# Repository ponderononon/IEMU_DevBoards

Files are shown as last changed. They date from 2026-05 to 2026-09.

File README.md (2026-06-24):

# IEMU Development Boards - Open-source Inertial Sensor for Biomechanics

Kicad Schematic Files for the BASE and SENSOR Development Boards
(Layout in Progress)

The Sensor is a 320g IMU with a magnetometer and NAND-Flash running on a nrf54l15-Module.
The Base works as the coordinator and charger for multiple sensors also utilizing the same Module.

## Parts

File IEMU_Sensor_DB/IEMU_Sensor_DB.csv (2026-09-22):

Reference | Qty | Value | DNP | Exclude from BOM | Exclude from Board | Footprint | Datasheet | Distributor Link 1 | Distributor Link 2 | LCSC | Manufacturer_Name | Manufacturer_Part_Number | Manufactuer_Name
BT101 | 1 | Battery_Cell |  |  |  | 0_Power:CoinCell_LIR1455_LBY2 | ~
C101,C105,C109,C110 | 4 | 1u |  |  |  | Capacitor_SMD:C_0402_1005Metric | https://www.lcsc.com/datasheet/C52923.pdf | https://www.mouser.de/ProductDetail/Samsung-Electro-Mechanics/CL05A105KA5NQNC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 | https://www.digikey.de/en/products/detail/samsung-electro-mechanics/CL05A105KA5NQNC/3887103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 | C52923 | Samsung Electro-Mechanics | CL05A105KA5NQNC
C102,C206 | 2 | 2u2 |  |  |  | Capacitor_SMD:C_0402_1005Metric | https://www.lcsc.com/datasheet/C12530.pdf | https://www.mouser.de/ProductDetail/Samsung-Electro-Mechanics/CL05A225MQ5NSNC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 | https://www.digikey.de/de/products/detail/samsung-electro-mechanics/CL05A225MQ5NSNC/3887129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 | C12530 | Samsung Electro-Mechanics | CL05A225MQ5NSNC
C103,C104,C203,C204,C205 | 5 | 100n |  |  |  | Capacitor_SMD:C_0402_1005Metric | https://www.lcsc.com/datasheet/C1525.pdf | https://www.mouser.de/ProductDetail/Samsung-Electro-Mechanics/CL05B104KO5NNNC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 | https://www.digikey.de/de/products/detail/samsung-electro-mechanics/CL05B104KO5NNNC/3886659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 | C1525 | Samsung Electro-Mechanics | CL05B104KO5NNNC
C106,C107,C108,C111,C112,C201 | 6 | 10u |  |  |  | Capacitor_SMD:C_0603_1608Metric | https://weblib.samsungsem.com/mlcc/mlcc-ec-data-sheet.do?partNumber=CL10A106MA8NRN | https://www.mouser.de/ProductDetail/Samsung-Electro-Mechanics/CL10A106MA8NRNC?qs=47mY1nHWefS2vFRvRJVTdQ%3D%3D | https://www.digikey.de/de/products/detail/samsung-electro-mechanics/CL10A106MA8NRNC/3887527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 | C96446 | Samsung Electro-Mechanics | CL10A106MA8NRNC
C202 | 1 | 3p7 |  |  |  | Capacitor_SMD:C_0402_1005Metric | https://pim.murata.com/asset/pim4/ceramicCapacitorSMD/GCM1555C1H3R7CA16-01A-EN_PDF_CERAMICCAPACITORSMD | https://www.mouser.de/ProductDetail/Murata-Electronics/GCM1555C1H3R7CA16D?qs=b6dFT0v%2Fxb8E2wVH%2FN5LwA%3D%3D | https://www.digikey.de/de/products/detail/murata-electronics/GCM1555C1H3R7CA16D/4903606 | C2189484 | Murata Electronics | GCM1555C1H3R7CA16D
D101,D102,D103,D106,D110 | 5 | ESD5Z5.0T1G |  |  |  | Diode_SMD:D_SOD-523_1 | https://www.onsemi.com/pdf/datasheet/esd5z2.5t1-d.pdf | https://www.mouser.de/ProductDetail/onsemi/ESD5Z5.0T1G?qs=OSf9jACorvYw3fDx1S8P6A%3D%3D | https://www.digikey.de/de/products/detail/onsemi/ESD5Z5-0T1G/1476609 | C82044 | onsemi | ESD5Z5.0T1G
D104,D105 | 2 | PMEG3010ESBYL |  |  |  | 0_Power:DIODFN100X60X30-2N | https://assets.nexperia.com/documents/data-sheet/PMEG3010ESB.pdf | https://www.mouser.de/ProductDetail/Nexperia/PMEG3010ESBYL?qs=bel5lzaZNxQfmakdfxrTkg%3D%3D | https://www.digikey.com/en/products/detail/nexperia-usa-inc/PMEG3010ESBYL/5981362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 | C458181 | Nexperia | PMEG3010ESBYL
D107,D108,D201,D202,D203,D204,D205 | 7 | ESD9L1P8 |  |  |  | Diode_SMD:D_SOD-882 | https://diotec.com/request/datasheet/esd9l1p8.pdf | https://www.mouser.de/ProductDetail/Diotec-Semiconductor/ESD9L1P8?qs=Wj%2FVkw3K%252BMA0y9lWemTHNw%3D%3D | https://www.digikey.de/de/products/detail/diotec-semiconductor/ESD9L1P8/22192876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 | C6244607 | Diotec Semiconductor | ESD9L1P8
D109 | 1 | LTST-C19HE1WT |  |  |  | 0_Feedback:LED_LTST-C19HE1WT | https://www.mouser.de/datasheet/3/281/1/LTST_C19HE1WT.pdf | https://www.mouser.de/ProductDetail/LITEON/LTST-C19HE1WT?qs=WAWaI72GHKxJLPArJA9%252BUw%3D%3D | https://www.digikey.de/de/products/detail/liteon/LTST-C19HE1WT/3198710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 | C458749 | Lite-On Inc. | LTST-C19HE1WT
D111 | 1 | TPD1E10B06DYAR |  |  |  | Diode_SMD:D_SOD-523 | https://www.ti.com/cn/lit/ds/symlink/tpd1e10b06.pdf?ts=1777972949387 | https://www.mouser.de/ProductDetail/Texas-Instruments/TPD1E10B06DYAR?qs=Rp5uXu7WBW9%2F66n97S3Kgw%3D%3D | https://www.digikey.com/en/products/detail/texas-instruments/TPD1E10B06DYAR/15853876 | C3712135 | Texas Instruments | TPD1E10B06DYAR
D301,D302 | 2 | D_Schottky_2A_40V_0603 |  |  |  | 0_Power:0603_DSN | https://jlcpcb.com/api/file/downloadByFileSystemAccessId/8588900416898158592 | https://www.mouser.de/ProductDetail/onsemi/NSR20F40NXT5G?qs=Tr3lMbyRyKlnDYqqgtCWgQ%3D%3D | https://www.digikey.de/de/products/detail/onsemi/NSR20F40NXT5G/4848728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 | C153761 | onsemi | NSR20F40NXT5G
D303,D304,D305,D306,D307 | 5 | LTST-C191KRKT |  |  |  | 0_Feedback:LTST-C191KRKT | https://jlcpcb.com/api/file/downloadByFileSystemAccessId/8588884075830513664 | https://www.mouser.de/ProductDetail/LITEON/LTST-C191KRKT?qs=BAIUz4Y8PJBLfOhzue0q%252BA%3D%3D | https://www.digikey.de/de/products/detail/liteon/LTST-C191KRKT/386837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 | C125099 | Lite-On Electronics | LTST-C191KRKT
J101 | 1 | USB4125-GF-A |  |  |  | 0_Connectors:GCT_USB4125-GF-A_REVA2 |  | https://www.mouser.de/ProductDetail/GCT/USB4125-GF-A?qs=KUoIvG%2F9IlaIQ4zBJ6gLeA%3D%3D | https://www.digikey.de/de/products/detail/gct/USB4125-GF-A/13547388 | C3151650 | Global Connector Technology | USB4125-GF-A
J102 | 1 | DF13-4P-1.25H(21) |  |  |  | 0_Connectors:DF13-4P-1.25H(21) | https://www.mouser.de/datasheet/3/731/1/DF13_Catalog_en_DF13_CAT.pdf | https://www.mouser.de/ProductDetail/Hirose-Connector/DF13-4P-1.25H21?qs=XQjbzJWzFPW%2FwtfCjCnzBg%3D%3D | https://www.digikey.de/de/products/detail/hirose-electric-co-ltd/DF13-4P-1-25H-21/444062 | C597872 | Hirose Electric | DF13-4P-1.25H(21)
J103,J104,J105 | 3 | ~ |  |  |  | 0_Connectors:SAMTEC_MTSW-101-X-X-D-X | https://www.mouser.de/datasheet/3/85/1/mtsw.pdf | https://www.mouser.de/ProductDetail/Samtec/MTSW-101-07-T-D-240?qs=rU5fayqh%252BE3di2bgKGhLZg%3D%3D |  |  | Samtec | MTSW-101-07-T-D-240
J201 | 1 | Conn_ARM_SWD_TagConnect_TC2030-NL |  | Excluded from BOM |  | Connector:Tag-Connect_TC2030-IDC-NL_2x03_P1.27mm_Vertical | https://www.tag-connect.com/wp-content/uploads/bsk-pdf-manager/TC2030-CTX_1.pdf
J301 | 1 | Conn_01x02_Pin |  | Excluded from BOM |  | Connector_Wire:SolderWire-0.5sqmm_1x02_P4.6mm_D0.9mm_OD2.1mm | ~
L101,L102 | 2 | 2u2 |  |  |  | Inductor_SMD:L_0603_1608Metric | https://www.mouser.com/catalog/specsheets/Taiyo%20Yuden_LSC01_e.pdf | https://www.mouser.de/ProductDetail/TAIYO-YUDEN/LSCNB1608HKT2R2MD?qs=tlsG%2FOw5FFjxb8Uw3ACZFA%3D%3D | https://www.digikey.de/de/products/detail/taiyo-yuden/LSCNB1608HKT2R2MD/16668097 | C6079477 | TAIYO YUDEN | LSCNB1608HKT2R2MD
M401 | 1 | VZ43FM1B8230001L |  |  |  | 0_Feedback:XDCR_VZ43FM1B8230001L | https://www.vybronics.com/wp-content/uploads/datasheet-files/Vybronics-VZ43FM1B8230001L-datasheet.pdf |  | https://www.digikey.de/de/products/detail/vybronics-inc/VZ43FM1B8230001L/12323592 | C7467059 | Vybronics | VZ43FM1B8230001L
MH301,MH302,MH303,MH304 | 4 | MountingHole_Pad |  | Excluded from BOM |  | MountingHole:MountingHole_2.2mm_M2_Pad_Via | ~
Q101 | 1 | CSD85301Q2 |  |  |  | 0_Power:CSD85301Q2 | http://www.ti.com/lit/gpn/csd85301q2 | https://www.mouser.de/ProductDetail/Texas-Instruments/CSD85301Q2?qs=jXf%2FRVhl83aWTrZoPmx2cQ%3D%3D | https://www.digikey.de/de/products/detail/texas-instruments/CSD85301Q2/5114820 | C544396 | Texas Instruments | CSD85301Q2
Q301,Q302,Q303,Q304 | 4 | CSD13381F4 |  |  |  | 0_Power:DFN100X60X35-3N | https://www.ti.com/lit/ds/symlink/csd13381f4.pdf | https://www.mouser.de/ProductDetail/Texas-Instruments/CSD13381F4?qs=OGNXFUZBARsOFU3S%252BJVO5g%3D%3D | https://www.digikey.com/en/products/detail/texas-instruments/CSD13381F4/4437947 | C179868 | Texas Instruments | CSD13381F4
R101,R206 | 2 | 10k |  |  |  | Resistor_SMD:R_0402_1005Metric | https://www.lcsc.com/datasheet/C25744.pdf | https://www.mouser.de/ProductDetail/Royalohm/0402WGF1002TCE?qs=e8oIoAS2J1T9%2FSfQTy4YqQ%3D%3D |  | C25744 | UNI-ROYAL(Uniroyal Elec) | 0402WGF1002TCE
R102,R103,R203,R204,R205 | 5 | 47k |  |  |  | Resistor_SMD:R_0402_1005Metric | https://www.royalohm.com/assets/pdf/products/smd/1.pdf | https://www.mouser.de/ProductDetail/Royalohm/0402WGF4702TCE?qs=e8oIoAS2J1Slykd2t52jeA%3D%3D |  | C25792 | UNI-ROYAL(Uniroyal Elec) | 0402WGF4702TCE
R104 | 1 | 330 |  |  |  | Resistor_SMD:R_0402_1005Metric | https://www.royalohm.com/assets/pdf/products/smd/1.pdf | https://www.mouser.de/ProductDetail/Royalohm/0402WGF3300TCE?qs=e8oIoAS2J1Sur8hPOE5m4w%3D%3D |  | C25104 | UNI-ROYAL(Uniroyal Elec) | 0402WGF3300TCE
R105,R106 | 2 | 5M1 |  |  |  | Resistor_SMD:R_0402_1005Metric | https://www.lcsc.com/datasheet/C137855.pdf | https://www.mouser.de/ProductDetail/YAGEO/RC0402JR-075M1L?qs=0yPvnVz5%2Fmq%2FK6XQD6hVkQ%3D%3D | https://www.digikey.de/de/products/detail/yageo/RC0402JR-075M1L/5281166 | C137855 | YAGEO | RC0402JR-075M1L
R107,R207,R208 | 3 | 2k2 |  |  |  | Resistor_SMD:R_0402_1005Metric | https://www.lcsc.com/datasheet/C25879.pdf | https://www.mouser.de/ProductDetail/Royalohm/0402WGF2201TCE?qs=e8oIoAS2J1QvBi%2FbAiHH2g%3D%3D |  | C25879 | UNI-ROYAL(Uniroyal Elec) | 0402WGF2201TCE
R108 | 1 | R_Shunt_1R |  |  |  | Resistor_SMD:R_0402_1005Metric | https://www.te.com/commerce/DocumentDelivery/DDEController?Action=srchrtrv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 | https://www.mouser.de/ProductDetail/TE-Connectivity-Holsworthy/RLP73K1E1R0FTDF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 | https://www.digikey.com/en/products/detail/te-connectivity-passive-product/RLP73K1E1R0FTDF/4031931 | C2074826 | TE Connectivity | RLP73K1E1R0FTDF
R109,R110,R201,R304,R305 | 5 | 1k |  |  |  | Resistor_SMD:R_0402_1005Metric | https://www.royalohm.com/assets/pdf/products/smd/1.pdf | https://www.mouser.de/ProductDetail/Royalohm/0402WGF1001TCE?qs=e8oIoAS2J1RlrMC0w7DkrQ%3D%3D |  | C11702 | UNI-ROYAL(Uniroyal Elec) | 0402WGF1001TCE
R111 | 1 | 510k |  |  |  | Resistor_SMD:R_0603_1608Metric | https://jlcpcb.com/api/file/downloadByFileSystemAccessId/8579706282724544512 | https://www.mouser.de/ProductDetail/Royalohm/0603WAF5103T5E?qs=e8oIoAS2J1SG1joTiM6RHg%3D%3D |  | C23192 | UNI-ROYAL(Uniroyal Elec) | 0603WAF5103T5E
R112,R209 | 2 | 1M |  |  |  | Resistor_SMD:R_0402_1005Metric | https://jlcpcb.com/api/file/downloadByFileSystemAccessId/8579705944068186112 | https://www.mouser.de/ProductDetail/Royalohm/0402WGF1004TCE?qs=e8oIoAS2J1Sm8qYhjADD%252Bg%3D%3D |  | C26083 | UNI-ROYAL(Uniroyal Elec) | 0402WGF1004TCE
R202 | 1 | 22R |  |  |  | Resistor_SMD:R_0603_1608Metric | https://www.royalohm.com/assets/pdf/products/smd/1.pdf | https://www.mouser.de/ProductDetail/Royalohm/0603WAF220JT5E?qs=e8oIoAS2J1QaFtl9BkMMvg%3D%3D |  | C23345 | UNI-ROYAL(Uniroyal Elec) | 0603WAF220JT5E
R301,R302,R303 | 3 | 330R |  |  |  | Resistor_SMD:R_0402_1005Metric | https://www.royalohm.com/assets/pdf/products/smd/1.pdf | https://www.mouser.de/ProductDetail/Royalohm/0402WGF3300TCE?qs=e8oIoAS2J1Sur8hPOE5m4w%3D%3D |  | C25104 | UNI-ROYAL(Uniroyal Elec) | 0402WGF3300TCE
SW301 | 1 | NANOT_160_BP |  |  |  | 0_Feedback:NANOT160BP | https://www.littelfuse.com/assetdocs/littelfuse-ck-tactile-nanot-series-datasheet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 |  | https://www.digikey.com/en/products/detail/c-k/NANOT-160-BP/13182296 | C2760983 | C&K | NANOT160BP
SW302 | 1 | TS-1088-AR02016 |  |  |  | 0_Feedback:SW_TS-1088-AR02016 | https://jlcpcb.com/api/file/downloadByFileSystemAccessId/8588886944068096000 |  |  | C720477 | Xunpu | TS-1088-AR02016
TP101,TP102,TP103,TP104,TP105,TP106,TP107,TP108,TP109,TP110,TP111,TP112,TP113,TP114,TP201,TP202,TP203,TP204,TP205,TP206,TP207,TP208,TP209,TP301,TP302,TP303,TP304 | 27 | ~ |  |  |  | TestPoint:TestPoint_Pad_D1.0mm | ~
U101 | 1 | NPM1304-QEAA-R7 |  |  |  | 0_Power:QFN50P500X500X90-33N | https://docs-be.nordicsemi.com/bundle/ps_npm1304/page/pdf/nPM1304_Datasheet_v1.0.pdf | https://eu.mouser.com/ProductDetail/Nordic-Semiconductor/NPM1304-QEAA-R7?qs=HMhDvBYWqvMvY7CcdLXd6A%3D%3D | https://www.digikey.de/de/products/detail/nordic-semiconductor-asa/NPM1304-QEAA-R7/27258987 | C49448846 | Nordic Semiconductor | NPM1304-QEAA-R7
U102 | 1 | BQ29702DSER |  |  |  | Package_SON:WSON-6_1.5x1.5mm_P0.5mm | https://www.ti.com/lit/ds/symlink/bq2972.pdf?ts=1774781812663 | https://www.mouser.de/ProductDetail/Texas-Instruments/BQ29702DSER?qs=m1T3c8F5IUKBpJHU0Ofy6w%3D%3D | https://www.digikey.de/de/products/detail/texas-instruments/BQ29702DSER/4899787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 | C2872632 | Texas Instruments | BQ29702DSER
U103 | 1 | TLV75530PDRVR |  |  |  | Package_SON:WSON-6-1EP_2x2mm_P0.65mm_EP1x1.6mm_ThermalVias | https://www.ti.com/lit/ds/symlink/tlv755p.pdf?ts=1775941132628 | https://www.mouser.de/ProductDetail/Texas-Instruments/TLV75530PDRVR?qs=lc2O%252BfHJPVbdo827uajLog%3D%3D | https://www.digikey.com/en/products/detail/texas-instruments/TLV75530PDRVR/9649791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 | C2859948 | Texas Instruments | TLV75530PDRVR
U104 | 1 | INA216A2RSWR |  |  |  | Package_DFN_QFN:Texas_RSW0010A_UQFN-10_1.4x1.8mm_P0.4mm | https://www.ti.com/lit/ds/symlink/ina216.pdf | https://www.mouser.de/ProductDetail/Texas-Instruments/INA216A2RSWR?qs=NUb82WqeCyoQa96oQgyXng%3D%3D | https://www.digikey.com/en/products/detail/texas-instruments/INA216A2RSWR/2782696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 | C2653823 | Texas Instruments | INA216A2RSWR
U201 | 1 | Ezurio BL54L15 |  |  |  | 0_MCU:BL54L15 | https://www.ezurio.com/documentation/datasheet-bl54l10-and-bl54l15-series | https://mouser.com/ProductDetail/Ezurio/453-00001C?qs=a2MtRaTmNOR8OxAR96ozSQ%3D%3D | https://www.digikey.de/de/products/detail/ezurio/453-00001R/26224840?s=N4IgTCBcDaICwFYDMBaADBtBGAwiAugL5A |  | EZURIO | 453-00001C
U202 | 1 | W25N02JWZEIF |  |  |  | 0_Memory:IC_W25N04KVZEIR | https://www.winbond.com/resource-files/W25N02JW_RevA_191118.pdf | https://www.mouser.de/ProductDetail/Winbond/W25N02JWZEIF?qs=T3oQrply3y%2FzgvrcpLTu6Q%3D%3D | https://www.digikey.com/en/products/detail/winbond-electronics/W25N02JWZEIF/12143373 | C2962014 | Winbond | W25N02JWZEIF
U203 | 1 | LSM6DSV320XTR |  |  |  | Package_LGA:LGA-14_3x2.5mm_P0.5mm_LayoutBorder3x4y | https://www.st.com/resource/en/datasheet/lsm6dsv320x.pdf | https://www.mouser.de/ProductDetail/STMicroelectronics/LSM6DSV320XTR?qs=ZcfC38r4PovtVvaAitDAYA%3D%3D | https://www.digikey.de/de/products/detail/stmicroelectronics/lsm6dsv320xtr/26254547 | C26633007 | STMicroelectronics | LSM6DSV320XTR
U204 | 1 | MMC5603NJ |  |  |  | 0_Sensors:MMC5603NJ | https://www.memsic.com/Public/Uploads/uploadfile/files/20220119/MMC5603NJDatasheetRev.B.pdf | https://www.mouser.de/ProductDetail/MEMSIC/MMC5603NJ?qs=B6kkDfuK7%2FDOubZFFHvcXw%3D%3D | https://www.digikey.de/de/products/detail/memsic-inc/MMC5603NJ/10452796 | C404328 | MEMSIC | MMC5603NJ
Y201 | 1 | 32.768kHz |  |  |  | Crystal:Crystal_SMD_3215-2Pin_3.2x1.5mm | https://mm.digikey.com/Volume0/opasdata/d220001/medias/docus/7329/SC-32S.pdf |  | https://www.digikey.com/en/products/detail/seiko-instruments/SC32S-9PF20PPM/15296600 | C97605 | Seiko | SC-32S32.768kHz20PPM9pF

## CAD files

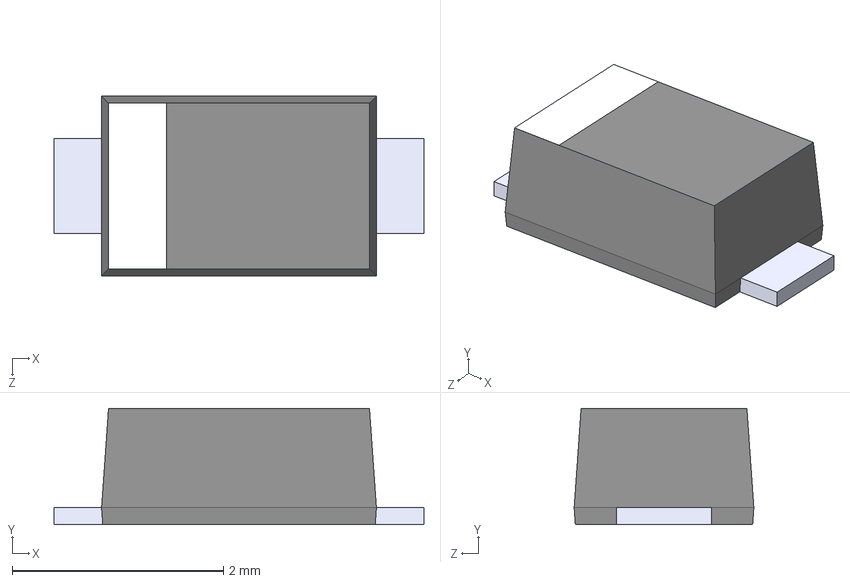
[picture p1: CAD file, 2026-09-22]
IEMU_Shared_Libraries/3D/PMEG3010ER-115--3DModel-STEP-56544.STEP
3.50 x 1.10 x 1.70 mm

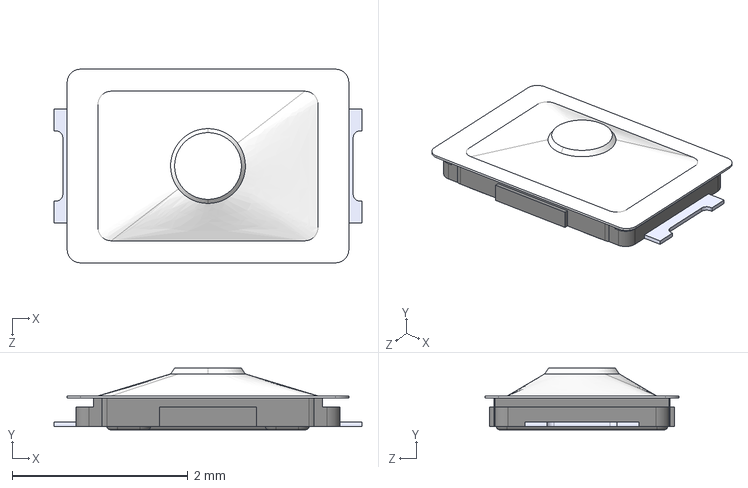
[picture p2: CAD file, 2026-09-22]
IEMU_Shared_Libraries/3D/EVP-AWED4A.step
3.50 x 0.7 x 2.20 mm

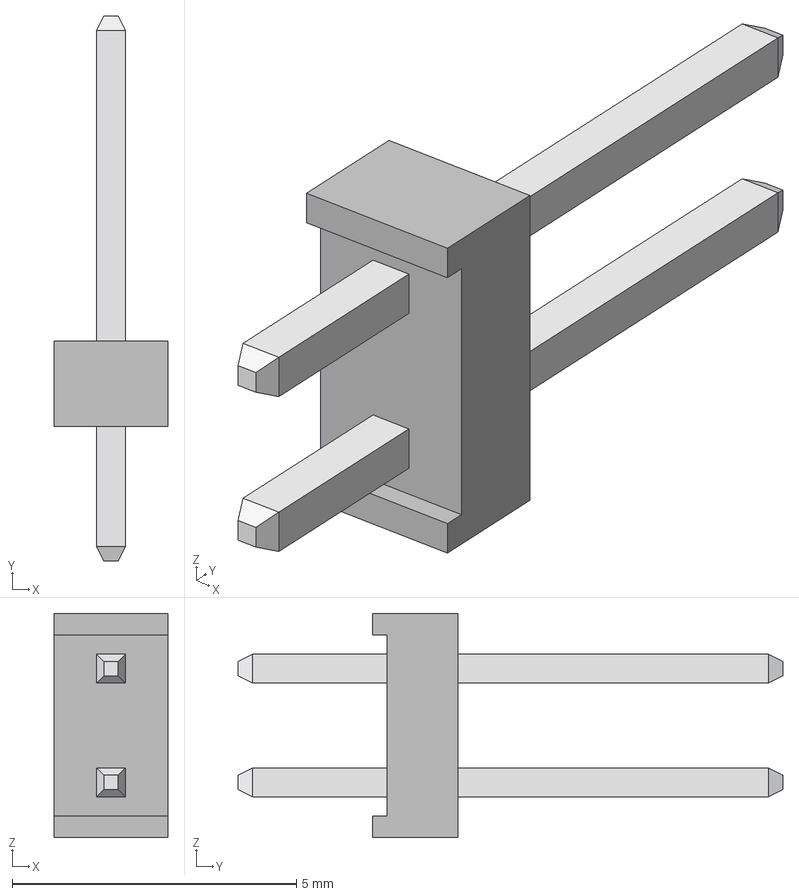
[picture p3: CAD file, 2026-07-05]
IEMU_Shared_Libraries/3D/MTMM-101-05-T-D-225.stp
2.00 x 9.58 x 3.94 mm
MTMM-101-05-T-D-225_pins
MTMM-101-05-T-D-225_body

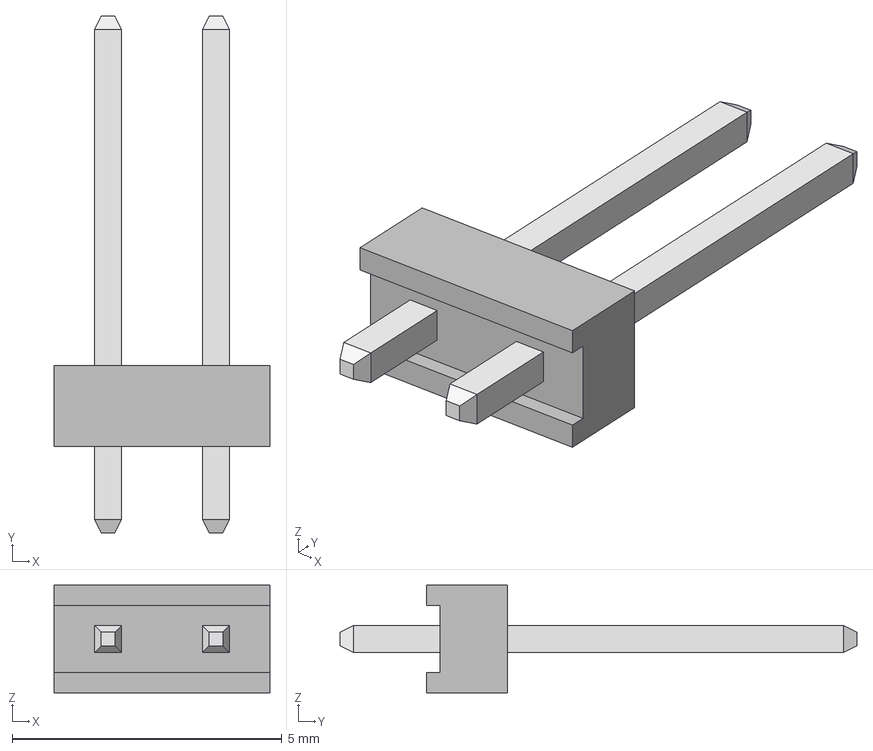
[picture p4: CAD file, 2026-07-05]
IEMU_Shared_Libraries/3D/MTMM-102-05-T-S-255.stp
4.00 x 9.58 x 2.00 mm
MTMM-102-05-T-S-255_pins
MTMM-102-05-T-S-255_body

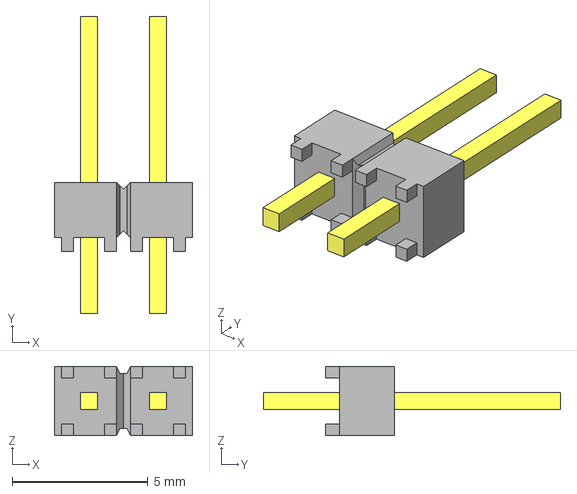
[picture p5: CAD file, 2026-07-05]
IEMU_Shared_Libraries/3D/MTSW-102-07-G-S-240.step
5.08 x 10.9 x 2.54 mm
MTSW-102-07-G-S-240_body
MTSW-102-07-S-240

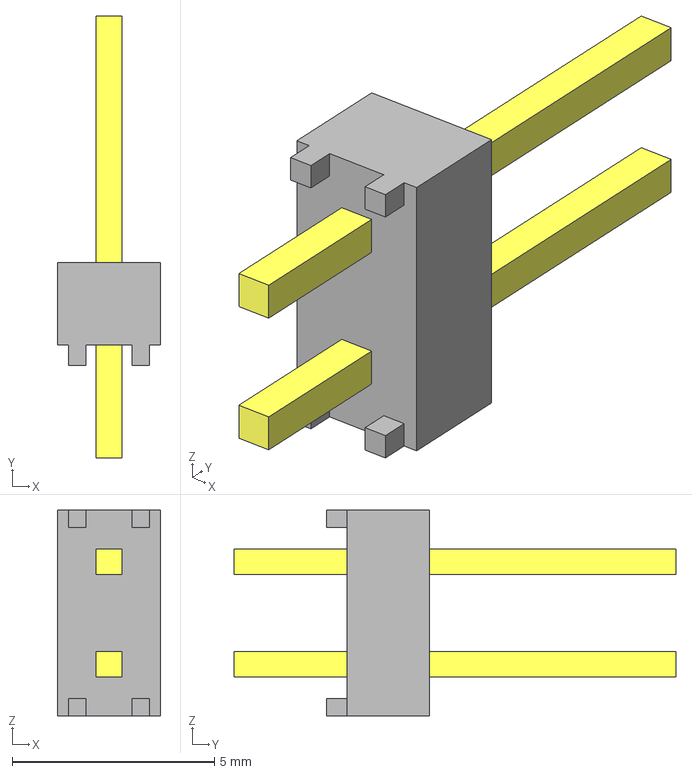
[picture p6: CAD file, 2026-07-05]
IEMU_Shared_Libraries/3D/MTSW-101-07-T-D-240.stp
2.54 x 10.9 x 5.08 mm
MTSW-101-07-T-D-240_body
MTSW-101-07-D-240

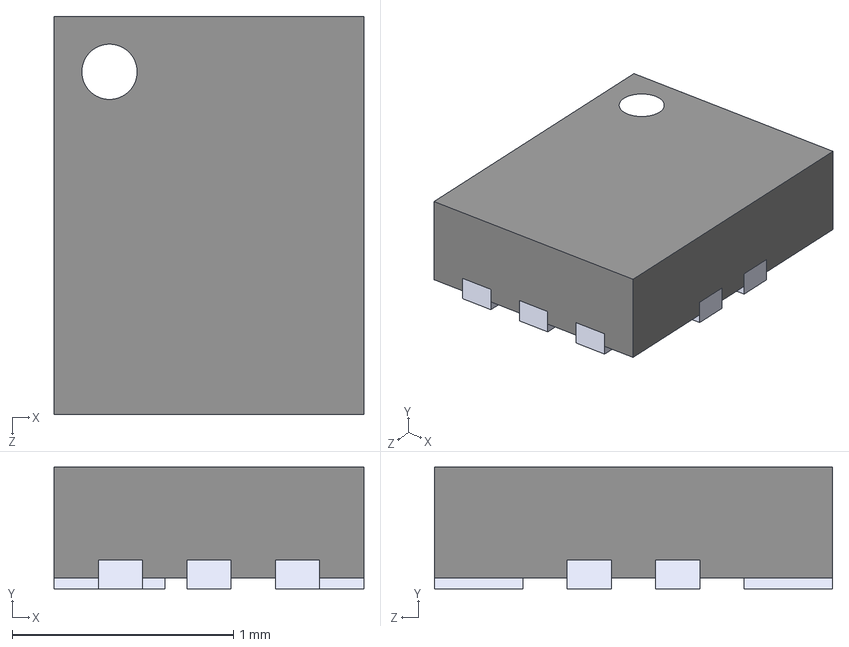
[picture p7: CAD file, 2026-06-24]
IEMU_Shared_Libraries/3D/INA216A2RSWR.STEP
1.40 x 0.55 x 1.80 mm

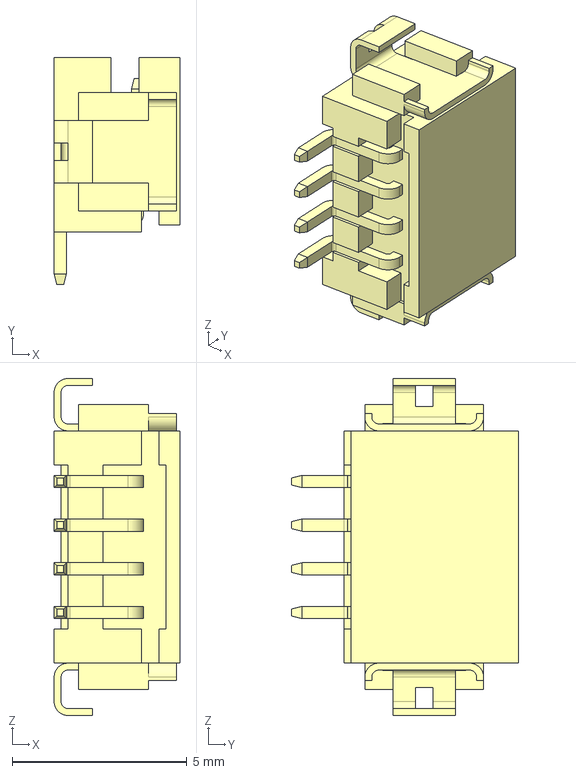
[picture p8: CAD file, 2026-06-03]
IEMU_Shared_Libraries/3D/DF13-4P-1.25H_21_.stp
3.60 x 6.50 x 9.65 mm

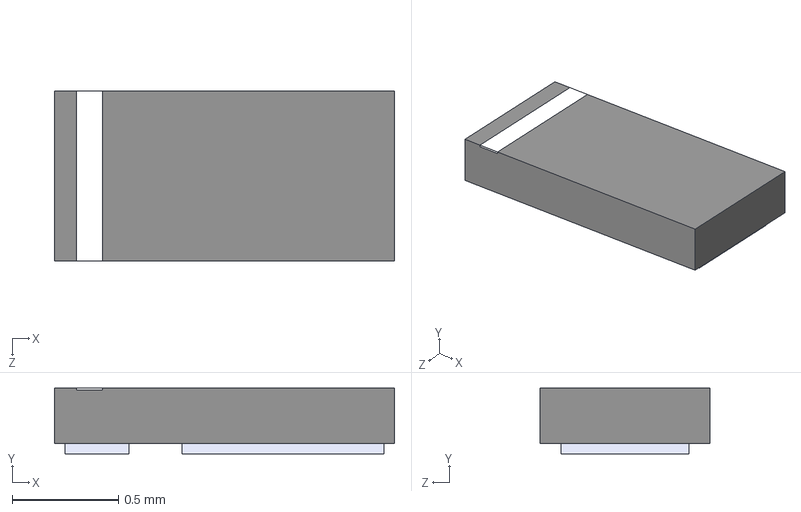
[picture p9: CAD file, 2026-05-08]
IEMU_Shared_Libraries/3D/NSR20F40NXT5G.STEP
1.60 x 0.31 x 0.8 mm

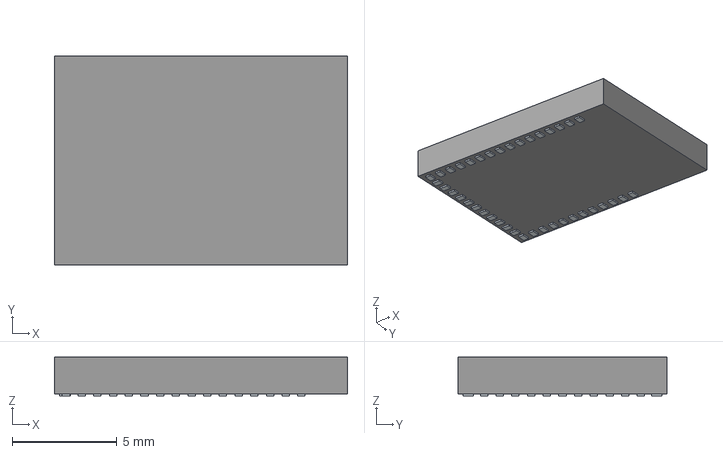
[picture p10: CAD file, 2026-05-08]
IEMU_Shared_Libraries/3D/453-00001C.stp
14.0 x 10.0 x 1.85 mm
Pins

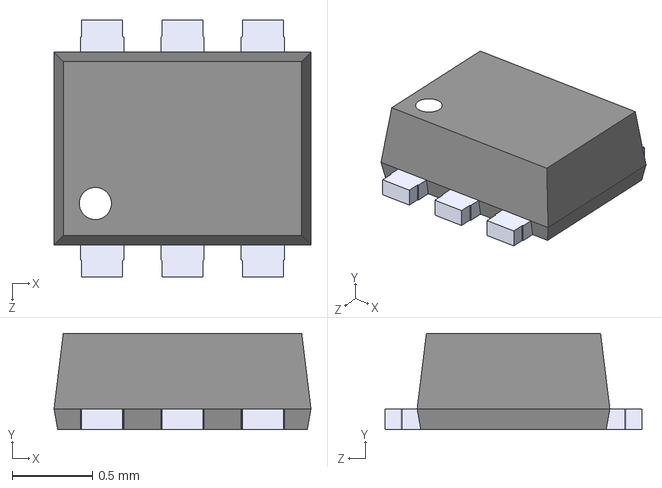
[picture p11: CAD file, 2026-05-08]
IEMU_Shared_Libraries/3D/USBLC6-2P6.step
1.60 x 0.6 x 1.60 mm

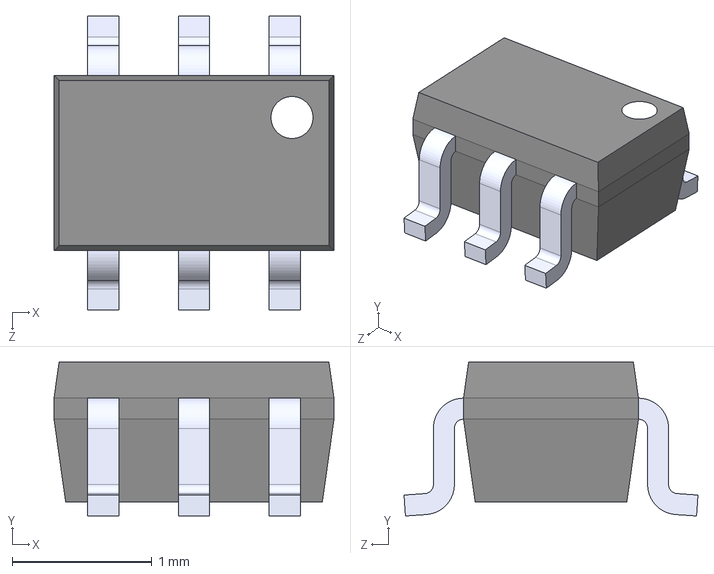
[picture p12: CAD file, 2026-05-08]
IEMU_Shared_Libraries/3D/SN74LVC1T45DCKRG4.step
2.00 x 1.10 x 2.10 mm

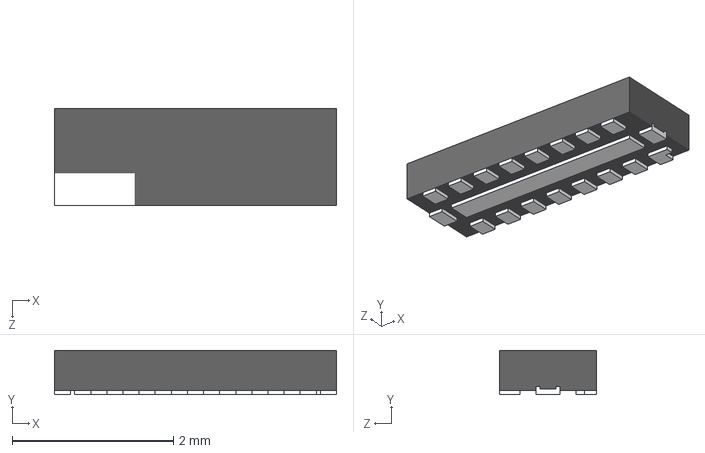
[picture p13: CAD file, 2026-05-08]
IEMU_Shared_Libraries/3D/EMIF06-MSD02N16.stp
3.50 x 0.55 x 1.20 mm

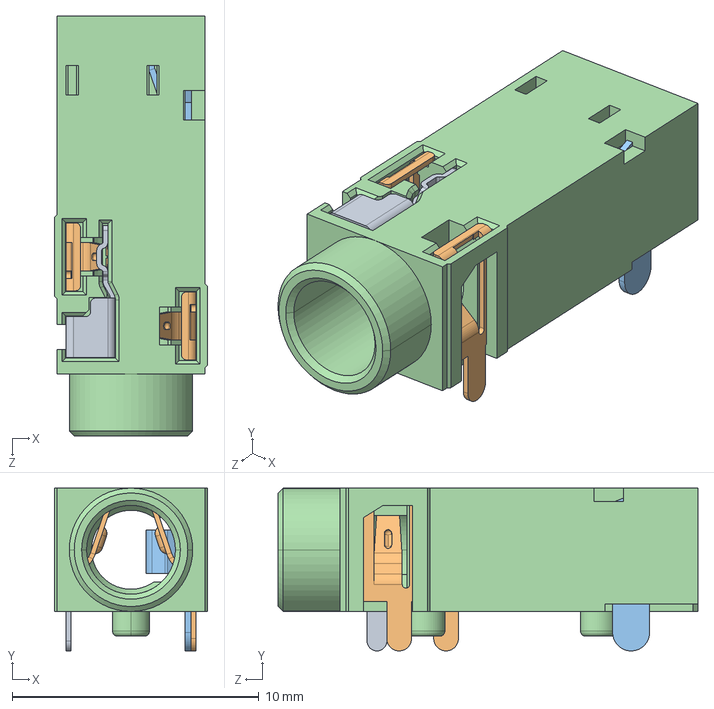
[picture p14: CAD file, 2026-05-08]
IEMU_Shared_Libraries/3D/SJ3-35083C-TR.step
6.20 x 6.60 x 17.0 mm

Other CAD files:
IEMU_Shared_Libraries/3D/MTSW-102-07-L-S-189.stp
IEMU_Shared_Libraries/3D/MTSW-102-07-L-S-240.stp
IEMU_Shared_Libraries/3D/TMUX1204DQAR.step
IEMU_Shared_Libraries/3D/SJ3-35083B-TR.step
IEMU_Shared_Libraries/3D/503398-1892.step
IEMU_Shared_Libraries/3D/BQ29702DSER.step
IEMU_Shared_Libraries/3D/CSD13381F4.step
IEMU_Shared_Libraries/3D/CSD85301Q2.STEP
IEMU_Shared_Libraries/3D/DF13-4P-1.25H_75_.step
IEMU_Shared_Libraries/3D/LTST-C191KRKT.step
IEMU_Shared_Libraries/3D/LTST-C19HE1WT.step
IEMU_Shared_Libraries/3D/MMC5603NJ.stp
IEMU_Shared_Libraries/3D/NANOT160BP.stp
IEMU_Shared_Libraries/3D/NPM1304-QEAA-R7.step
IEMU_Shared_Libraries/3D/PMEG3010ESBYL.step
IEMU_Shared_Libraries/3D/TS-1088-AR02016.step
IEMU_Shared_Libraries/3D/USB4125-GF-A_REVA2.step
IEMU_Shared_Libraries/3D/USB4215-03-A.stp
IEMU_Shared_Libraries/3D/VZ43FM1B8230001L.step
IEMU_Shared_Libraries/3D/W25N04KVZEIR.step

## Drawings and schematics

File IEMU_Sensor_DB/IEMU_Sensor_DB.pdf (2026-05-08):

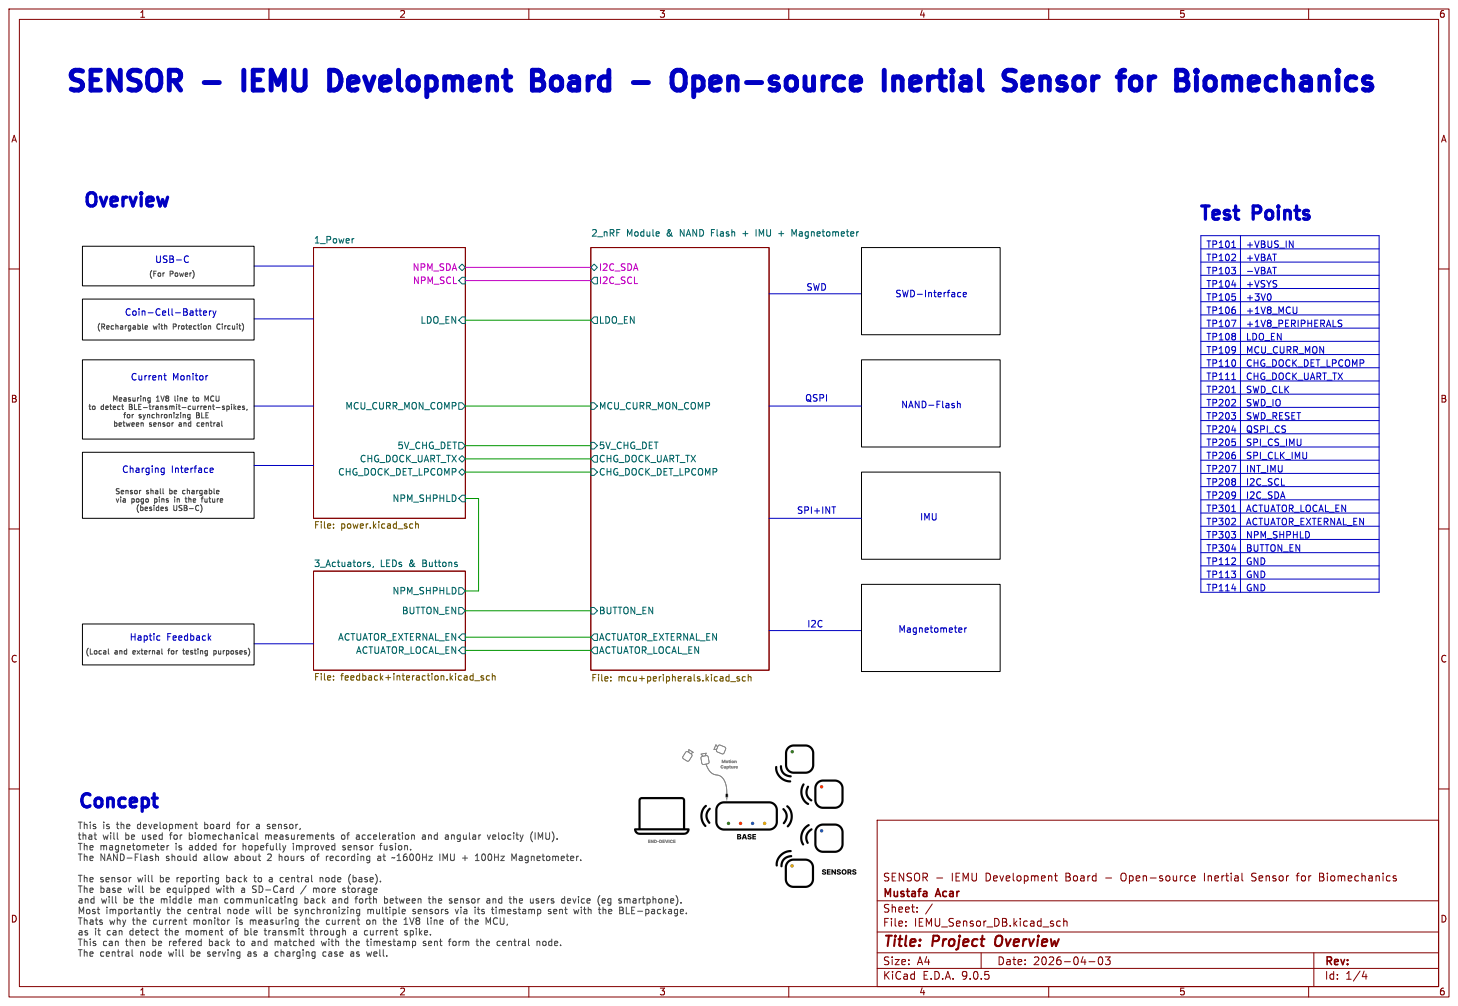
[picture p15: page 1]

2_nRF Module & NAND Flash + IMU + Magnetometer File: mcu+peripherals.kicad_sch NPM_SHPHLD

between sensor and central Current Monitor Sensor shall be chargable

to detect BLE-transmit-current-spikes,

via pogo pins in the future

Id: 1/4 Title: Project Overview

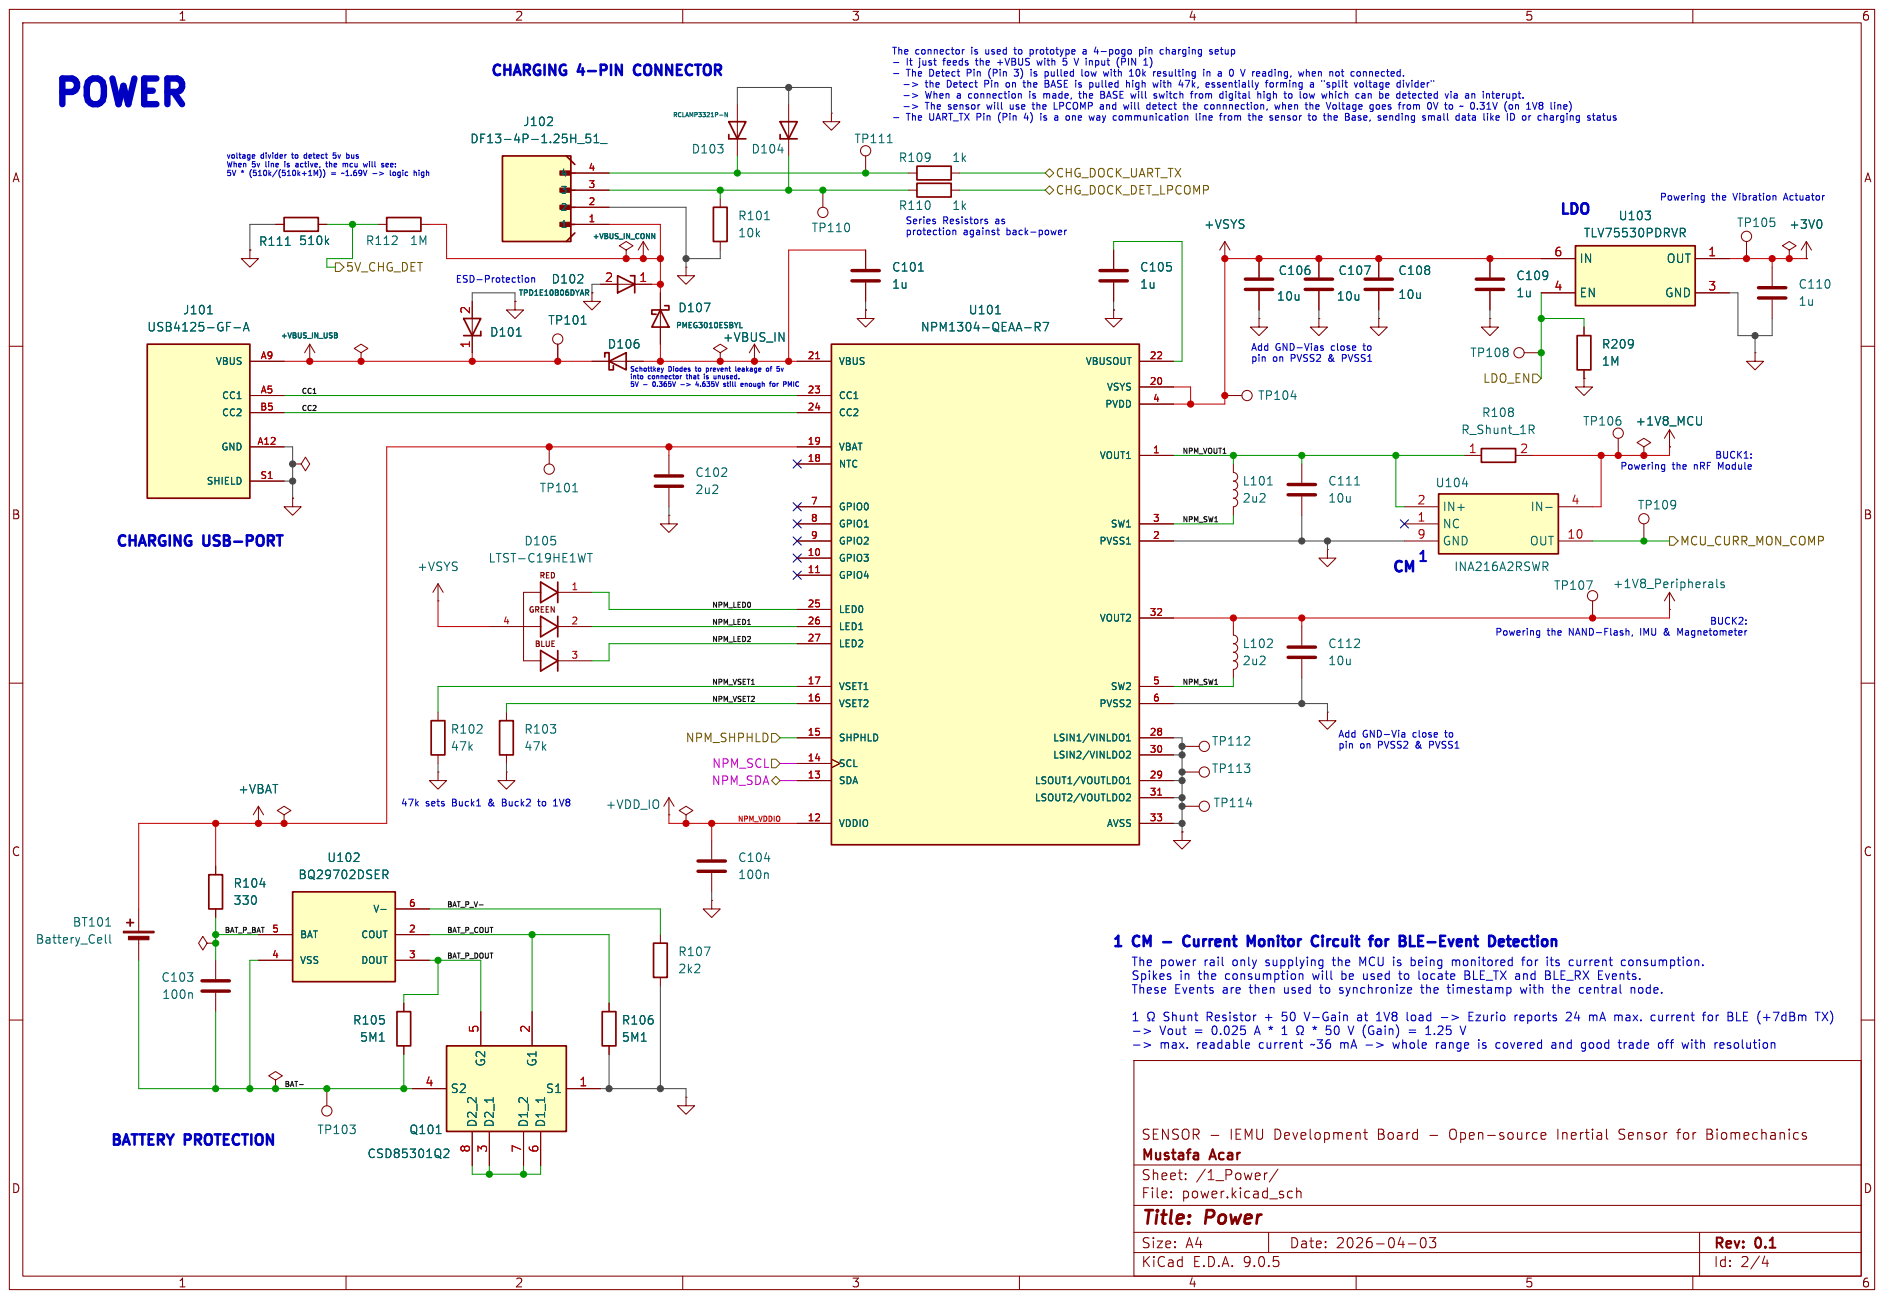
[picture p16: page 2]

- It just feeds the +VBUS with 5 V input (PIN 1)

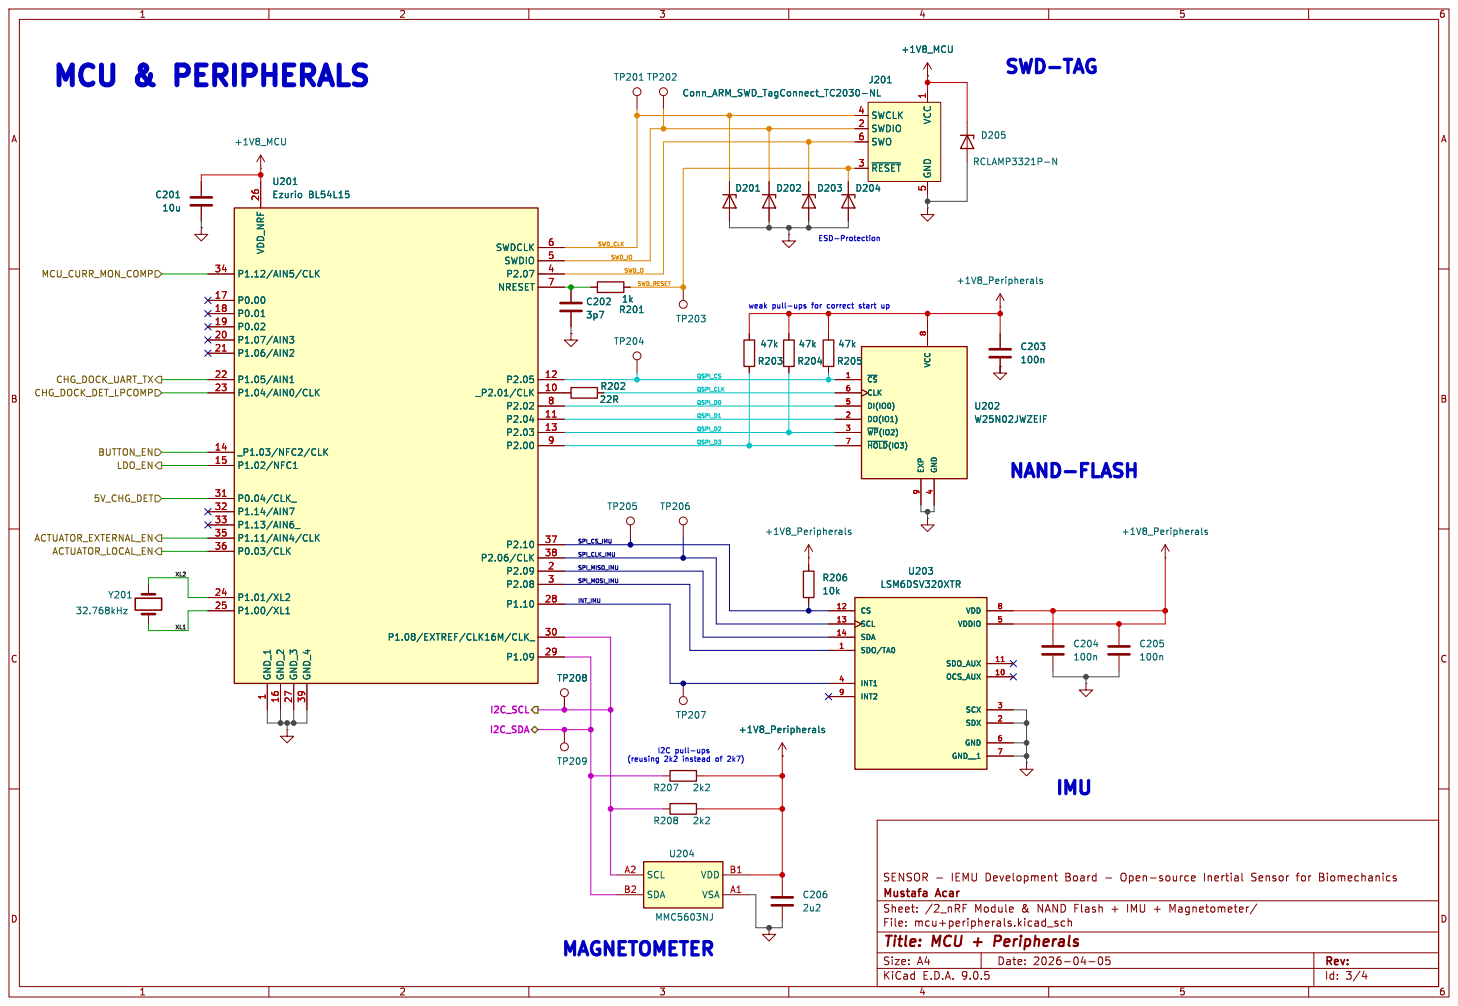
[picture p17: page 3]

5 SWCLK 4 SWDIO 2 SWO 6 ~{RESET} 3 +1V8_MCU

5 SWCLK 4 SWDIO 2 SWO 6 ~{RESET} 3

8 ~{CS} 1 CLK 6 DI(IO0) 5 DO(IO1) 2 ~{WP}(IO2) 3 ~{HOLD}(IO3) 7 GND

Id: 3/4 Title: MCU + Peripherals

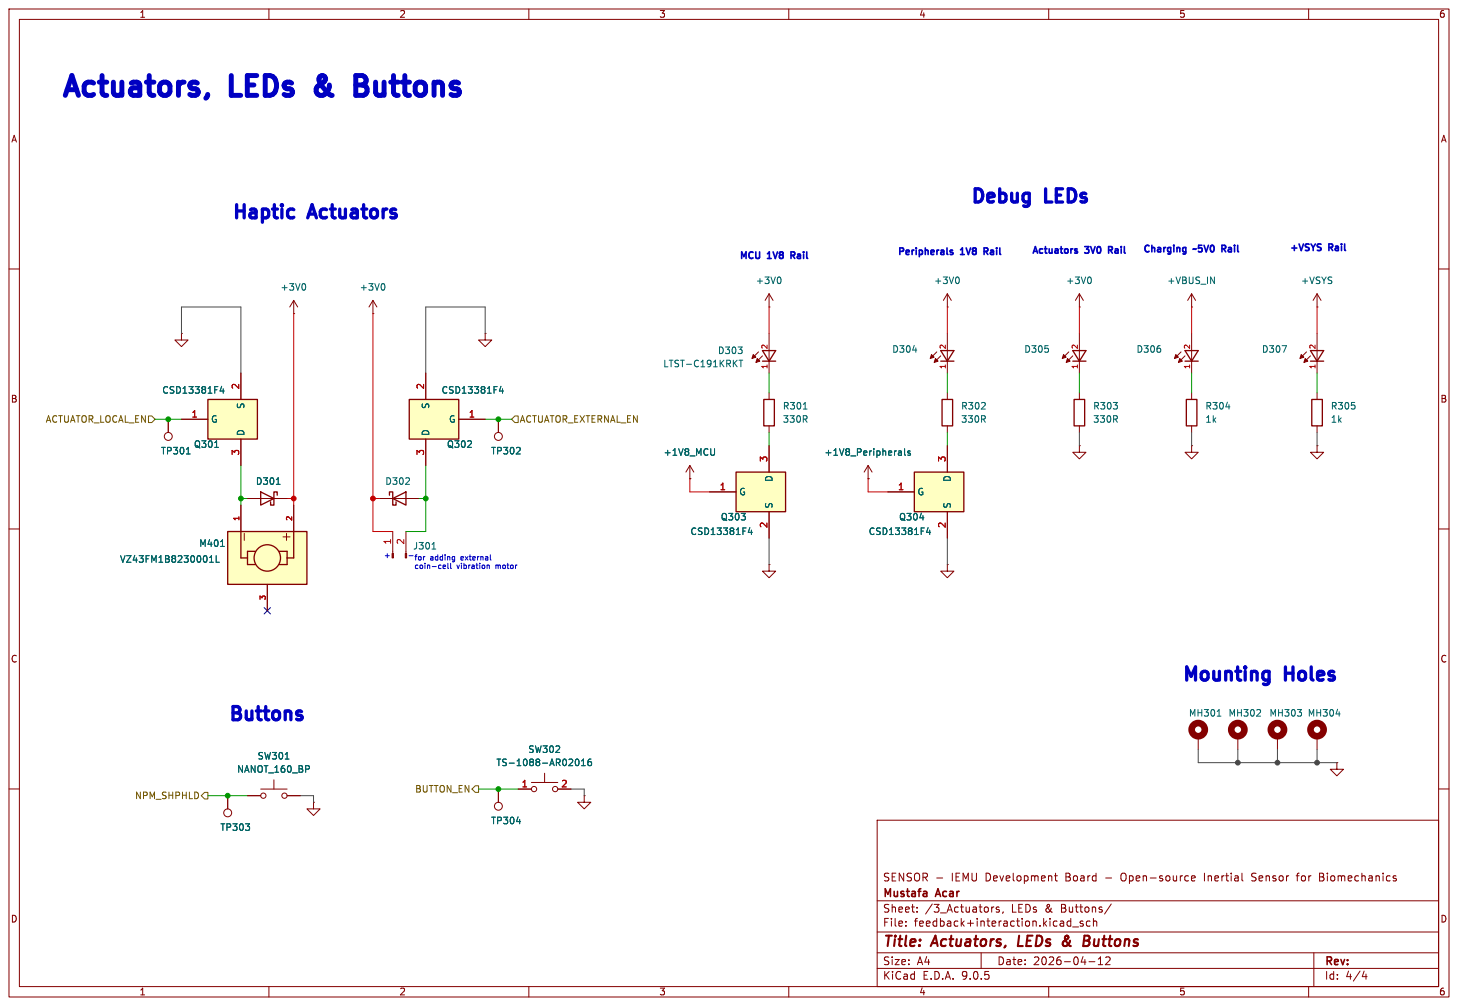
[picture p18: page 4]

Actuators 3V0 Rail Haptic Actuators

- Charging ~5V0 Rail Mounting Holes

Id: 4/4 Title: Actuators, LEDs & Buttons

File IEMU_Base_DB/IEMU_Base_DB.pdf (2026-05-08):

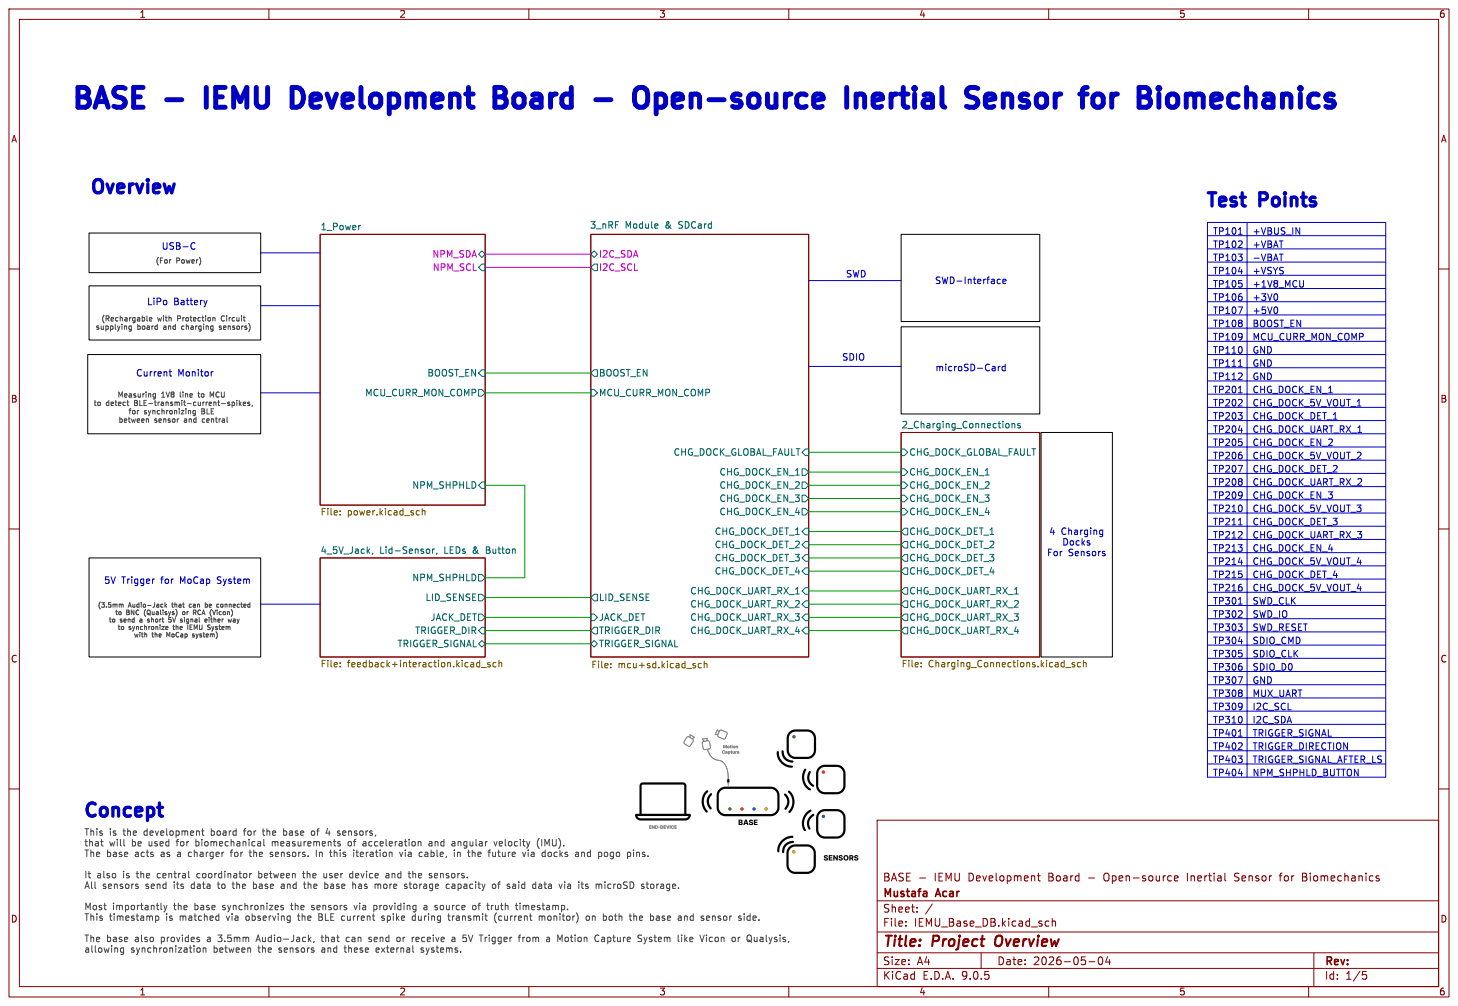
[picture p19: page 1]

3_nRF Module & SDCard File: mcu+sd.kicad_sch NPM_SHPHLD

to detect BLE-transmit-current-spikes,

between sensor and central 5V Trigger for MoCap System

with the MoCap system) Concept

Id: 1/5 Title: Project Overview

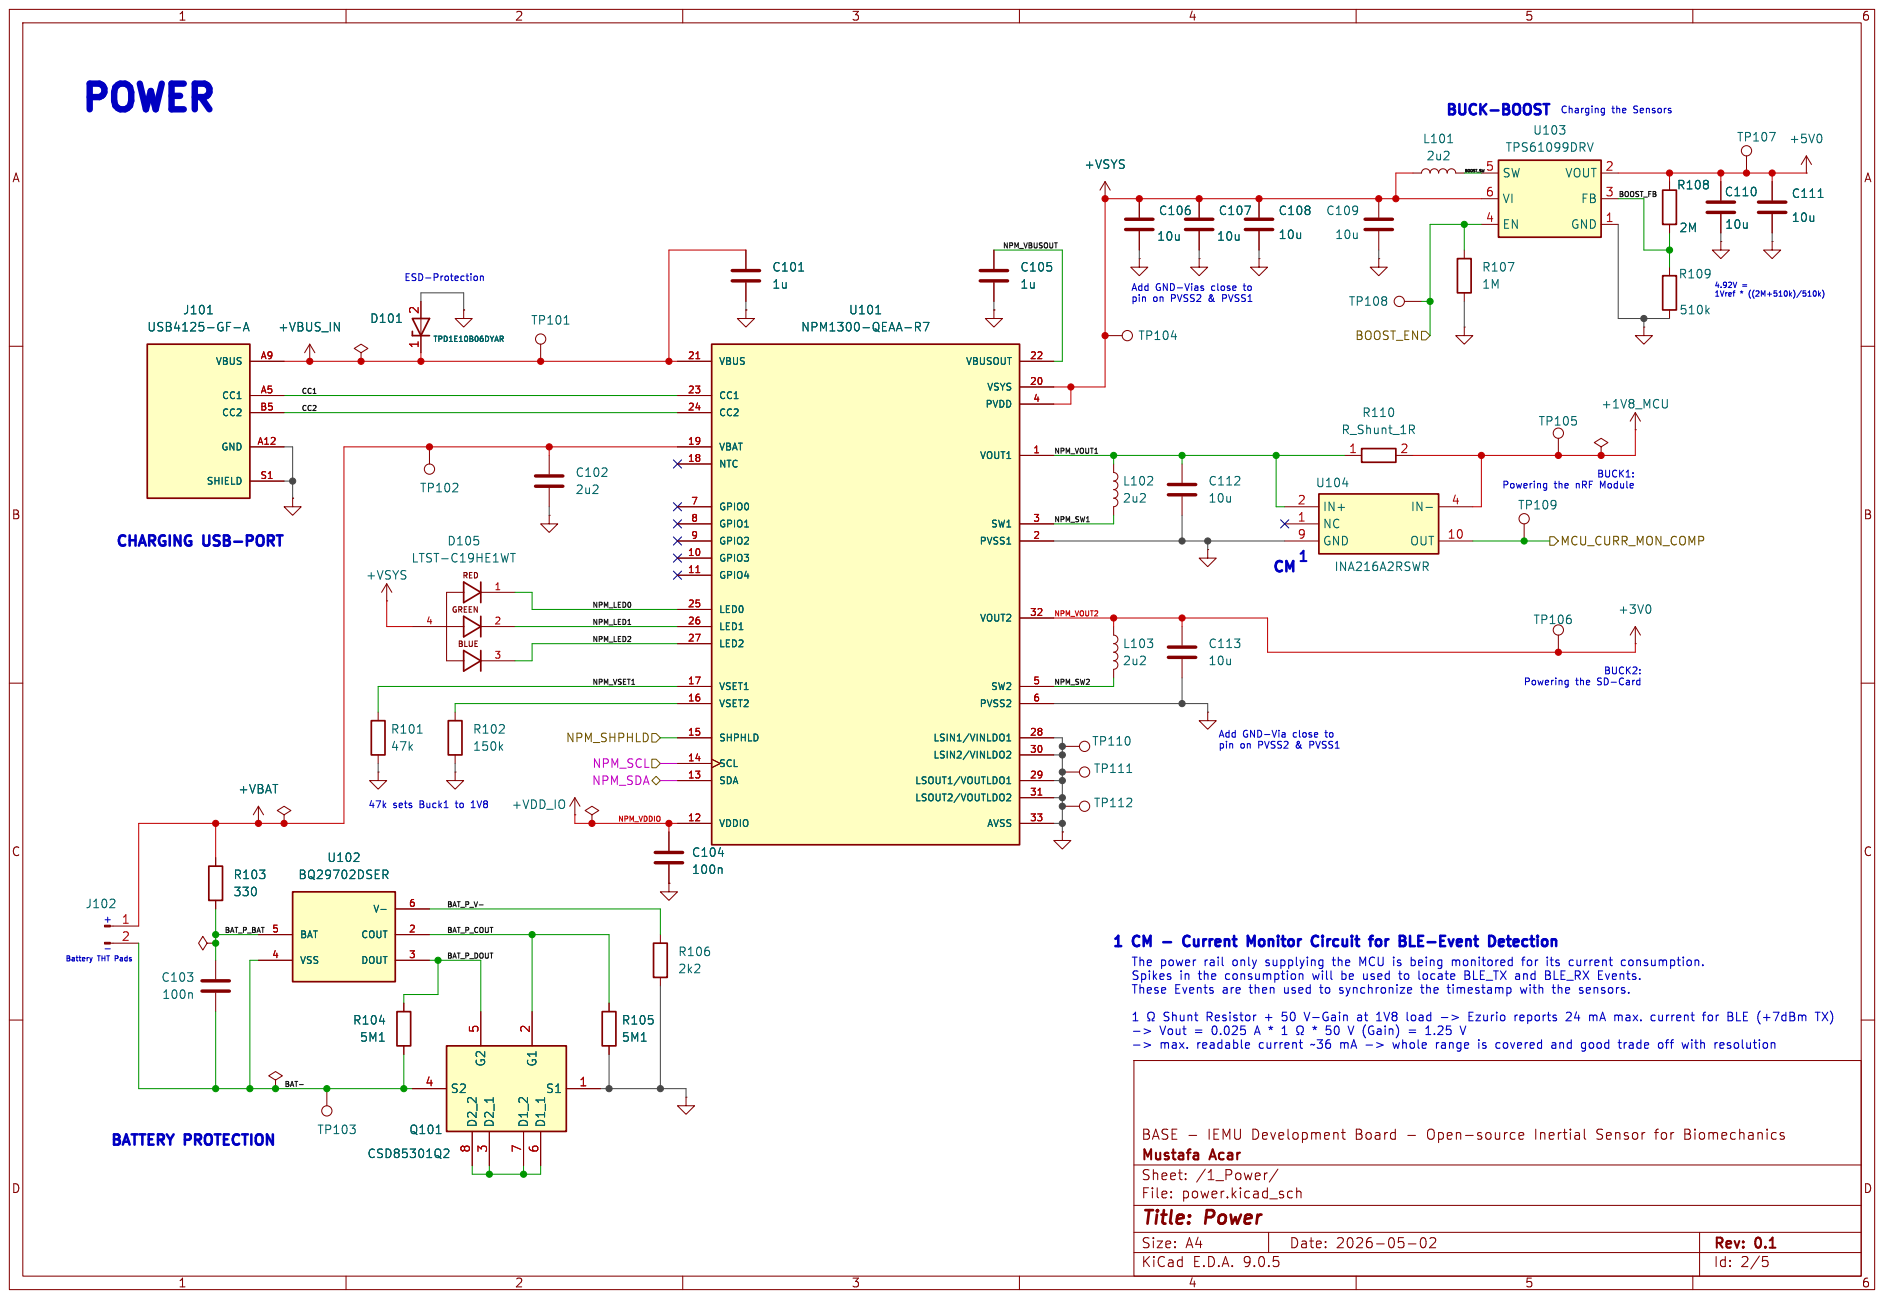
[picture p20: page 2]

pin on PVSS2 & PVSS1 CHARGING USB-PORT

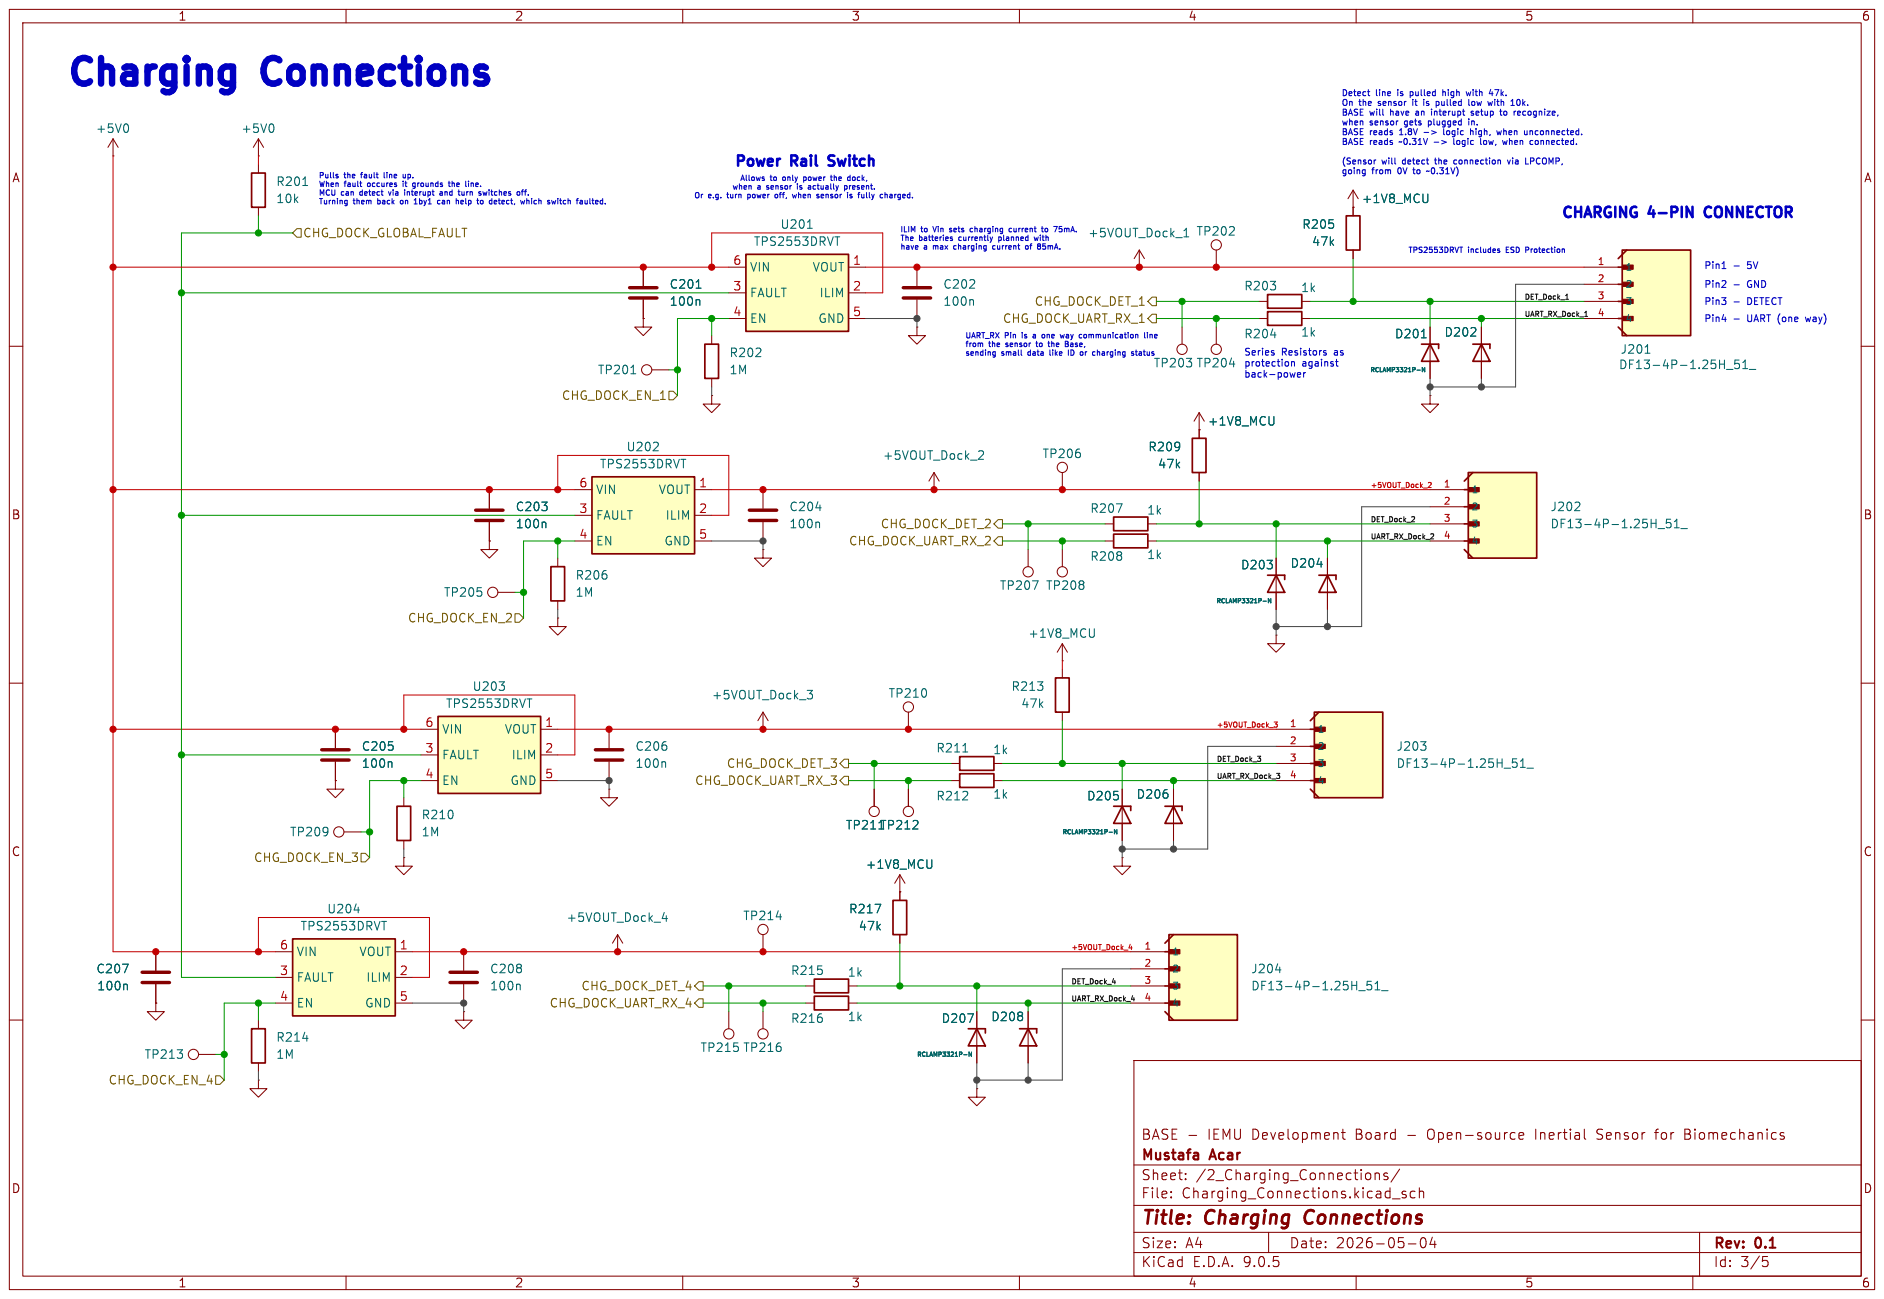
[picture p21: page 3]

Id: 3/5 Title: Charging Connections

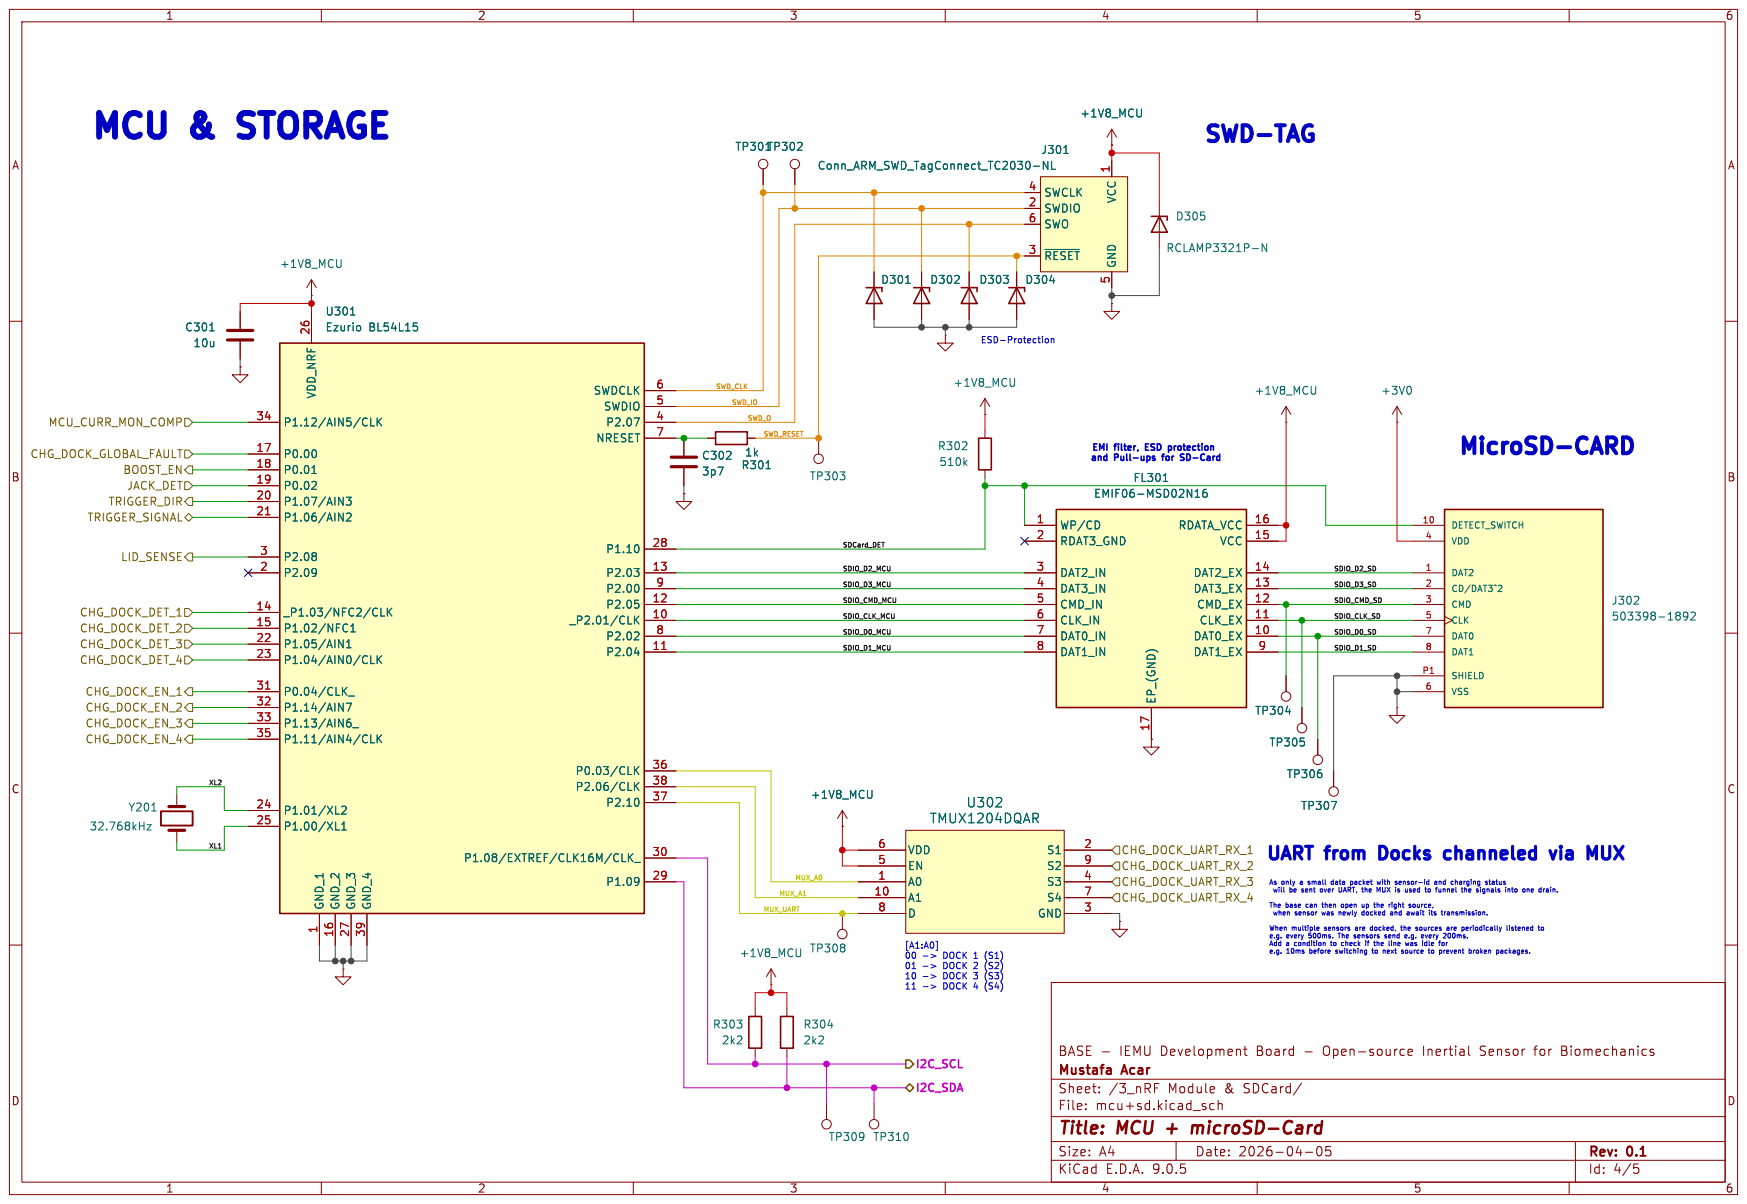
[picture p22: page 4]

ESD-Protection MCU & STORAGE

5 SWCLK 4 SWDIO 2 SWO 6 ~{RESET} 3D304 C302

5 SWCLK 4 SWDIO 2 SWO 6 ~{RESET} 3

Id: 4/5 Title: MCU + microSD-Card

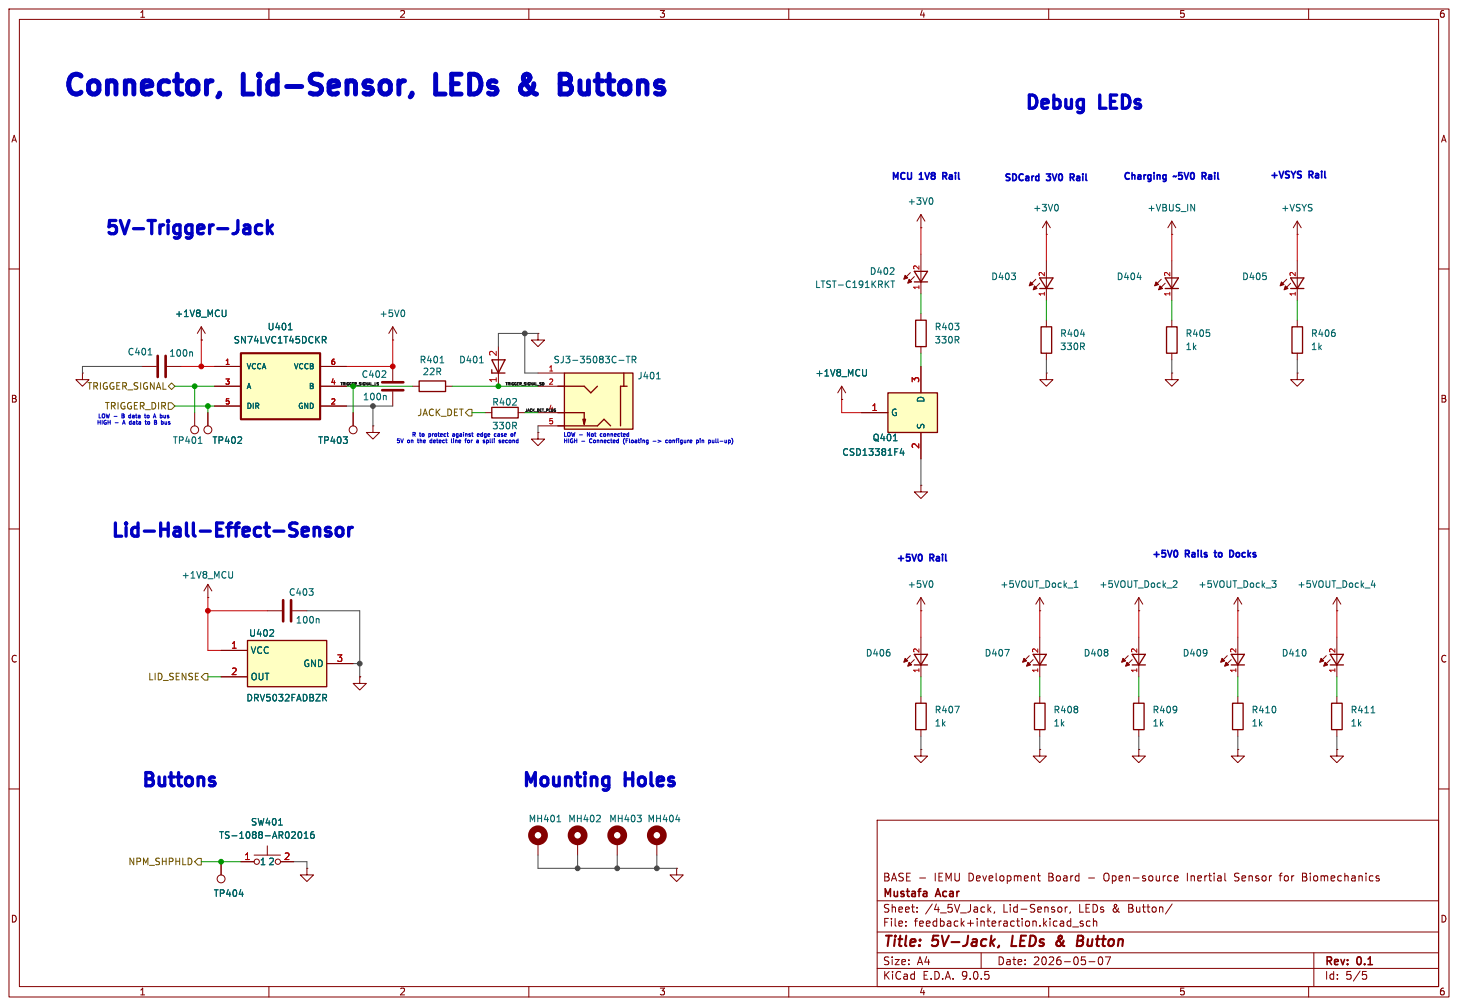
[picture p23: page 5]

LOW - B data to A bus HIGH - A data to B bus 5V-Trigger-Jack

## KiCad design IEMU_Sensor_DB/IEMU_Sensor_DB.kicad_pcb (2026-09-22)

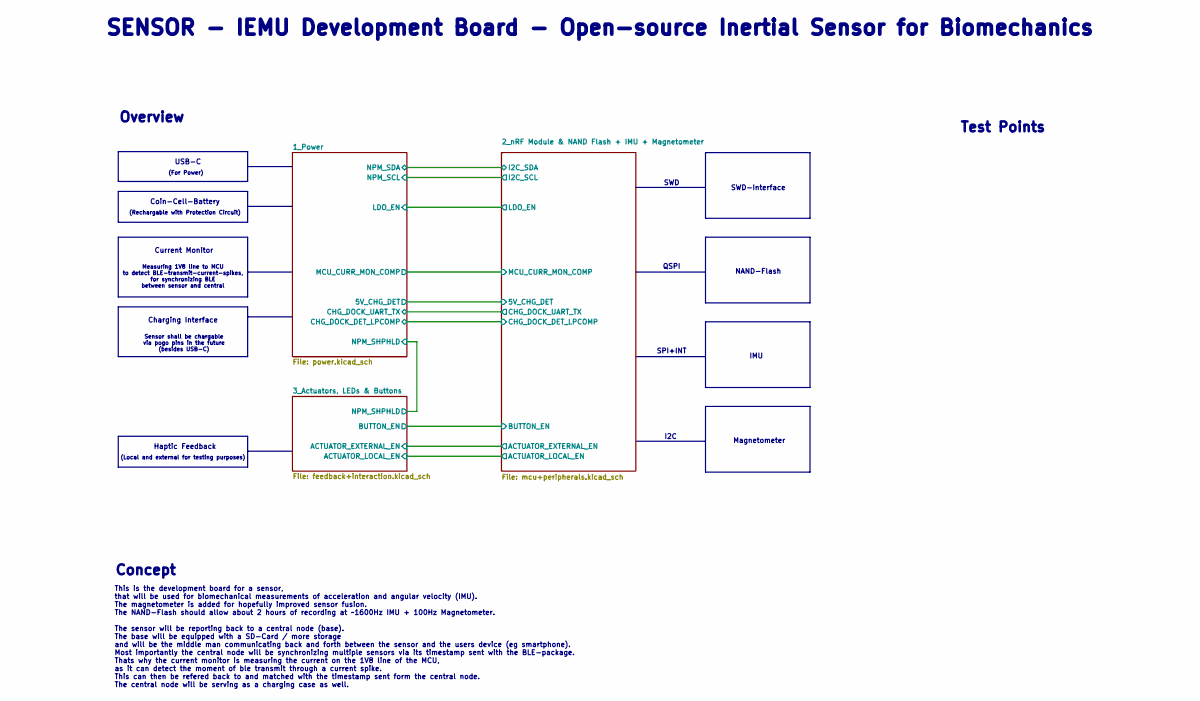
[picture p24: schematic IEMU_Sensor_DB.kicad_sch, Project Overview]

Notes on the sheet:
(Rechargable with Protection Circuit)
SWD
Current Monitor
(Local and external for testing purposes)
Concept
USB-C
This is the development board for a sensor, that will be used for biomechanical measurements of acceleration and angular velocity (IMU). The magnetometer is added for hopefully improved sensor fusion. The NAND-Flash should allow about 2 hours of recording at ~1600Hz IMU + 100Hz Magnetometer. The se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
Magnetometer
NAND-Flash
IMU
(For Power)
I2C
Coin-Cell-Battery
Charging Interface
SWD-Interface
Measuring 1V8 line to MCU to detect BLE-transmit-current-spikes, for synchronizing BLE between sensor and central
Test Points
Sensor shall be chargable via pogo pins in the future (besides USB-C)
QSPI
Overview
Haptic Feedback
SPI+INT
SENSOR - IEMU Development Board - Open-source Inertial Sensor for Biomechanics

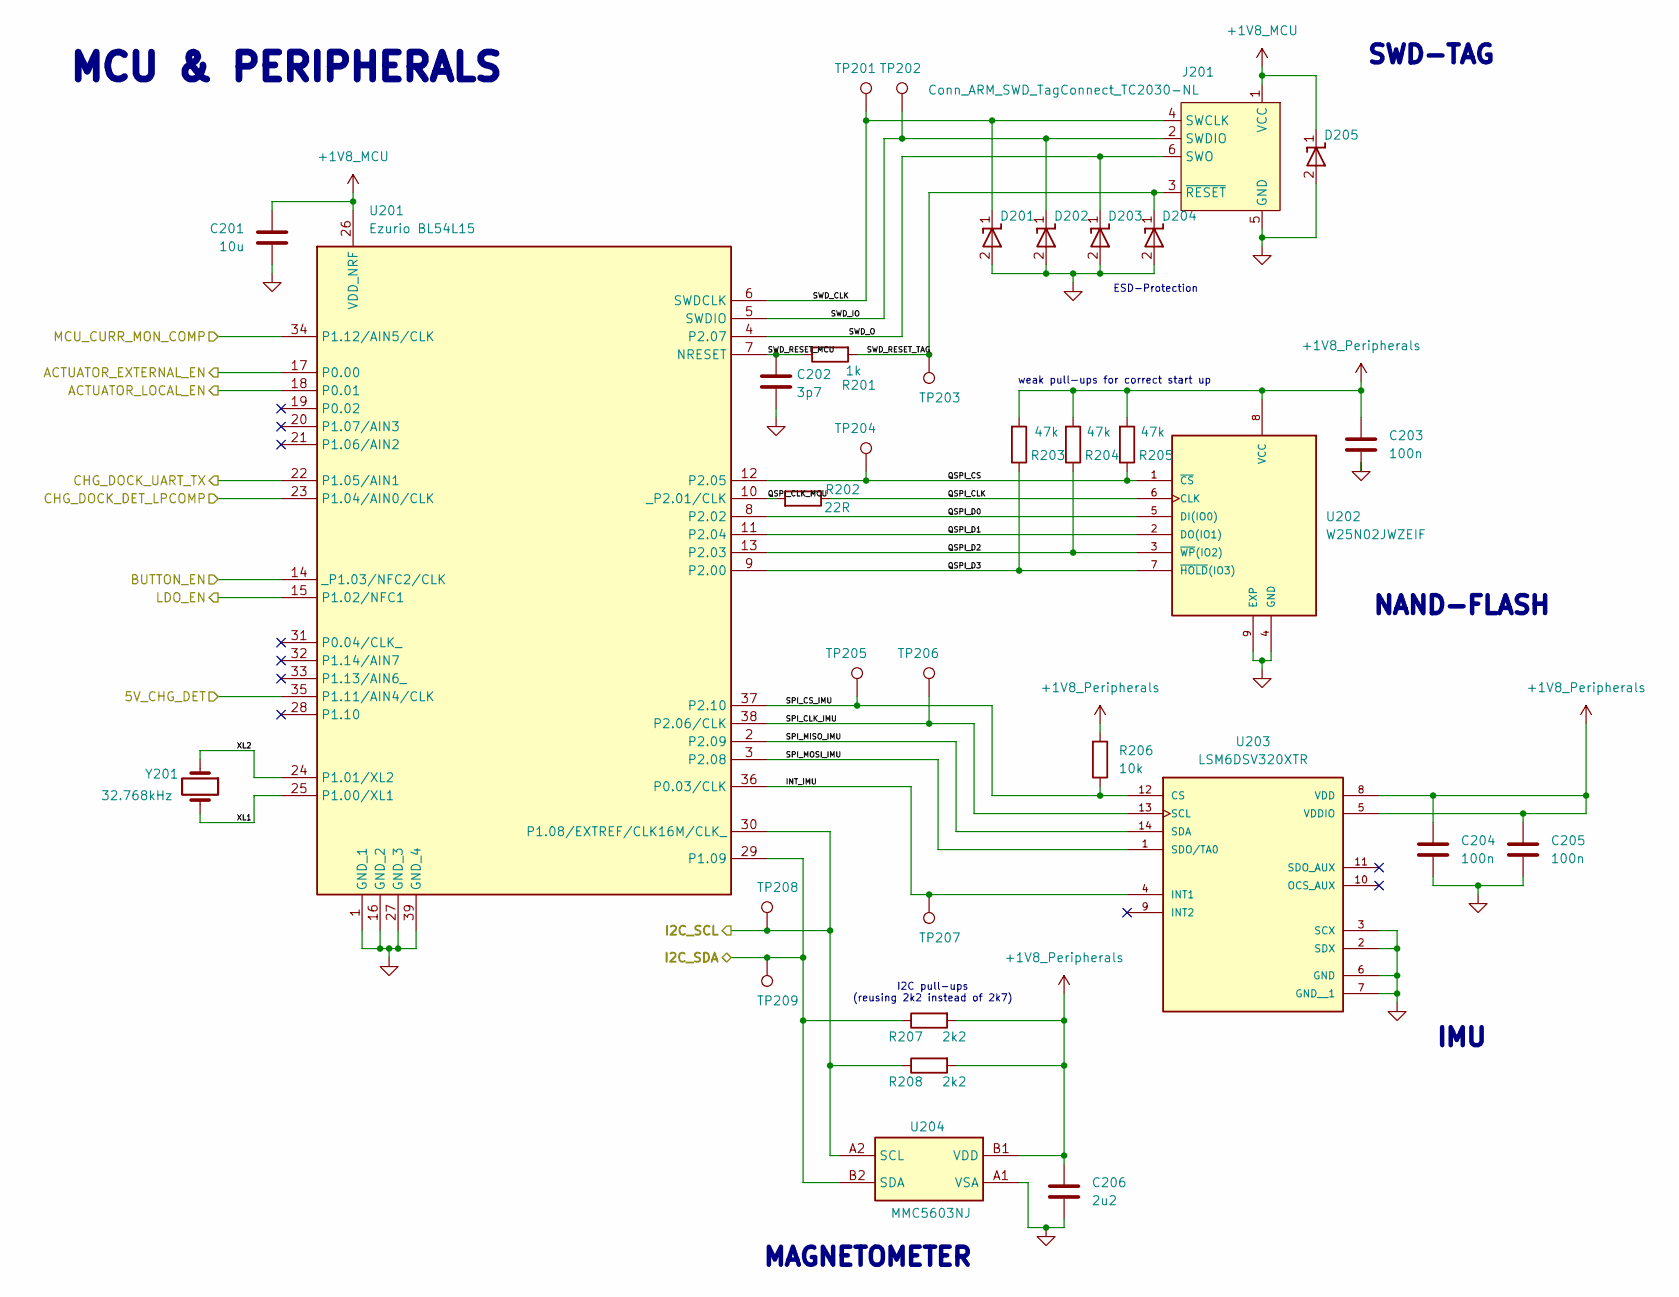
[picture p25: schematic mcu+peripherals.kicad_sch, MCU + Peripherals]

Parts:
C201: 10u; C_0603_1608Metric; Manufacturer_Part_Number CL10A106MA8NRNC; LCSC C96446
C202: 3p7; C_0402_1005Metric; Manufacturer_Part_Number GCM1555C1H3R7CA16D; LCSC C2189484
C203, C204, C205: 100n; C_0402_1005Metric; Manufacturer_Part_Number CL05B104KO5NNNC; LCSC C1525
C206: 2u2; C_0402_1005Metric; Manufacturer_Part_Number CL05A225MQ5NSNC; LCSC C12530
D201, D202, D203, D204, D205: RCLAMP01811PW.C; DIODFN100X60X55-2N; Manufacturer_Part_Number RCLAMP01811PW.C
J201: Conn_ARM_SWD_TagConnect_TC2030-NL; Tag-Connect_TC2030-IDC-NL_2x03_P1.27mm_Vertical
R201: 1k; R_0402_1005Metric; Manufacturer_Part_Number 0402WGF1001TCE; LCSC C11702
R202: 22R; R_0603_1608Metric; Manufacturer_Part_Number 0603WAF220JT5E; LCSC C23345
R203, R204, R205: 47k; R_0402_1005Metric; Manufacturer_Part_Number 0402WGF4702TCE; LCSC C25792
R206: 10k; R_0402_1005Metric; Manufacturer_Part_Number 0402WGF1002TCE; LCSC C25744
R207, R208: 2k2; R_0402_1005Metric; Manufacturer_Part_Number 0402WGF2201TCE; LCSC C25879
TP201, TP202, TP203, TP204, TP205, TP206, TP207, TP208, TP209: TestPoint_Pad_D1.0mm
U201: Ezurio BL54L15; BL54L15; Manufacturer_Part_Number 453-00001C
U202: W25N02JWZEIF; IC_W25N04KVZEIR; Manufacturer_Part_Number W25N02JWZEIF; LCSC C2962014
U203: LSM6DSV320XTR; LGA-14_3x2.5mm_P0.5mm_LayoutBorder3x4y; Manufacturer_Part_Number LSM6DSV320XTR; LCSC C26633007
U204: MMC5603NJ; Manufacturer_Part_Number MMC5603NJ; LCSC C404328
Y201: 32.768kHz; Crystal_SMD_3215-2Pin_3.2x1.5mm; Manufacturer_Part_Number SC-32S32.768kHz20PPM9pF; LCSC C97605

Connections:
+1V8_MCU: C201.1, D205.1 (I/O), J201.1 (VCC), U201.26 (VDD_NRF); also elsewhere on the board
+1V8_Peripherals: C203.1, C204.1, C205.1, C206.1, R203.1, R204.1, R205.1, R206.1, R207.1, R208.1, U202.8 (VCC), U203.5 (VDDIO), U203.8 (VDD), U204.B1 (VDD); also elsewhere on the board
/1_Power/5V_CHG_DET: U201.35 (P1.11/AIN4/CLK); also elsewhere on the board
/1_Power/CHG_DOCK_DET_LPCOMP: U201.23 (P1.04/AIN0/CLK); also elsewhere on the board
/1_Power/CHG_DOCK_UART_TX: U201.22 (P1.05/AIN1); also elsewhere on the board
/1_Power/LDO_EN: U201.15 (P1.02/NFC1); also elsewhere on the board
/1_Power/MCU_CURR_MON_COMP: U201.34 (P1.12/AIN5/CLK); also elsewhere on the board
/1_Power/NPM_SCL: R208.2, TP208.1, U201.30 (P1.08/EXTREF/CLK16M/CLK_), U204.A2 (SCL); also elsewhere on the board
/1_Power/NPM_SDA: R207.2, TP209.1, U201.29 (P1.09), U204.B2 (SDA); also elsewhere on the board
/2_nRF Module & NAND Flash + IMU + Magnetometer/ACTUATOR_EXTERNAL_EN: U201.17 (P0.00); also elsewhere on the board
/2_nRF Module & NAND Flash + IMU + Magnetometer/ACTUATOR_LOCAL_EN: U201.18 (P0.01); also elsewhere on the board
/2_nRF Module & NAND Flash + IMU + Magnetometer/BUTTON_EN: U201.14 (_P1.03/NFC2/CLK); also elsewhere on the board
/2_nRF Module & NAND Flash + IMU + Magnetometer/INT_IMU: TP207.1, U201.36 (P0.03/CLK), U203.4 (INT1)
/2_nRF Module & NAND Flash + IMU + Magnetometer/QSPI_CLK: R202.2, U202.6 (CLK)
/2_nRF Module & NAND Flash + IMU + Magnetometer/QSPI_CLK_MCU: R202.1, U201.10 (_P2.01/CLK)
/2_nRF Module & NAND Flash + IMU + Magnetometer/QSPI_CS: R205.2, TP204.1, U201.12 (P2.05), U202.1 (~CS)
/2_nRF Module & NAND Flash + IMU + Magnetometer/QSPI_D0: U201.8 (P2.02), U202.5 (DI(IO0))
/2_nRF Module & NAND Flash + IMU + Magnetometer/QSPI_D1: U201.11 (P2.04), U202.2 (DO(IO1))
/2_nRF Module & NAND Flash + IMU + Magnetometer/QSPI_D2: R204.2, U201.13 (P2.03), U202.3 (~WP(IO2))
/2_nRF Module & NAND Flash + IMU + Magnetometer/QSPI_D3: R203.2, U201.9 (P2.00), U202.7 (~HOLD(IO3))
/2_nRF Module & NAND Flash + IMU + Magnetometer/SPI_CLK_IMU: TP206.1, U201.38 (P2.06/CLK), U203.13 (SCL)
/2_nRF Module & NAND Flash + IMU + Magnetometer/SPI_CS_IMU: R206.2, TP205.1, U201.37 (P2.10), U203.12 (CS)
/2_nRF Module & NAND Flash + IMU + Magnetometer/SPI_MISO_IMU: U201.2 (P2.09), U203.14 (SDA)
/2_nRF Module & NAND Flash + IMU + Magnetometer/SPI_MOSI_IMU: U201.3 (P2.08), U203.1 (SDO/TA0)
/2_nRF Module & NAND Flash + IMU + Magnetometer/SWD_CLK: D201.1 (I/O), J201.4 (SWCLK), TP201.1, U201.6 (SWDCLK)
/2_nRF Module & NAND Flash + IMU + Magnetometer/SWD_IO: D202.1 (I/O), J201.2 (SWDIO), TP202.1, U201.5 (SWDIO)
/2_nRF Module & NAND Flash + IMU + Magnetometer/SWD_O: D203.1 (I/O), J201.6 (SWO), U201.4 (P2.07)
/2_nRF Module & NAND Flash + IMU + Magnetometer/SWD_RESET_MCU: C202.1, R201.2, U201.7 (NRESET)
/2_nRF Module & NAND Flash + IMU + Magnetometer/SWD_RESET_TAG: D204.1 (I/O), J201.3 (~RESET), R201.1, TP203.1
/2_nRF Module & NAND Flash + IMU + Magnetometer/XL1: U201.25 (P1.00/XL1), Y201.2
/2_nRF Module & NAND Flash + IMU + Magnetometer/XL2: U201.24 (P1.01/XL2), Y201.1
GND: C201.2, C202.2, C203.2, C204.2, C205.2, C206.2, D201.2 (GND), D202.2 (GND), D203.2 (GND), D204.2 (GND), D205.2 (GND), J201.5 (GND), U201.1 (GND_1), U201.16 (GND_2), U201.27 (GND_3), U201.39 (GND_4), U202.4 (GND), U202.9 (EXP), U203.2 (SDX), U203.3 (SCX), U203.6 (GND), U203.7 (GND__1), U204.A1 (VSA); also elsewhere on the board

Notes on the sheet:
I2C pull-ups (reusing 2k2 instead of 2k7)
MAGNETOMETER
IMU
SWD-TAG
MCU & PERIPHERALS
NAND-FLASH
weak pull-ups for correct start up
ESD-Protection

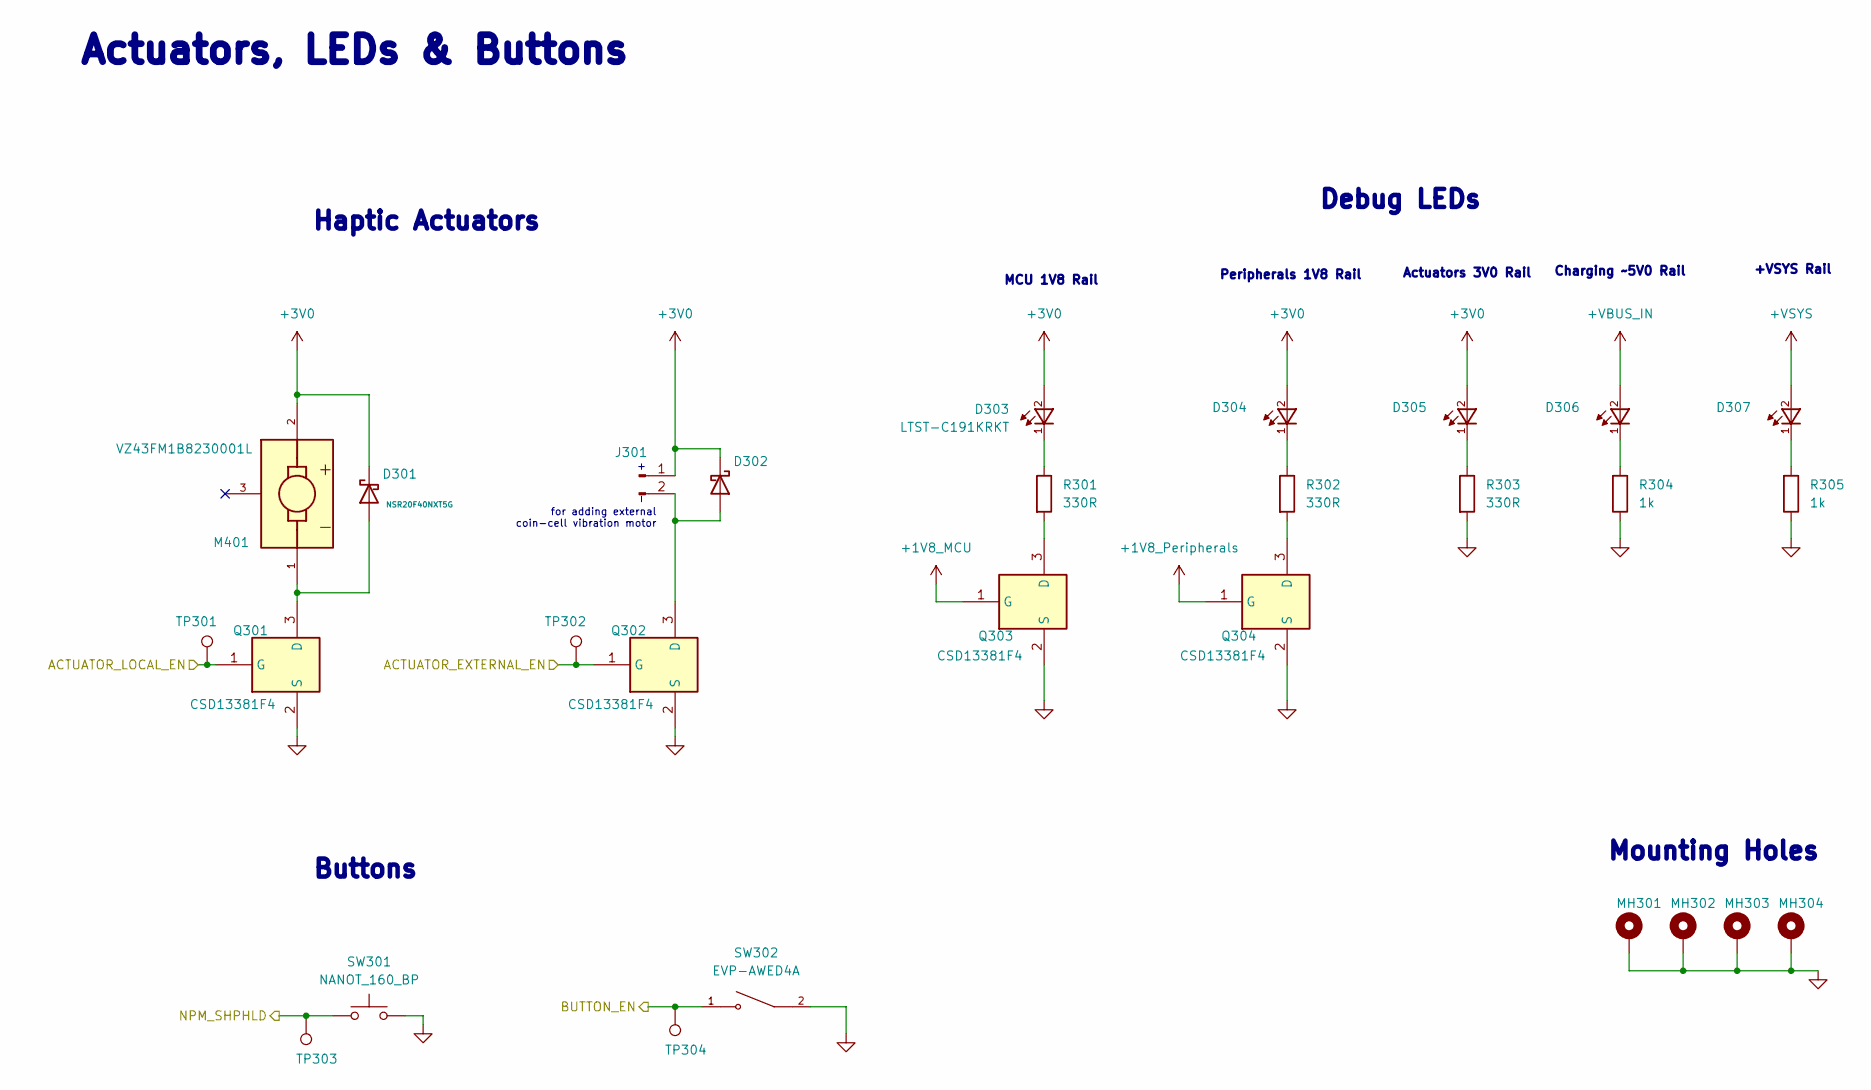
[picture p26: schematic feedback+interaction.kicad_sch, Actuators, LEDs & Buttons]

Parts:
D301, D302: D_Schottky_2A_40V_0603; 0603_DSN; Manufacturer_Part_Number NSR20F40NXT5G; LCSC C153761
D303, D304, D305, D306, D307: LTST-C191KRKT; Manufacturer_Part_Number LTST-C191KRKT; LCSC C125099
J301: Conn_01x02_Pin; SolderWire-0.5sqmm_1x02_P4.6mm_D0.9mm_OD2.1mm
M401: VZ43FM1B8230001L; XDCR_VZ43FM1B8230001L; Manufacturer_Part_Number VZ43FM1B8230001L; LCSC C7467059
MH301, MH302, MH303, MH304: MountingHole_Pad; MountingHole_2.2mm_M2_Pad_Via
Q301, Q302, Q303, Q304: CSD13381F4; DFN100X60X35-3N; Manufacturer_Part_Number CSD13381F4; LCSC C179868
R301, R302, R303: 330R; R_0402_1005Metric; Manufacturer_Part_Number 0402WGF3300TCE; LCSC C25104
R304, R305: 1k; R_0402_1005Metric; Manufacturer_Part_Number 0402WGF1001TCE; LCSC C11702
SW301: NANOT_160_BP; NANOT160BP; Manufacturer_Part_Number NANOT160BP; LCSC C2760983
SW302: EVP-AWED4A; SW_EVP-AWED4A; Manufacturer_Part_Number EVP-AWBD2A
TP301, TP302, TP303, TP304: TestPoint_Pad_D1.0mm

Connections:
+1V8_MCU: Q303.1 (G); also elsewhere on the board
+1V8_Peripherals: Q304.1 (G); also elsewhere on the board
+3V0: D301.1 (K), D302.1 (K), D303.2, D304.2, D305.2, J301.1, M401.2; also elsewhere on the board
+VBUS_IN: D306.2; also elsewhere on the board
+VSYS: D307.2; also elsewhere on the board
/1_Power/NPM_SHPHLD: SW301.1, TP303.1; also elsewhere on the board
/2_nRF Module & NAND Flash + IMU + Magnetometer/ACTUATOR_EXTERNAL_EN: Q302.1 (G), TP302.1; also elsewhere on the board
/2_nRF Module & NAND Flash + IMU + Magnetometer/ACTUATOR_LOCAL_EN: Q301.1 (G), TP301.1; also elsewhere on the board
/2_nRF Module & NAND Flash + IMU + Magnetometer/BUTTON_EN: SW302.1, TP304.1; also elsewhere on the board
GND: MH301.1, MH302.1, MH303.1, MH304.1, Q301.2 (S), Q302.2 (S), Q303.2 (S), Q304.2 (S), R303.2, R304.2, R305.2, SW301.2, SW302.2; also elsewhere on the board
unnamed: D301.2 (A), M401.1, Q301.3 (D)
unnamed: D302.2 (A), J301.2, Q302.3 (D)
unnamed: D303.1, R301.1
unnamed: D304.1, R302.1
unnamed: D305.1, R303.1
unnamed: D306.1, R304.1
unnamed: D307.1, R305.1
unnamed: Q303.3 (D), R301.2
unnamed: Q304.3 (D), R302.2

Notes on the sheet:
Actuators 3V0 Rail
Mounting Holes
Buttons
Actuators, LEDs & Buttons
Peripherals 1V8 Rail
for adding external coin-cell vibration motor
+VSYS Rail
MCU 1V8 Rail
Haptic Actuators
Charging ~5V0 Rail
Debug LEDs

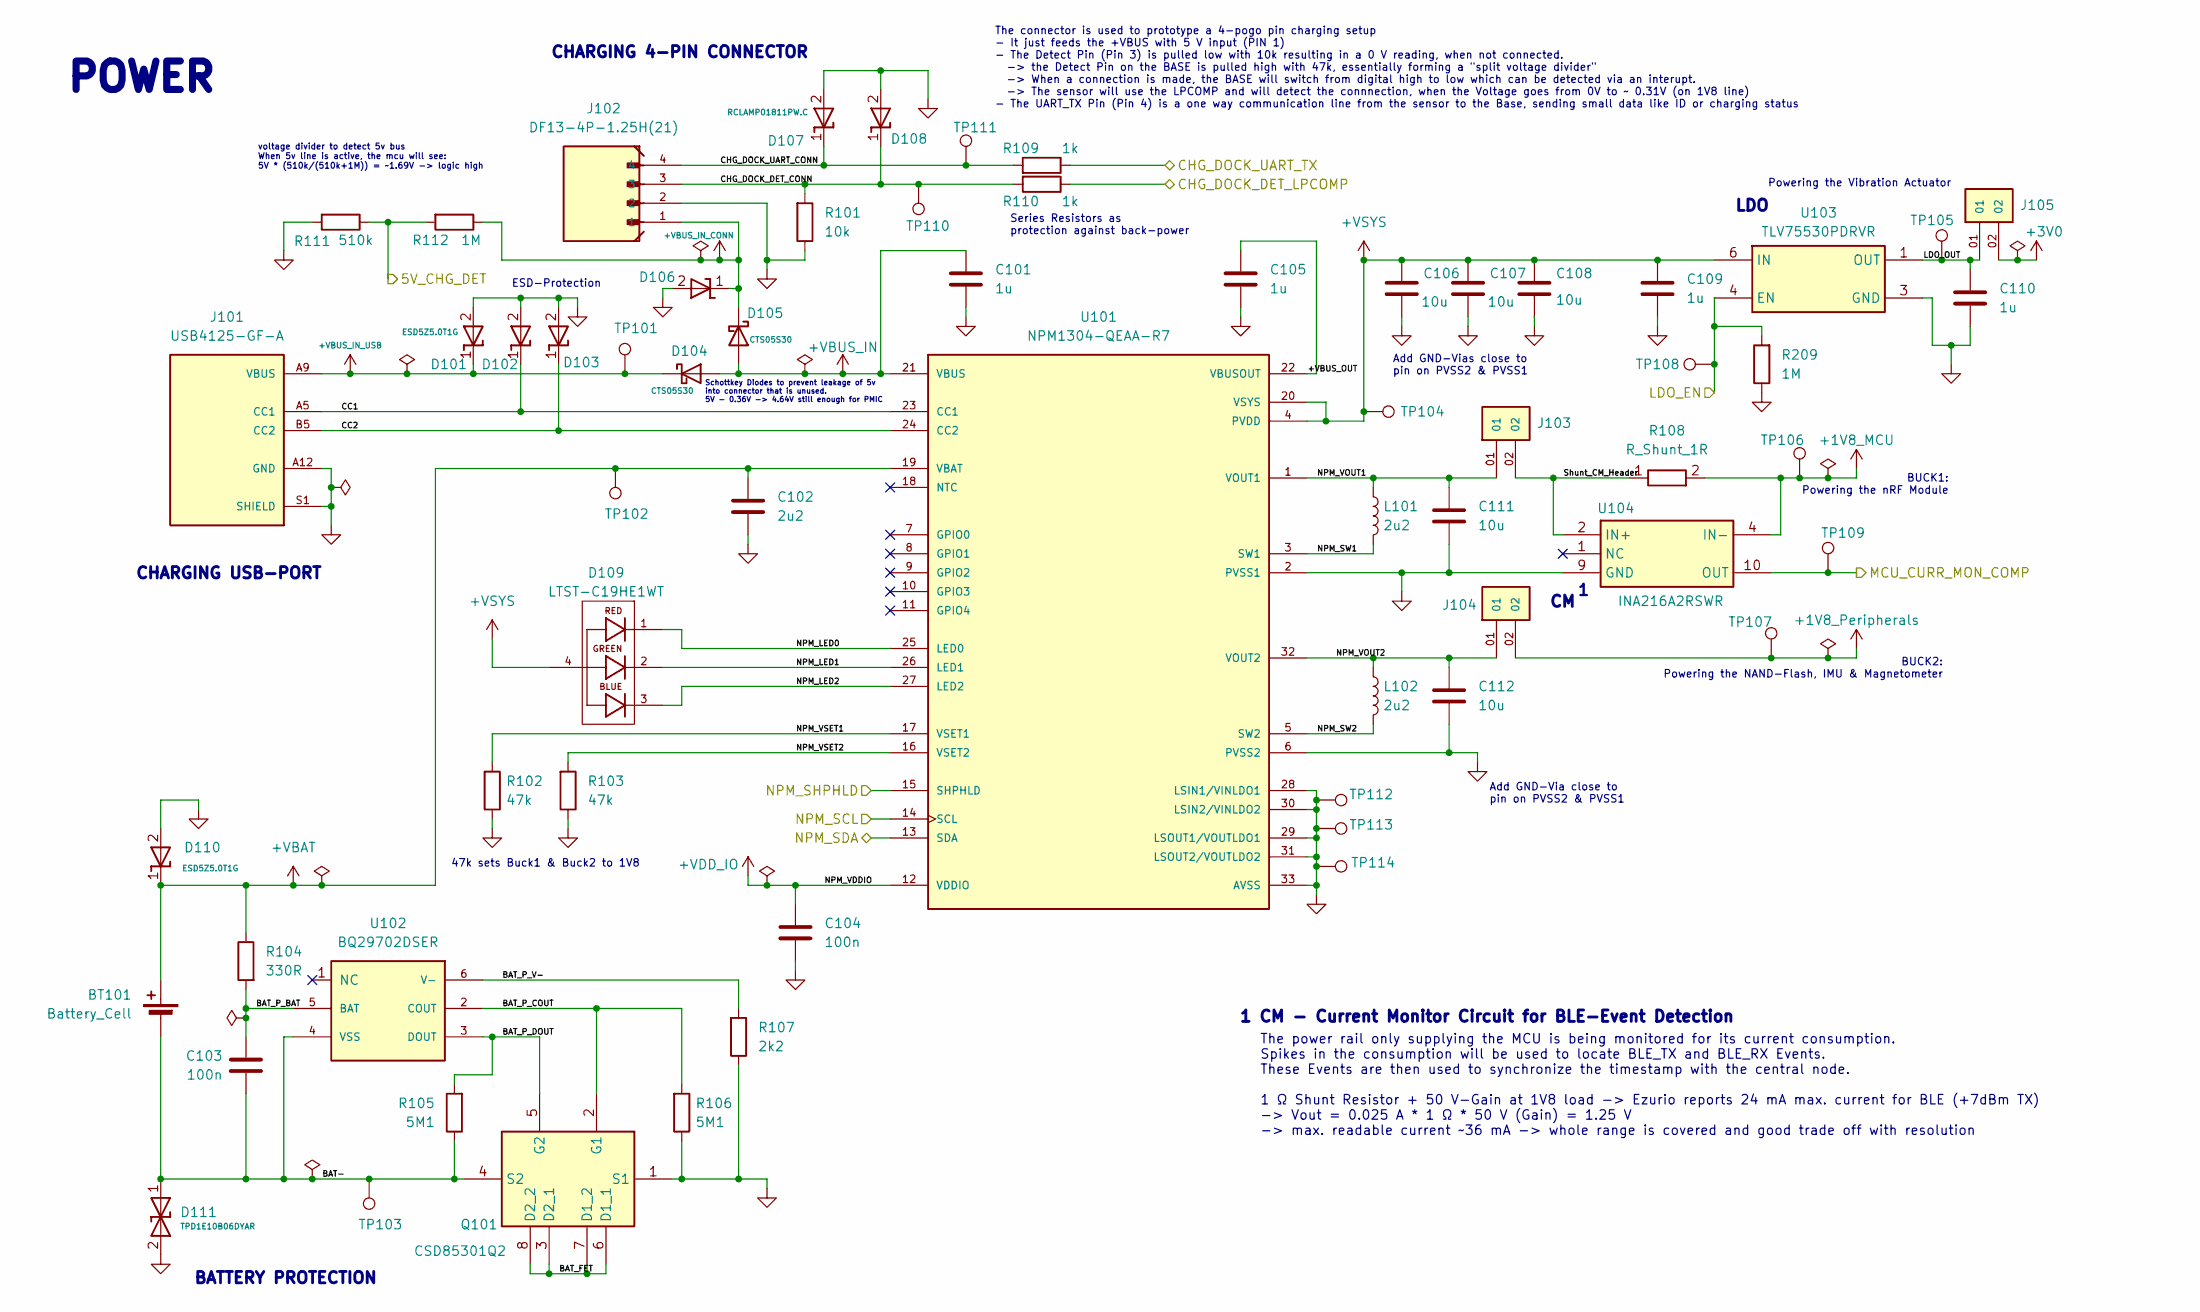
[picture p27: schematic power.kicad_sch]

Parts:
BT101: Battery_Cell; CoinCell_LIR1455_LBY2
C101, C105, C109, C110: 1u; C_0402_1005Metric; Manufacturer_Part_Number CL05A105KA5NQNC; LCSC C52923
C102: 2u2; C_0402_1005Metric; Manufacturer_Part_Number CL05A225MQ5NSNC; LCSC C12530
C103, C104: 100n; C_0402_1005Metric; Manufacturer_Part_Number CL05B104KO5NNNC; LCSC C1525
C106, C107, C108, C111, C112: 10u; C_0603_1608Metric; Manufacturer_Part_Number CL10A106MA8NRNC; LCSC C96446
D101, D102, D103, D106, D110: ESD5Z5.0T1G; D_SOD-523_1; Manufacturer_Part_Number ESD5Z5.0T1G; LCSC C82044
D104, D105: CTS05S30; D_SOD-882; Manufacturer_Part_Number CTS05S30
D107, D108: RCLAMP01811PW.C; DIODFN100X60X55-2N; Manufacturer_Part_Number RCLAMP01811PW.C
D109: LTST-C19HE1WT; LED_LTST-C19HE1WT; Manufacturer_Part_Number LTST-C19HE1WT; LCSC C458749
D111: TPD1E10B06DYAR; D_SOD-523; Manufacturer_Part_Number TPD1E10B06DYAR; LCSC C3712135
J101: USB4125-GF-A; GCT_USB4125-GF-A_REVA2; Manufacturer_Part_Number USB4125-GF-A; LCSC C3151650
J102: DF13-4P-1.25H(21); Manufacturer_Part_Number DF13-4P-1.25H(21); LCSC C597872
J103, J104, J105: SAMTEC_MTSW-101-X-X-D-X; Manufacturer_Part_Number MTSW-101-07-T-D-240
L101, L102: 2u2; L_0603_1608Metric; Manufacturer_Part_Number LSCNB1608HKT2R2MD; LCSC C6079477
Q101: CSD85301Q2; Manufacturer_Part_Number CSD85301Q2; LCSC C544396
R101: 10k; R_0402_1005Metric; Manufacturer_Part_Number 0402WGF1002TCE; LCSC C25744
R102, R103: 47k; R_0402_1005Metric; Manufacturer_Part_Number 0402WGF4702TCE; LCSC C25792
R104: 330R; R_0402_1005Metric; Manufacturer_Part_Number 0402WGF3300TCE; LCSC C25104
R105, R106: 5M1; R_0402_1005Metric; Manufacturer_Part_Number RC0402JR-075M1L; LCSC C137855
R107: 2k2; R_0402_1005Metric; Manufacturer_Part_Number 0402WGF2201TCE; LCSC C25879
R108: R_Shunt_1R; R_0402_1005Metric; Manufacturer_Part_Number RLP73K1E1R0FTDF; LCSC C2074826
R109, R110: 1k; R_0402_1005Metric; Manufacturer_Part_Number 0402WGF1001TCE; LCSC C11702
R111: 510k; R_0603_1608Metric; Manufacturer_Part_Number 0603WAF5103T5E; LCSC C23192
R112, R209: 1M; R_0402_1005Metric; Manufacturer_Part_Number 0402WGF1004TCE; LCSC C26083
TP101, TP102, TP103, TP104, TP105, TP106, TP107, TP108, TP109, TP110, TP111, TP112, TP113, TP114: TestPoint_Pad_D1.0mm
U101: NPM1304-QEAA-R7; QFN50P500X500X90-33N; Manufacturer_Part_Number NPM1304-QEAA-R7; LCSC C49448846
U102: BQ29702DSER; WSON-6_1.5x1.5mm_P0.5mm; Manufacturer_Part_Number BQ29702DSER; LCSC C2872632
U103: TLV75530PDRVR; WSON-6-1EP_2x2mm_P0.65mm_EP1x1.6mm_ThermalVias; Manufacturer_Part_Number TLV75530PDRVR; LCSC C2859948
U104: INA216A2RSWR; Texas_RSW0010A_UQFN-10_1.4x1.8mm_P0.4mm; Manufacturer_Part_Number INA216A2RSWR; LCSC C2653823

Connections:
+1V8_MCU: R108.2, TP106.1, U104.4 (IN-), U104.5 (IN-); also elsewhere on the board
+1V8_Peripherals: J104.02, TP107.1; also elsewhere on the board
+3V0: J105.02; also elsewhere on the board
+VBAT: BT101.1 (+), C102.1, D110.1 (I/O), R104.1, TP102.1, U101.19 (VBAT)
+VBUS_IN: C101.1, D104.2 (A), D105.2 (A), U101.21 (VBUS); also elsewhere on the board
+VBUS_IN_CONN: D105.1 (K), D106.1 (I/O), J102.1, R112.2
+VBUS_IN_USB: D101.1 (I/O), D104.1 (K), J101.A9 (VBUS), J101.B9 (VBUS), TP101.1
+VDD_IO: C104.1, U101.12 (VDDIO)
+VSYS: C106.1, C107.1, C108.1, C109.1, D109.4, TP104.1, U101.4 (PVDD), U101.20 (VSYS), U103.6 (IN); also elsewhere on the board
/1_Power/5V_CHG_DET: R111.2, R112.1; also elsewhere on the board
/1_Power/+VBUS_OUT: C105.1, U101.22 (VBUSOUT)
/1_Power/BAT-: BT101.2 (-), C103.2, D111.1 (I/O), Q101.4 (S2), R105.2, TP103.1, U102.4 (VSS)
/1_Power/BAT_FET: Q101.3 (D2_1), Q101.6 (D1_1), Q101.7 (D1_2), Q101.8 (D2_2)
/1_Power/BAT_P_BAT: C103.1, R104.2, U102.5 (BAT)
/1_Power/BAT_P_COUT: Q101.2 (G1), R106.1, U102.2 (COUT)
/1_Power/BAT_P_DOUT: Q101.5 (G2), R105.1, U102.3 (DOUT)
/1_Power/BAT_P_V-: R107.1, U102.6 (V-)
/1_Power/CC1: D102.1 (I/O), J101.A5 (CC1), U101.23 (CC1)
/1_Power/CC2: D103.1 (I/O), J101.B5 (CC2), U101.24 (CC2)
/1_Power/CHG_DOCK_DET_CONN: D108.1 (I/O), J102.3, R101.1, R110.1, TP110.1
/1_Power/CHG_DOCK_DET_LPCOMP: R110.2; also elsewhere on the board
/1_Power/CHG_DOCK_UART_CONN: D107.1 (I/O), J102.4, R109.1, TP111.1
/1_Power/CHG_DOCK_UART_TX: R109.2; also elsewhere on the board
/1_Power/LDO_EN: R209.1, TP108.1, U103.4 (EN); also elsewhere on the board
/1_Power/LDO_OUT: C110.1, J105.01, TP105.1, U103.1 (OUT)
/1_Power/MCU_CURR_MON_COMP: TP109.1, U104.10 (OUT); also elsewhere on the board
/1_Power/NPM_LED0: D109.1, U101.25 (LED0)
/1_Power/NPM_LED1: D109.2, U101.26 (LED1)
/1_Power/NPM_LED2: D109.3, U101.27 (LED2)
/1_Power/NPM_SCL: U101.14 (SCL); also elsewhere on the board
/1_Power/NPM_SDA: U101.13 (SDA); also elsewhere on the board
/1_Power/NPM_SHPHLD: U101.15 (SHPHLD); also elsewhere on the board
/1_Power/NPM_SW1: L101.2, U101.3 (SW1)
/1_Power/NPM_SW2: L102.2, U101.5 (SW2)
/1_Power/NPM_VOUT1: C111.1, J103.01, L101.1, U101.1 (VOUT1)
/1_Power/NPM_VOUT2: C112.1, J104.01, L102.1, U101.32 (VOUT2)
/1_Power/NPM_VSET1: R102.1, U101.17 (VSET1)
/1_Power/NPM_VSET2: R103.1, U101.16 (VSET2)
/1_Power/Shunt_CM_Header: J103.02, R108.1, U104.2 (IN+), U104.3 (IN+)
GND: C101.2, C102.2, C104.2, C105.2, C106.2, C107.2, C108.2, C109.2, C110.2, C111.2, C112.2, D101.2 (GND), D102.2 (GND), D103.2 (GND), D106.2 (GND), D107.2 (GND), D108.2 (GND), D110.2 (GND), D111.2 (GND), J101.A12 (GND), J101.B12 (GND), J101.S1 (SHIELD), J101.S2 (SHIELD), J101.S3 (SHIELD), J101.S4 (SHIELD), J102.2, Q101.1 (S1), R101.2, R102.2, R103.2, R106.2, R107.2, R111.1, R209.2, TP112.1, TP113.1, TP114.1, U101.2 (PVSS1), U101.6 (PVSS2), U101.28 (LSIN1/VINLDO1), U101.29 (LSOUT1/VOUTLDO1), U101.30 (LSIN2/VINLDO2), U101.31 (LSOUT2/VOUTLDO2), U101.33 (AVSS), U103.2 (NC), U103.3 (GND), U103.5 (NC), U103.7 (GND), U104.9 (GND); also elsewhere on the board

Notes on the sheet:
POWER
BUCK2: Powering the NAND-Flash, IMU & Magnetometer
Powering the Vibration Actuator
LDO
Schottkey Diodes to prevent leakage of 5v into connector that is unused. 5V - 0.36V -> 4.64V still enough for PMIC
BUCK1: Powering the nRF Module
47k sets Buck1 & Buck2 to 1V8
CHARGING USB-PORT
ESD-Protection
Add GND-Vias close to pin on PVSS2 & PVSS1
Series Resistors as protection against back-power
Add GND-Via close to pin on PVSS2 & PVSS1
1 CM - Current Monitor Circuit for BLE-Event Detection
voltage divider to detect 5v bus When 5v line is active, the mcu will see: 5V * (510k/(510k+1M)) = ~1.69V -> logic high
The connector is used to prototype a 4-pogo pin charging setup - It just feeds the +VBUS with 5 V input (PIN 1) - The Detect Pin (Pin 3) is pulled low with 10k resulting in a 0 V reading, when not connected. -> the Detect Pin on the BASE is pulled high with 47k, essentially forming a "split voltage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
BATTERY PROTECTION
CHARGING 4-PIN CONNECTOR
The power rail only supplying the MCU is being monitored for its current consumption. Spikes in the consumption will be used to locate BLE_TX and BLE_RX Events. These Events are then used to synchronize the timestamp with the central node. 1 Ω Shunt Resistor + 50 V-Gain at 1V8 load -> Ezurio report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

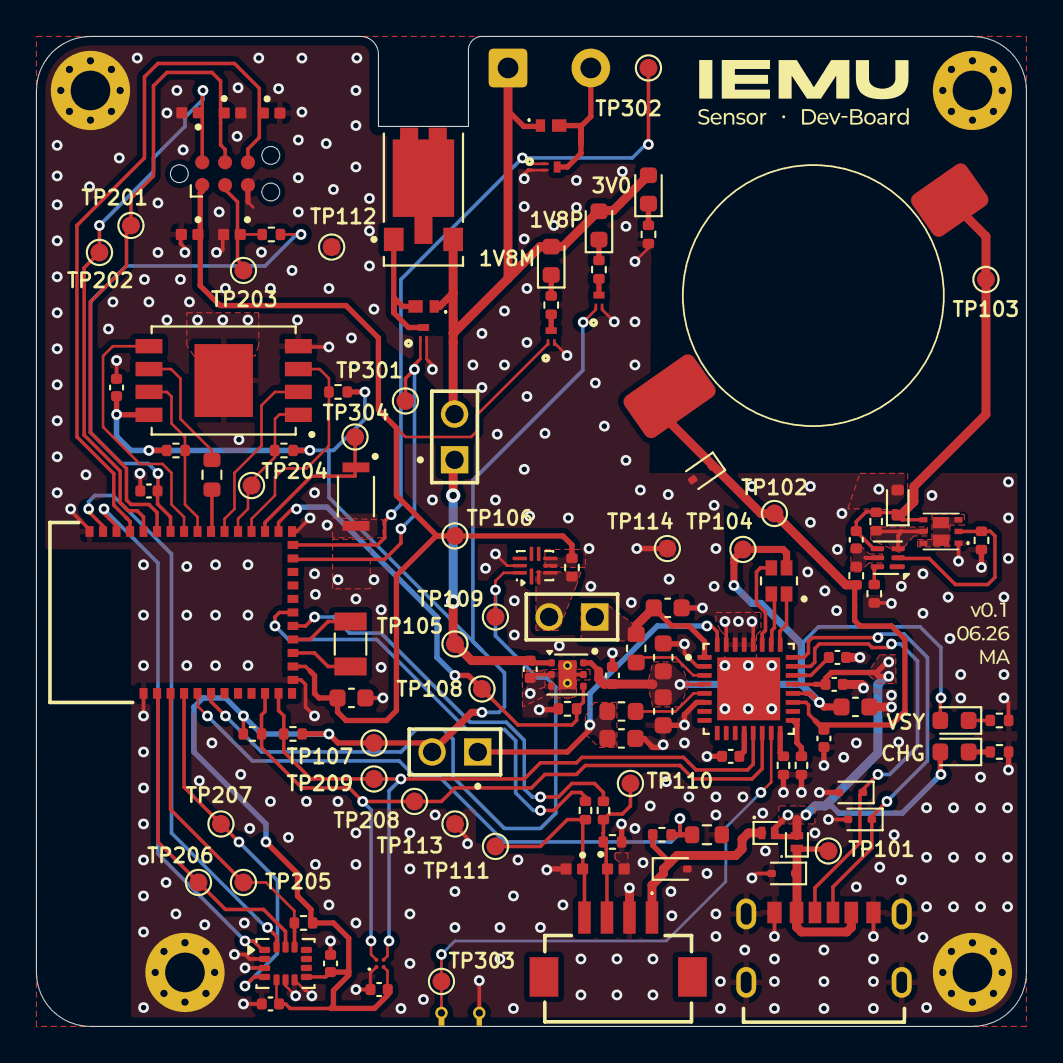
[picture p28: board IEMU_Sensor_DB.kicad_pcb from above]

Board: 4 copper layers, 55.0 x 55.0 mm, 125 parts (0 on the bottom side), 71 nets.

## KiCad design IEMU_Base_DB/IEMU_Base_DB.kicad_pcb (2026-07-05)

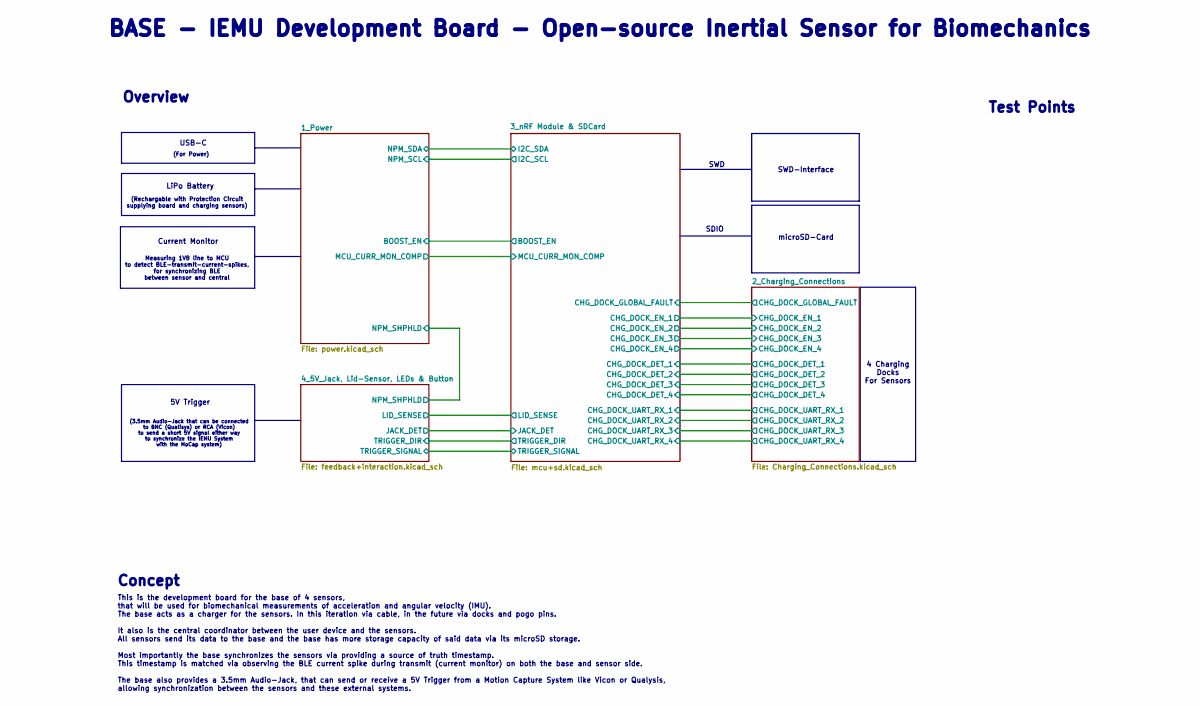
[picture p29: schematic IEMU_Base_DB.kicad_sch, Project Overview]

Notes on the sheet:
(Rechargable with Protection Circuit supplying board and charging sensors)
SWD
Current Monitor
(3.5mm Audio-Jack that can be connected to BNC (Qualisys) or RCA (Vicon) to send a short 5V signal either way to synchronize the IEMU System with the MoCap system)
Concept
USB-C
This is the development board for the base of 4 sensors, that will be used for biomechanical measurements of acceleration and angular velocity (IMU). The base acts as a charger for the sensors. In this iteration via cable, in the future via docks and pogo pins. It also is the central coordinator be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
microSD-Card
(For Power)
LiPo Battery
SWD-Interface
Measuring 1V8 line to MCU to detect BLE-transmit-current-spikes, for synchronizing BLE between sensor and central
Test Points
4 Charging Docks For Sensors
SDIO
Overview
5V Trigger
BASE - IEMU Development Board - Open-source Inertial Sensor for Biomechanics

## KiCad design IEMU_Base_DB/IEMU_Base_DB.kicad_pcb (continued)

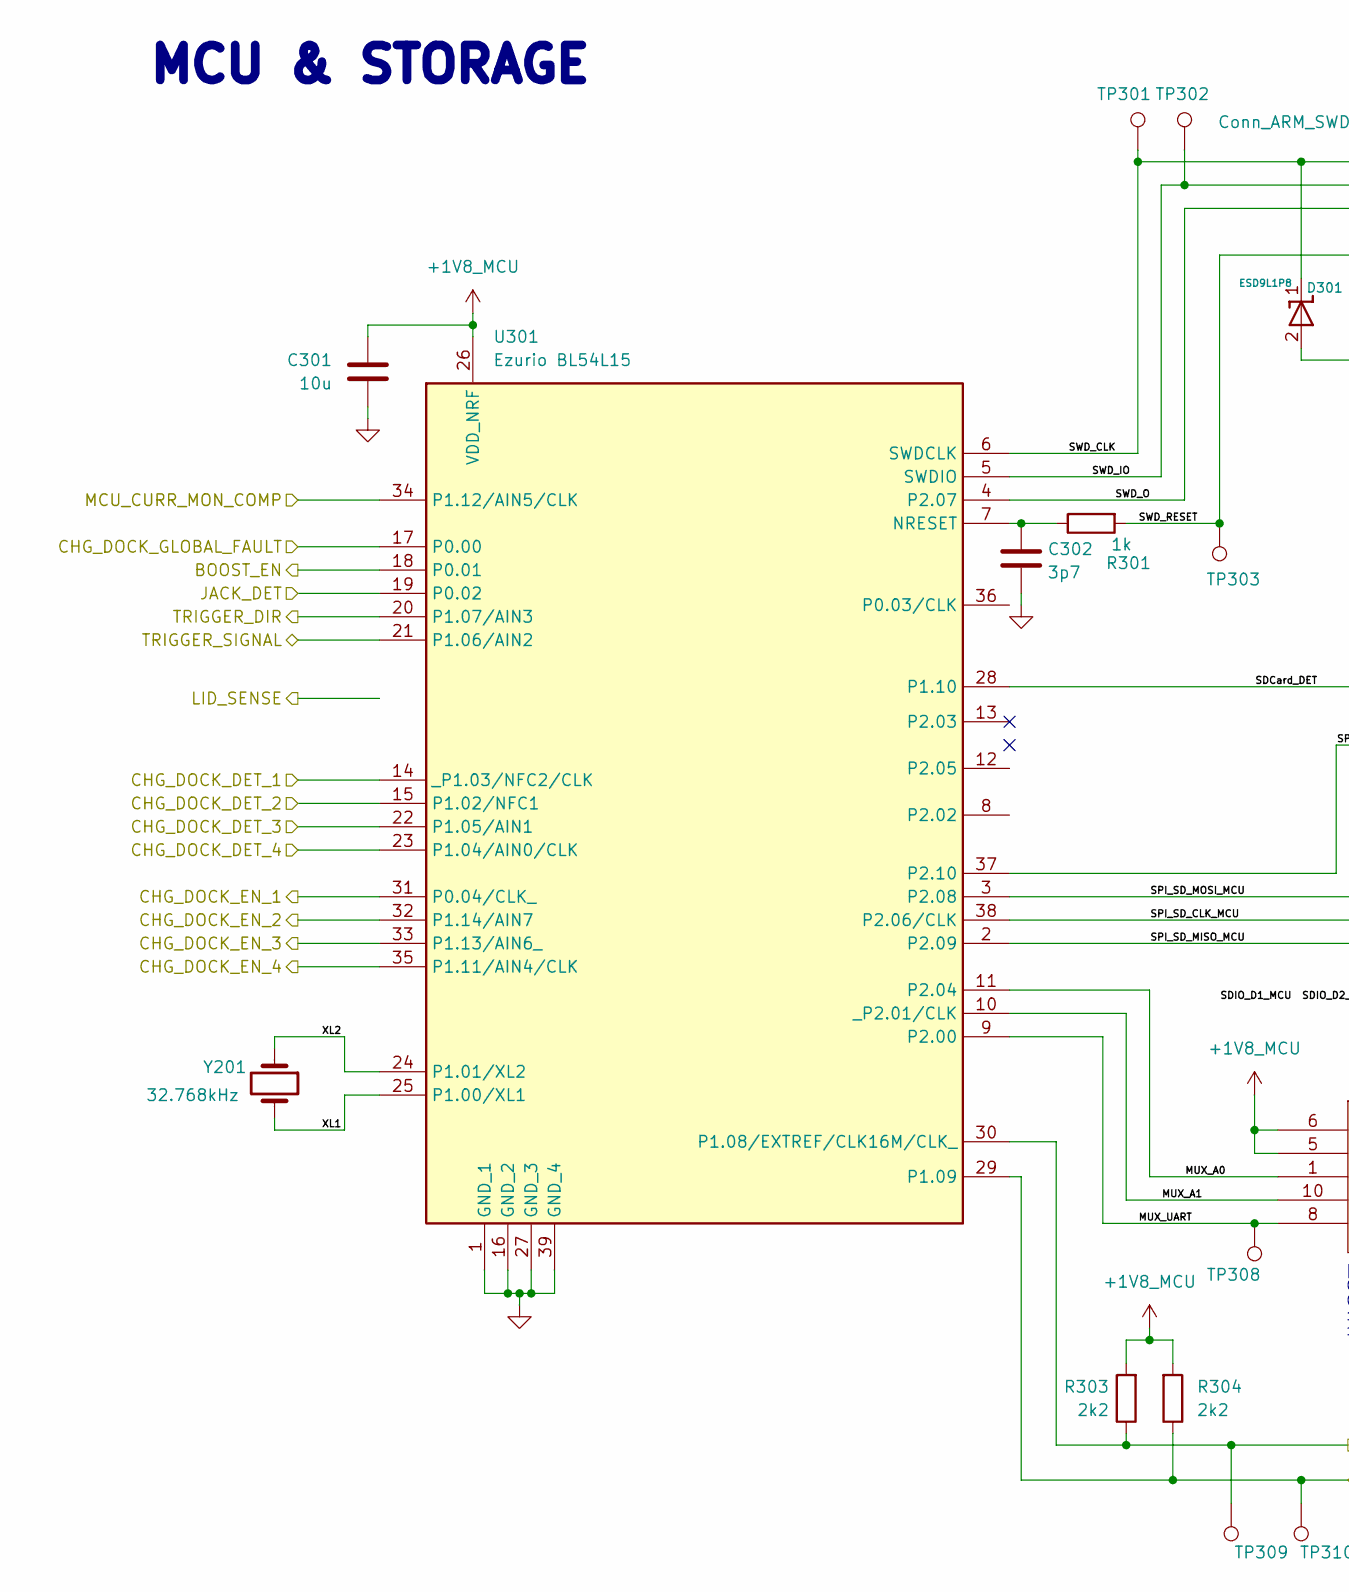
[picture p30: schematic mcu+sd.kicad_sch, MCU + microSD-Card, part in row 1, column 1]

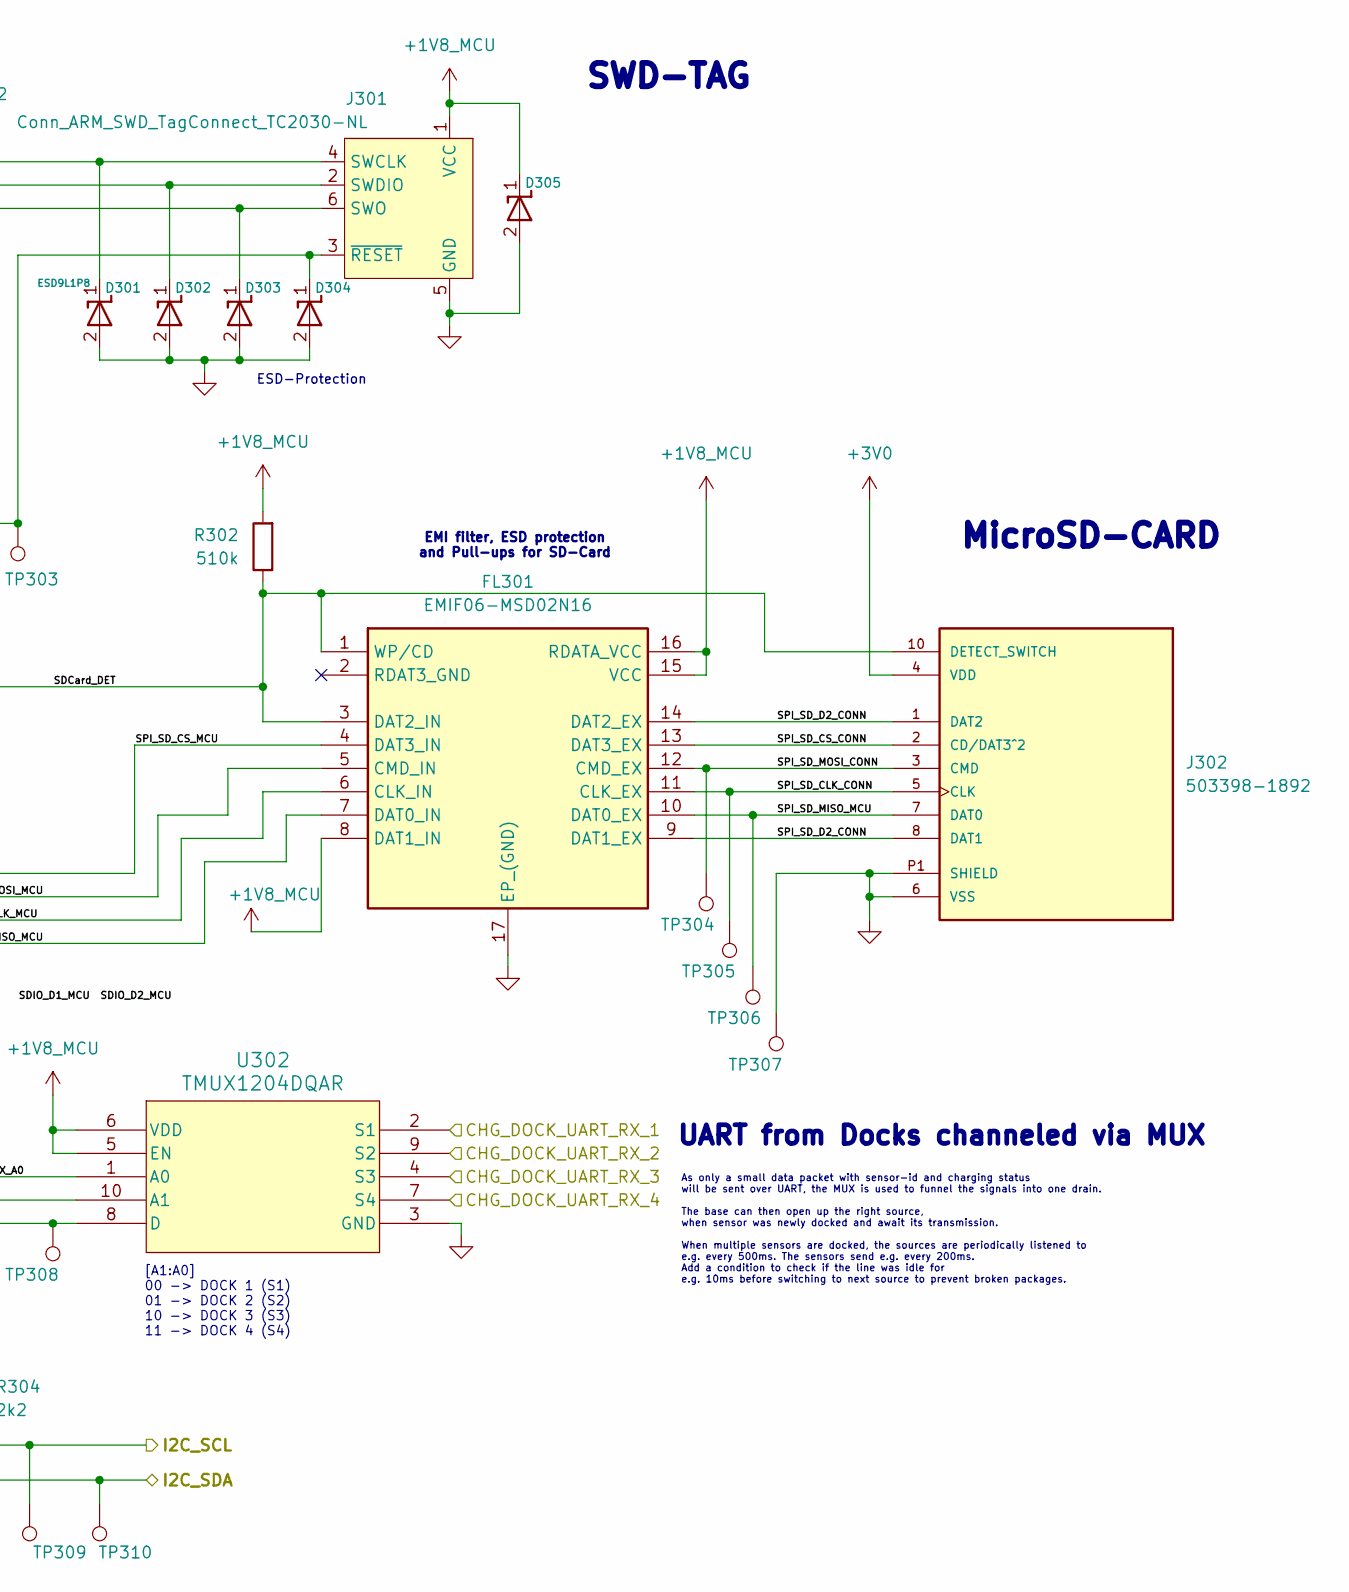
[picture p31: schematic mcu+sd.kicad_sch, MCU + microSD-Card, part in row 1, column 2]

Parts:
C301: 10u; C_0603_1608Metric; Manufacturer_Part_Number CL10A106MA8NRNC; LCSC C96446
C302: 3p7; C_0402_1005Metric; Manufacturer_Part_Number GCM1555C1H3R7CA16D; LCSC C2189484
D301, D302, D303, D304, D305: ESD9L1P8; D_SOD-882; Manufacturer_Part_Number ESD9L1P8; LCSC C6244607
FL301: EMIF06-MSD02N16; EMIF06MSD02N16; Manufacturer_Part_Number EMIF06-MSD02N16; LCSC C5267594
J301: Conn_ARM_SWD_TagConnect_TC2030-NL; Tag-Connect_TC2030-IDC-NL_2x03_P1.27mm_Vertical
J302: 503398-1892; MOLEX_503398-1892; Manufacturer_Part_Number 503398-1892; LCSC C428492
R301: 1k; R_0402_1005Metric; Manufacturer_Part_Number 0402WGF1001TCE; LCSC C11702
R302: 510k; R_0603_1608Metric; Manufacturer_Part_Number 0603WAF5103T5E; LCSC C23192
R303, R304: 2k2; R_0402_1005Metric; Manufacturer_Part_Number 0402WGF2201TCE; LCSC C25879
TP301, TP302, TP303, TP309, TP310: TestPoint_Pad_D1.0mm
TP304, TP305, TP306, TP307, TP308: TestPoint; TestPoint_Pad_D1.0mm
U301: Ezurio BL54L15; BL54L15; Manufacturer_Part_Number 453-00001C
U302: TMUX1204DQAR; IC_TPD4EUSB30DQAR; Manufacturer_Part_Number TMUX1204DQAR; LCSC C1849379
Y201: 32.768kHz; Crystal_SMD_3215-2Pin_3.2x1.5mm; Manufacturer_Part_Number SC-32S32.768kHz20PPM9pF; LCSC C97605

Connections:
+1V8_MCU: C301.1, D305.1 (I/O), FL301.8 (DAT1_IN), FL301.15 (VCC), FL301.16 (RDATA_VCC), J301.1 (VCC), R302.1, R303.1, R304.1, U301.26 (VDD_NRF), U302.5 (EN), U302.6 (VDD); also elsewhere on the board
+3V0: J302.4 (VDD); also elsewhere on the board
/1_Power/BOOST_EN: U301.18 (P0.01); also elsewhere on the board
/1_Power/MCU_CURR_MON_COMP: U301.34 (P1.12/AIN5/CLK); also elsewhere on the board
/1_Power/NPM_SCL: R303.2, TP309.1, U301.30 (P1.08/EXTREF/CLK16M/CLK_); also elsewhere on the board
/1_Power/NPM_SDA: R304.2, TP310.1, U301.29 (P1.09); also elsewhere on the board
/2_Charging_Connections/CHG_DOCK_DET_1: U301.14 (_P1.03/NFC2/CLK); also elsewhere on the board
/2_Charging_Connections/CHG_DOCK_DET_2: U301.15 (P1.02/NFC1); also elsewhere on the board
/2_Charging_Connections/CHG_DOCK_DET_3: U301.22 (P1.05/AIN1); also elsewhere on the board
/2_Charging_Connections/CHG_DOCK_DET_4: U301.23 (P1.04/AIN0/CLK); also elsewhere on the board
/2_Charging_Connections/CHG_DOCK_EN_1: U301.31 (P0.04/CLK_); also elsewhere on the board
/2_Charging_Connections/CHG_DOCK_EN_2: U301.32 (P1.14/AIN7); also elsewhere on the board
/2_Charging_Connections/CHG_DOCK_EN_3: U301.33 (P1.13/AIN6_); also elsewhere on the board
/2_Charging_Connections/CHG_DOCK_EN_4: U301.35 (P1.11/AIN4/CLK); also elsewhere on the board
/2_Charging_Connections/CHG_DOCK_GLOBAL_FAULT: U301.17 (P0.00); also elsewhere on the board
/2_Charging_Connections/CHG_DOCK_UART_RX_1: U302.2 (S1); also elsewhere on the board
/2_Charging_Connections/CHG_DOCK_UART_RX_2: U302.9 (S2); also elsewhere on the board
/2_Charging_Connections/CHG_DOCK_UART_RX_3: U302.4 (S3); also elsewhere on the board
/2_Charging_Connections/CHG_DOCK_UART_RX_4: U302.7 (S4); also elsewhere on the board
/3_nRF Module & SDCard/JACK_DET: U301.19 (P0.02); also elsewhere on the board
/3_nRF Module & SDCard/MUX_A0: U301.11 (P2.04), U302.1 (A0)
/3_nRF Module & SDCard/MUX_A1: U301.10 (_P2.01/CLK), U302.10 (A1)
/3_nRF Module & SDCard/MUX_UART: TP308.1, U301.9 (P2.00), U302.8 (D)
/3_nRF Module & SDCard/SDCard_DET: FL301.1 (WP/CD), FL301.3 (DAT2_IN), J302.10 (DETECT_SWITCH), R302.2, U301.28 (P1.10)
/3_nRF Module & SDCard/SPI_SD_CLK_CONN: FL301.11 (CLK_EX), J302.5 (CLK), TP305.1
/3_nRF Module & SDCard/SPI_SD_CLK_MCU: FL301.6 (CLK_IN), U301.38 (P2.06/CLK)
/3_nRF Module & SDCard/SPI_SD_CS_CONN: FL301.13 (DAT3_EX), J302.2 (CD/DAT3^2)
/3_nRF Module & SDCard/SPI_SD_CS_MCU: FL301.4 (DAT3_IN), U301.37 (P2.10)
/3_nRF Module & SDCard/SPI_SD_D2_CONN: FL301.9 (DAT1_EX), FL301.14 (DAT2_EX), J302.1 (DAT2), J302.8 (DAT1)
/3_nRF Module & SDCard/SPI_SD_MISO_MCU: FL301.7 (DAT0_IN), FL301.10 (DAT0_EX), J302.7 (DAT0), TP306.1, U301.2 (P2.09)
/3_nRF Module & SDCard/SPI_SD_MOSI_CONN: FL301.12 (CMD_EX), J302.3 (CMD), TP304.1
/3_nRF Module & SDCard/SPI_SD_MOSI_MCU: FL301.5 (CMD_IN), U301.3 (P2.08)
/3_nRF Module & SDCard/SWD_CLK: D301.1 (I/O), J301.4 (SWCLK), TP301.1, U301.6 (SWDCLK)
/3_nRF Module & SDCard/SWD_IO: D302.1 (I/O), J301.2 (SWDIO), TP302.1, U301.5 (SWDIO)
/3_nRF Module & SDCard/SWD_O: D303.1 (I/O), J301.6 (SWO), U301.4 (P2.07)
/3_nRF Module & SDCard/SWD_RESET: D304.1 (I/O), J301.3 (~RESET), R301.1, TP303.1
/3_nRF Module & SDCard/TRIGGER_DIR: U301.20 (P1.07/AIN3); also elsewhere on the board
/3_nRF Module & SDCard/TRIGGER_SIGNAL: U301.21 (P1.06/AIN2); also elsewhere on the board
/3_nRF Module & SDCard/XL1: U301.25 (P1.00/XL1), Y201.2
/3_nRF Module & SDCard/XL2: U301.24 (P1.01/XL2), Y201.1
GND: C301.2, C302.2, D301.2 (GND), D302.2 (GND), D303.2 (GND), D304.2 (GND), D305.2 (GND), FL301.17 (EP_(GND)), J301.5 (GND), J302.6 (VSS), J302.9 (VSS), J302.P1 (SHIELD), J302.P2 (SHIELD), J302.P3 (SHIELD), J302.P4 (SHIELD), TP307.1, U301.1 (GND_1), U301.16 (GND_2), U301.27 (GND_3), U301.39 (GND_4), U302.3 (GND); also elsewhere on the board
unnamed: C302.1, R301.2, U301.7 (NRESET)

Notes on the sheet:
As only a small data packet with sensor-id and charging status will be sent over UART, the MUX is used to funnel the signals into one drain. The base can then open up the right source, when sensor was newly docked and await its transmission. When multiple sensors are docked, the sources are periodi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
SWD-TAG
UART from Docks channeled via MUX
MCU & STORAGE
MicroSD-CARD
EMI filter, ESD protection and Pull-ups for SD-Card
[A1:A0] 00 -> DOCK 1 (S1) 01 -> DOCK 2 (S2) 10 -> DOCK 3 (S3) 11 -> DOCK 4 (S4)
ESD-Protection

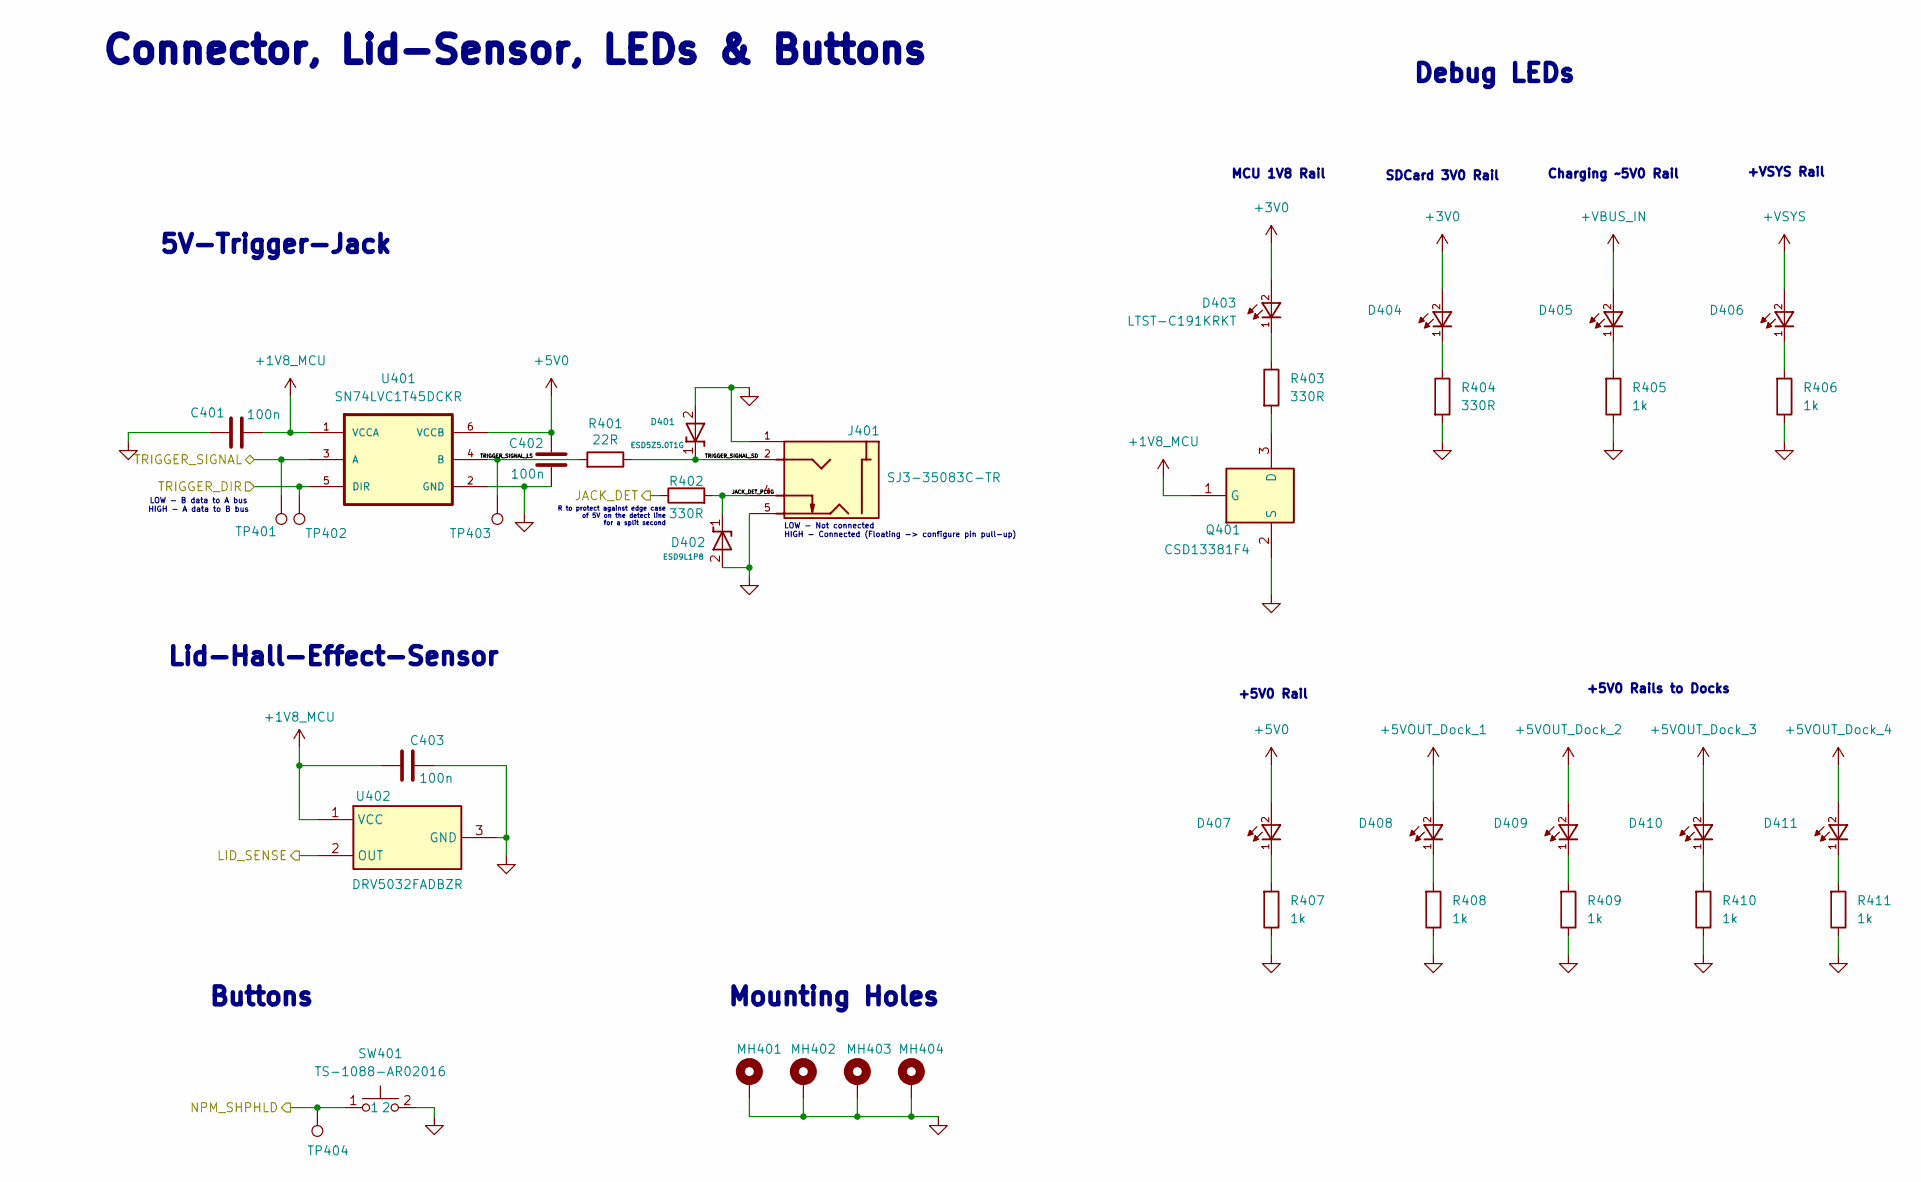
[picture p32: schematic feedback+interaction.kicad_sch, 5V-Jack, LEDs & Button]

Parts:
C401, C402: 100n; C_0402_1005Metric; Manufacturer_Part_Number CL05B104KB54PNC; LCSC C307331
C403: 100n; C_0402_1005Metric; Manufacturer_Part_Number CL05B104KO5NNNC; LCSC C1525
D401: ESD5Z5.0T1G; D_SOD-523_1; Manufacturer_Part_Number ESD5Z5.0T1G; LCSC C82044
D402: ESD9L1P8; D_SOD-882; Manufacturer_Part_Number ESD9L1P8; LCSC C6244607
D403, D404, D405, D406, D407, D408, D409, D410, D411: LTST-C191KRKT; Manufacturer_Part_Number LTST-C191KRKT; LCSC C125099
J401: SJ3-35083C-TR; SAMESKY_SJ3-35083C-TR; Manufacturer_Part_Number SJ3-35083C-TR
MH401, MH402, MH403, MH404: MountingHole_Pad; MountingHole_2.2mm_M2_Pad_Via
Q401: CSD13381F4; DFN100X60X35-3N; Manufacturer_Part_Number CSD13381F4; LCSC C179868
R401: 22R; R_0603_1608Metric; Manufacturer_Part_Number 0603WAF220JT5E; LCSC C23345
R402, R403, R404: 330R; R_0402_1005Metric; Manufacturer_Part_Number 0402WGF3300TCE; LCSC C25104
R405, R406, R407, R408, R409, R410, R411: 1k; R_0402_1005Metric; Manufacturer_Part_Number 0402WGF1001TCE; LCSC C11702
SW401: TS-1088-AR02016; SW_TS-1088-AR02016; Manufacturer_Part_Number TS-1088-AR02016; LCSC C720477
TP401, TP402, TP403, TP404: TestPoint_Pad_D1.0mm
U401: SN74LVC1T45DCKR; SOT-363_SC-70-6; Manufacturer_Part_Number SN74LVC1T45DCKR; LCSC C9382
U402: DRV5032FADBZR; SOT-23; Manufacturer_Part_Number DRV5032FADBZR; LCSC C140921

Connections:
+1V8_MCU: C401.2, C403.1, Q401.1 (G), U401.1 (VCCA), U402.1 (VCC); also elsewhere on the board
+3V0: D403.2, D404.2; also elsewhere on the board
+5V0: C402.1, D407.2, U401.6 (VCCB); also elsewhere on the board
+5VOUT_Dock_1: D408.2; also elsewhere on the board
+5VOUT_Dock_2: D409.2; also elsewhere on the board
+5VOUT_Dock_3: D410.2; also elsewhere on the board
+5VOUT_Dock_4: D411.2; also elsewhere on the board
+VBUS_IN: D405.2; also elsewhere on the board
+VSYS: D406.2; also elsewhere on the board
/1_Power/NPM_SHPHLD: SW401.1, TP404.1; also elsewhere on the board
/3_nRF Module & SDCard/JACK_DET: R402.1; also elsewhere on the board
/3_nRF Module & SDCard/LID_SENSE: U402.2 (OUT)
/3_nRF Module & SDCard/TRIGGER_DIR: TP402.1, U401.5 (DIR); also elsewhere on the board
/3_nRF Module & SDCard/TRIGGER_SIGNAL: TP401.1, U401.3 (A); also elsewhere on the board
/4_5V_Jack, Lid-Sensor, LEDs & Button/JACK_DET_PLUG: D402.1 (I/O), J401.4, R402.2
/4_5V_Jack, Lid-Sensor, LEDs & Button/TRIGGER_SIGNAL_LS: R401.1, TP403.1, U401.4 (B)
/4_5V_Jack, Lid-Sensor, LEDs & Button/TRIGGER_SIGNAL_SD: D401.1 (I/O), J401.2, R401.2
GND: C401.1, C402.2, C403.2, D401.2 (GND), D402.2 (GND), J401.1, J401.5, MH401.1, MH402.1, MH403.1, MH404.1, Q401.2 (S), R404.2, R405.2, R406.2, R407.2, R408.2, R409.2, R410.2, R411.2, SW401.2, U401.2 (GND), U402.3 (GND); also elsewhere on the board
unnamed: D403.1, R403.1
unnamed: D404.1, R404.1
unnamed: D405.1, R405.1
unnamed: D406.1, R406.1
unnamed: D407.1, R407.1
unnamed: D408.1, R408.1
unnamed: D409.1, R409.1
unnamed: D410.1, R410.1
unnamed: D411.1, R411.1
unnamed: Q401.3 (D), R403.2

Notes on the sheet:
SDCard 3V0 Rail
Mounting Holes
Buttons
+5V0 Rail
Connector, Lid-Sensor, LEDs & Buttons
5V-Trigger-Jack
R to protect against edge case of 5V on the detect line for a split second
Lid-Hall-Effect-Sensor
+VSYS Rail
MCU 1V8 Rail
LOW - Not connected HIGH - Connected (Floating -> configure pin pull-up)
Charging ~5V0 Rail
+5V0 Rails to Docks
Debug LEDs
LOW - B data to A bus HIGH - A data to B bus

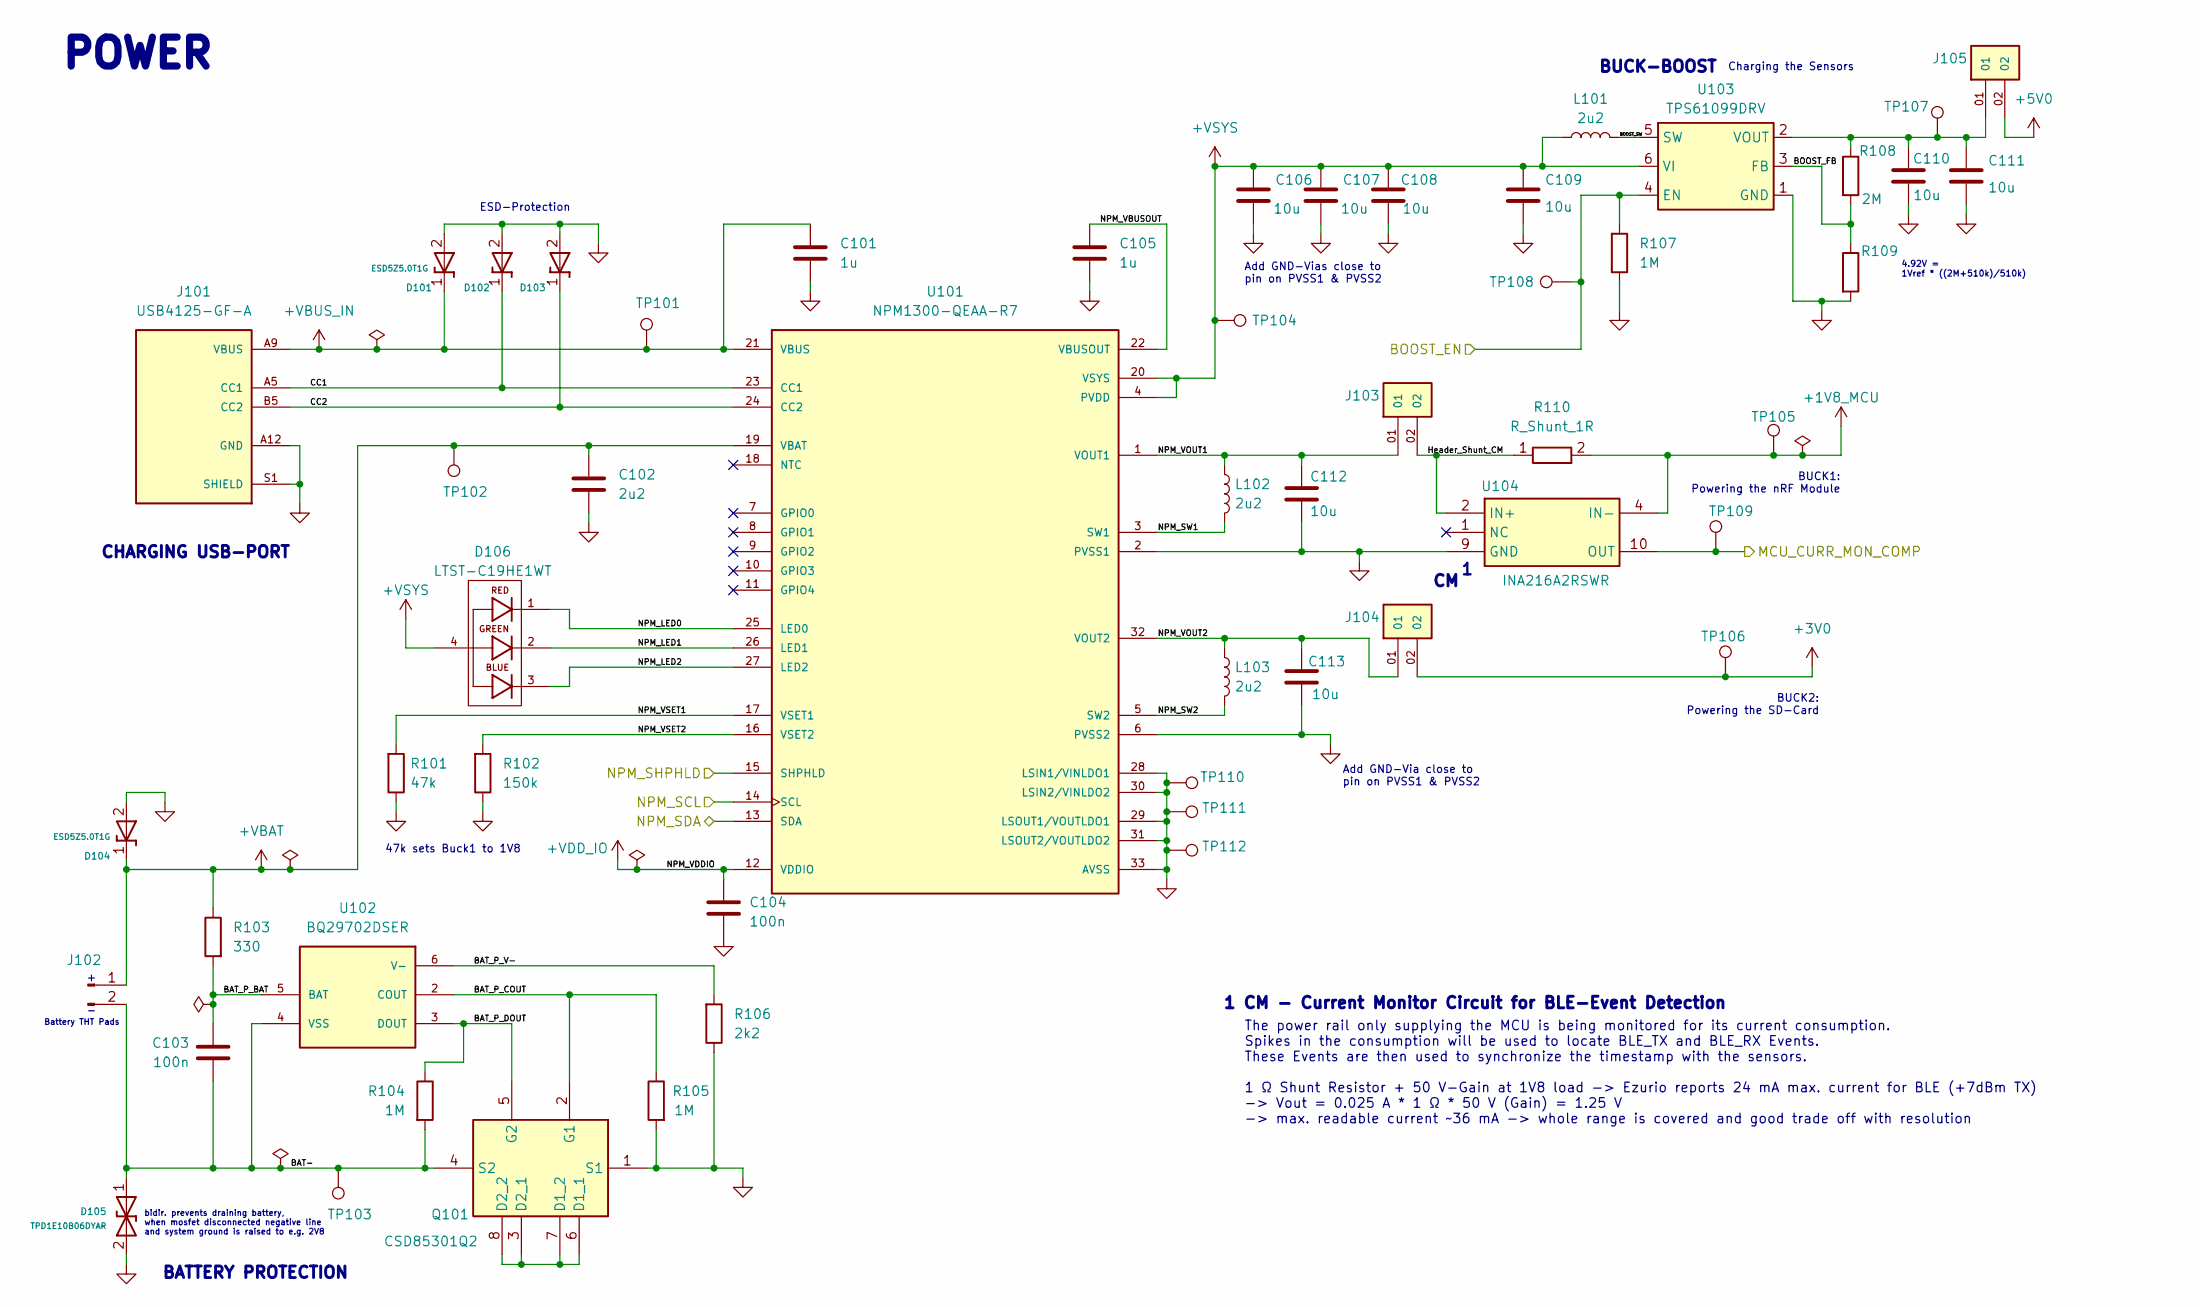
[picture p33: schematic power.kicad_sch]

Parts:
C101, C105: 1u; C_0402_1005Metric; Manufacturer_Part_Number CL05A105KA5NQNC; LCSC C52923
C102: 2u2; C_0402_1005Metric; Manufacturer_Part_Number CL05A225MQ5NSNC; LCSC C12530
C103, C104: 100n; C_0402_1005Metric; Manufacturer_Part_Number CL05B104KO5NNNC; LCSC C1525
C106, C107, C108, C109, C110, C111, C112, C113: 10u; C_0603_1608Metric; Manufacturer_Part_Number CL10A106MA8NRNC; LCSC C96446
D101, D102, D103, D104: ESD5Z5.0T1G; D_SOD-523_1; Manufacturer_Part_Number ESD5Z5.0T1G; LCSC C82044
D105: TPD1E10B06DYAR; D_SOD-523; Manufacturer_Part_Number TPD1E10B06DYAR; LCSC C3712135
D106: LTST-C19HE1WT; LED_LTST-C19HE1WT; Manufacturer_Part_Number LTST-C19HE1WT; LCSC C458749
J101: USB4125-GF-A; GCT_USB4125-GF-A_REVA2; Manufacturer_Part_Number USB4125-GF-A; LCSC C3151650
J102: Conn_01x02_Pin; SolderWire-0.5sqmm_1x02_P4.6mm_D0.9mm_OD2.1mm
J103, J104, J105: SAMTEC_MTSW-101-X-X-D-X; Manufacturer_Part_Number MTSW-101-07-T-D-240
L101, L102, L103: 2u2; L_0603_1608Metric; Manufacturer_Part_Number LSCNB1608HKT2R2MD; LCSC C6079477
Q101: CSD85301Q2; Manufacturer_Part_Number CSD85301Q2; LCSC C544396
R101: 47k; R_0402_1005Metric; Manufacturer_Part_Number 0402WGF4702TCE; LCSC C25792
R102: 150k; R_0402_1005Metric; Manufacturer_Part_Number 0402WGF1503TCE; LCSC C25755
R103: 330; R_0402_1005Metric; Manufacturer_Part_Number 0402WGF3300TCE; LCSC C25104
R104, R105, R107: 1M; R_0402_1005Metric; Manufacturer_Part_Number 0402WGF1004TCE; LCSC C26083
R106: 2k2; R_0402_1005Metric; Manufacturer_Part_Number 0402WGF2201TCE; LCSC C25879
R108: 2M; R_0603_1608Metric; Manufacturer_Part_Number 0603WAF2004T5E; LCSC C22976
R109: 510k; R_0603_1608Metric; Manufacturer_Part_Number 0603WAF5103T5E; LCSC C23192
R110: R_Shunt_1R; R_0402_1005Metric; Manufacturer_Part_Number RLP73K1E1R0FTDF; LCSC C2074826
TP101, TP102, TP103, TP104, TP105, TP106, TP107, TP108, TP109, TP110, TP111, TP112: TestPoint_Pad_D1.0mm
U101: NPM1300-QEAA-R7; QFN50P500X500X90-33N; Manufacturer_Part_Number NPM1300-QEAA-R7; LCSC C7501206
U102: BQ29702DSER; WSON-6_1.5x1.5mm_P0.5mm; Manufacturer_Part_Number BQ29702DSER; LCSC C2872632
U103: TPS61099DRV; WSON-6-1EP_2x2mm_P0.65mm_EP1x1.6mm; Manufacturer_Part_Number TPS61099DRVR; LCSC C2842395
U104: INA216A2RSWR; Texas_RSW0010A_UQFN-10_1.4x1.8mm_P0.4mm; Manufacturer_Part_Number INA216A2RSWR; LCSC C2653823

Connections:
+1V8_MCU: R110.2, TP105.1, U104.4 (IN-), U104.5 (IN-); also elsewhere on the board
+3V0: J104.02, TP106.1; also elsewhere on the board
+5V0: J105.02; also elsewhere on the board
+VBAT: C102.1, D104.1 (I/O), J102.1, R103.1, TP102.1, U101.19 (VBAT)
+VBUS_IN: C101.1, D101.1 (I/O), J101.A9 (VBUS), J101.B9 (VBUS), TP101.1, U101.21 (VBUS); also elsewhere on the board
+VDD_IO: C104.1, U101.12 (VDDIO)
+VSYS: C106.1, C107.1, C108.1, C109.1, D106.4, L101.1, TP104.1, U101.4 (PVDD), U101.20 (VSYS), U103.6 (VI); also elsewhere on the board
/1_Power/BAT-: C103.2, D105.1 (I/O), J102.2, Q101.4 (S2), R104.1, TP103.1, U102.4 (VSS)
/1_Power/BAT_P_BAT: C103.1, R103.2, U102.5 (BAT)
/1_Power/BAT_P_COUT: Q101.2 (G1), R105.2, U102.2 (COUT)
/1_Power/BAT_P_DOUT: Q101.5 (G2), R104.2, U102.3 (DOUT)
/1_Power/BAT_P_V-: R106.1, U102.6 (V-)
/1_Power/BOOST_EN: R107.1, TP108.1, U103.4 (EN); also elsewhere on the board
/1_Power/BOOST_FB: R108.1, R109.2, U103.3 (FB)
/1_Power/BOOST_SW: L101.2, U103.5 (SW)
/1_Power/CC1: D102.1 (I/O), J101.A5 (CC1), U101.23 (CC1)
/1_Power/CC2: D103.1 (I/O), J101.B5 (CC2), U101.24 (CC2)
/1_Power/Header_Shunt_CM: J103.02, R110.1, U104.2 (IN+), U104.3 (IN+)
/1_Power/MCU_CURR_MON_COMP: TP109.1, U104.10 (OUT); also elsewhere on the board
/1_Power/NPM_LED0: D106.1, U101.25 (LED0)
/1_Power/NPM_LED1: D106.2, U101.26 (LED1)
/1_Power/NPM_LED2: D106.3, U101.27 (LED2)
/1_Power/NPM_SCL: U101.14 (SCL); also elsewhere on the board
/1_Power/NPM_SDA: U101.13 (SDA); also elsewhere on the board
/1_Power/NPM_SHPHLD: U101.15 (SHPHLD); also elsewhere on the board
/1_Power/NPM_SW1: L102.2, U101.3 (SW1)
/1_Power/NPM_SW2: L103.2, U101.5 (SW2)
/1_Power/NPM_VBUSOUT: C105.1, U101.22 (VBUSOUT)
/1_Power/NPM_VOUT1: C112.1, J103.01, L102.1, U101.1 (VOUT1)
/1_Power/NPM_VOUT2: C113.1, J104.01, L103.1, U101.32 (VOUT2)
/1_Power/NPM_VSET1: R101.1, U101.17 (VSET1)
/1_Power/NPM_VSET2: R102.1, U101.16 (VSET2)
GND: C101.2, C102.2, C104.2, C105.2, C106.2, C107.2, C108.2, C109.2, C110.2, C111.2, C112.2, C113.2, D101.2 (GND), D102.2 (GND), D103.2 (GND), D104.2 (GND), D105.2 (GND), J101.A12 (GND), J101.B12 (GND), J101.S1 (SHIELD), J101.S2 (SHIELD), J101.S3 (SHIELD), J101.S4 (SHIELD), Q101.1 (S1), R101.2, R102.2, R105.1, R106.2, R107.2, R109.1, TP110.1, TP111.1, TP112.1, U101.2 (PVSS1), U101.6 (PVSS2), U101.28 (LSIN1/VINLDO1), U101.29 (LSOUT1/VOUTLDO1), U101.30 (LSIN2/VINLDO2), U101.31 (LSOUT2/VOUTLDO2), U101.33 (AVSS), U103.1 (GND), U103.7 (GND), U104.9 (GND); also elsewhere on the board
unnamed: Q101.3 (D2_1), Q101.6 (D1_1), Q101.7 (D1_2), Q101.8 (D2_2)
unnamed: C110.1, C111.1, J105.01, R108.2, TP107.1, U103.2 (VOUT)

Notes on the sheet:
POWER
bidir. prevents draining battery, when mosfet disconnected negative line and system ground is raised to e.g. 2V8
Charging the Sensors
4.92V = 1Vref * ((2M+510k)/510k)
BUCK1: Powering the nRF Module
47k sets Buck1 to 1V8
CHARGING USB-PORT
ESD-Protection
Battery THT Pads
Add GND-Vias close to pin on PVSS1 & PVSS2
1 CM - Current Monitor Circuit for BLE-Event Detection
BUCK2: Powering the SD-Card
Add GND-Via close to pin on PVSS1 & PVSS2
BATTERY PROTECTION
BUCK-BOOST
The power rail only supplying the MCU is being monitored for its current consumption. Spikes in the consumption will be used to locate BLE_TX and BLE_RX Events. These Events are then used to synchronize the timestamp with the sensors. 1 Ω Shunt Resistor + 50 V-Gain at 1V8 load -> Ezurio reports 24 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

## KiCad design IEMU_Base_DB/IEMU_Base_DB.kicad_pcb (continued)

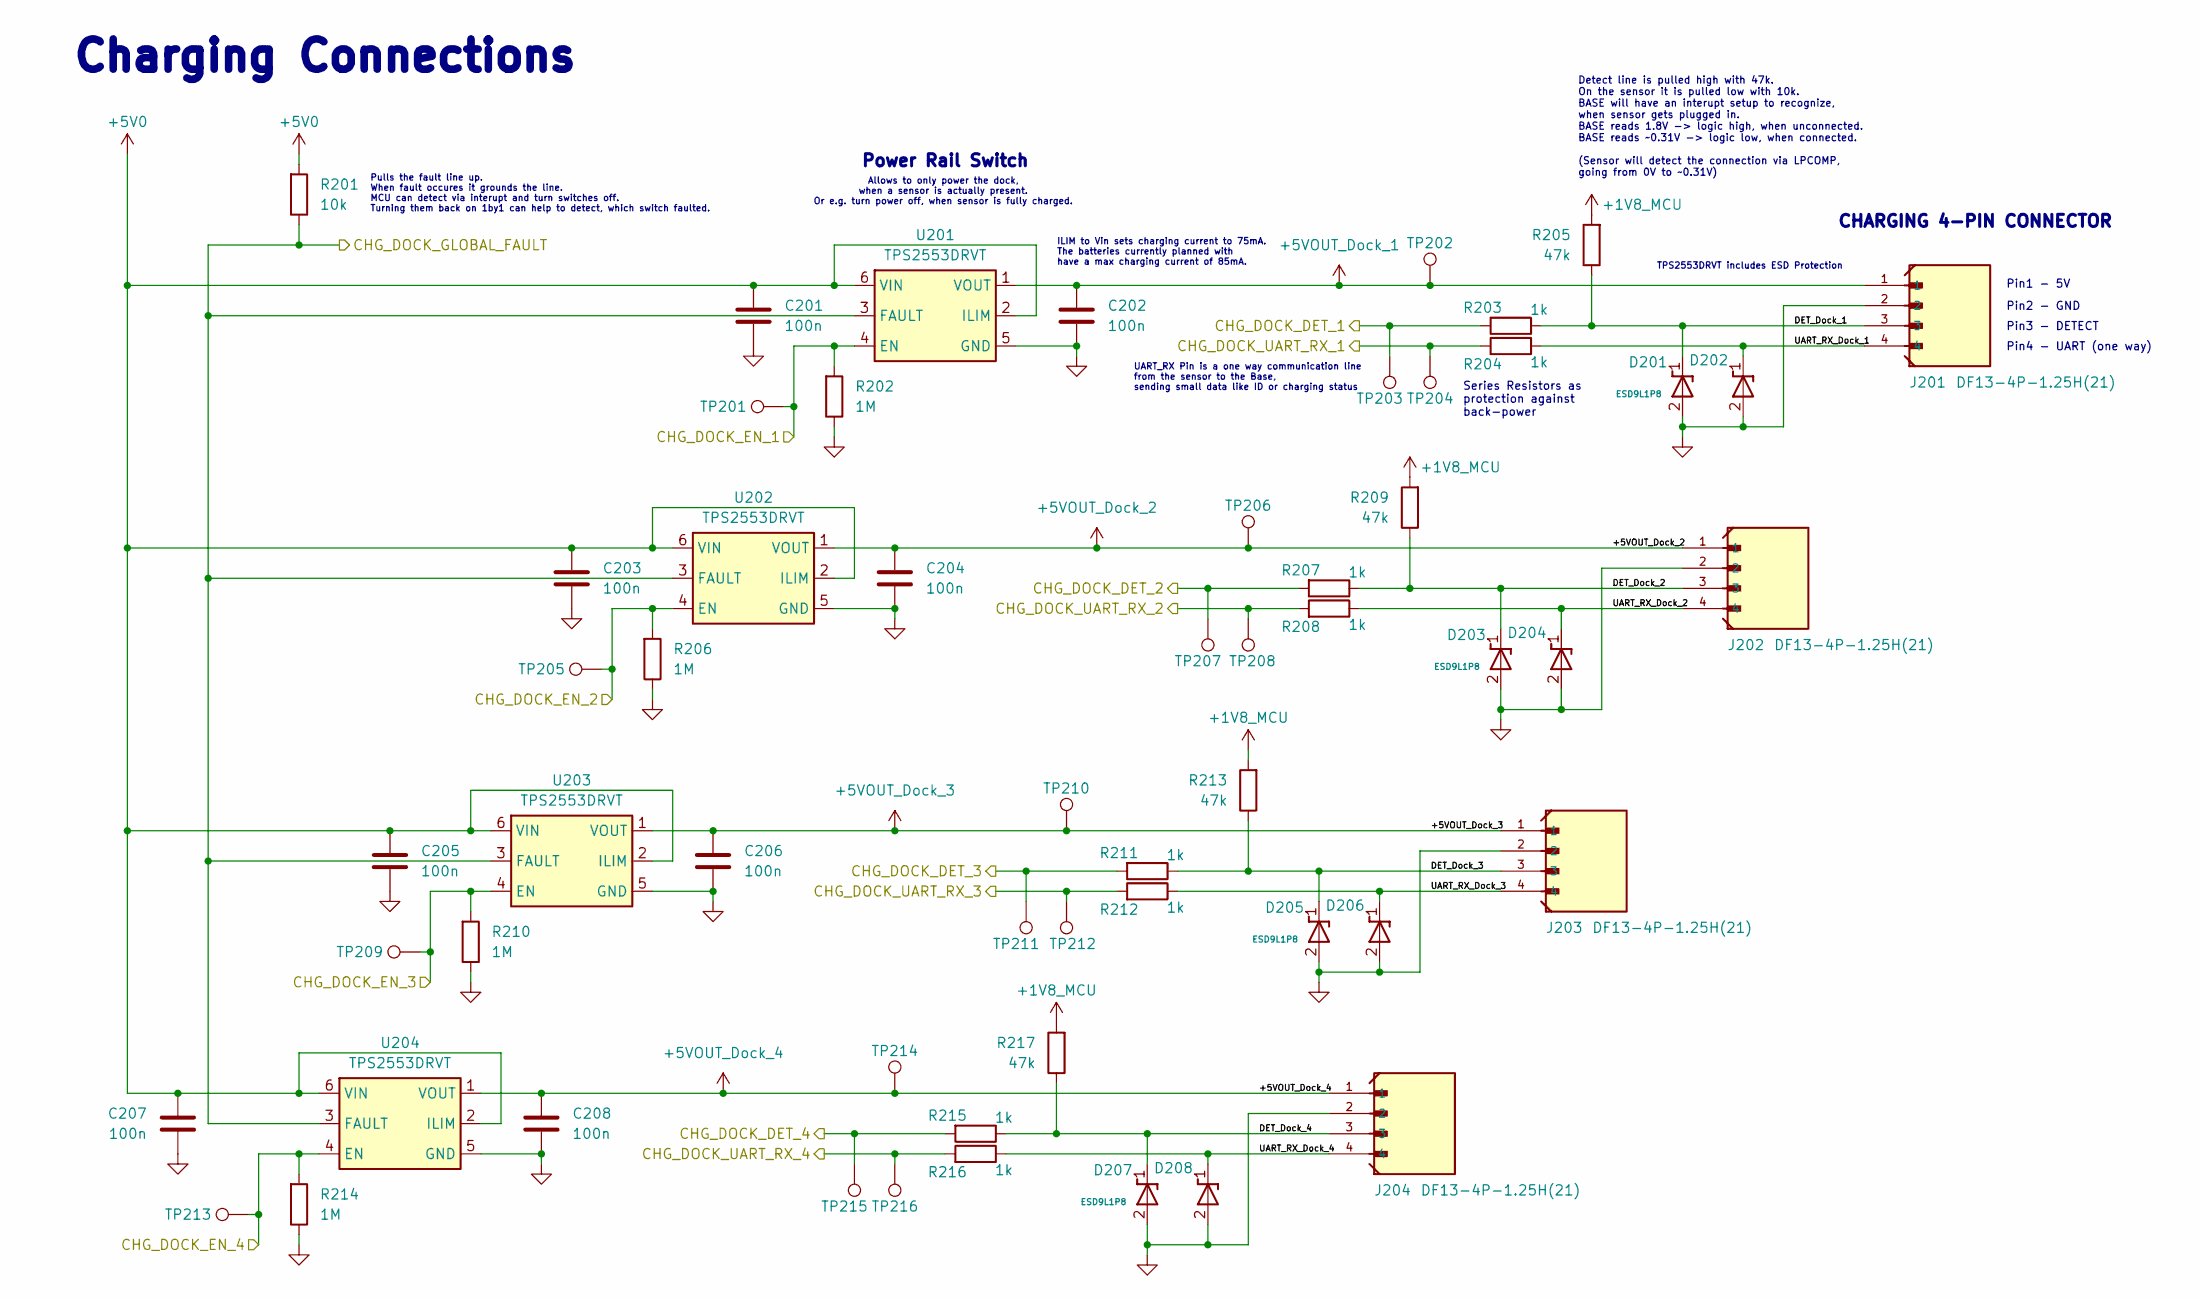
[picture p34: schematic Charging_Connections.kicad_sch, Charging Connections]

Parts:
C201, C202, C203, C204, C205, C206, C207, C208: 100n; C_0402_1005Metric; Manufacturer_Part_Number CL05B104KB54PNC; LCSC C307331
D201, D202, D203, D204, D205, D206, D207, D208: ESD9L1P8; D_SOD-882; Manufacturer_Part_Number ESD9L1P8; LCSC C6244607
J201, J202, J203, J204: DF13-4P-1.25H(21); Manufacturer_Part_Number DF13-4P-1.25H(21); LCSC C597872
R201: 10k; R_0402_1005Metric; Manufacturer_Part_Number 0402WGF1002TCE; LCSC C25744
R202, R206, R210, R214: 1M; R_0402_1005Metric; Manufacturer_Part_Number 0402WGF1004TCE; LCSC C26083
R203, R204, R207, R208, R211, R212, R215, R216: 1k; R_0402_1005Metric; Manufacturer_Part_Number 0402WGF1001TCE; LCSC C11702
R205, R209, R213, R217: 47k; R_0402_1005Metric; Manufacturer_Part_Number 0402WGF4702TCE; LCSC C25792
TP201, TP202, TP203, TP204, TP205, TP206, TP207, TP208, TP209, TP210, TP211, TP212, TP213, TP214, TP215, TP216: TestPoint_Pad_D1.0mm
U201, U202, U203, U204: TPS2553DRVT; WSON-6-1EP_2x2mm_P0.65mm_EP1x1.6mm; Manufacturer_Part_Number TPS2553DRVT; LCSC C2871420

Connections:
+1V8_MCU: R205.1, R209.1, R213.1, R217.1; also elsewhere on the board
+5V0: C201.1, C203.1, C205.1, C207.1, R201.1, U201.2 (ILIM), U201.6 (VIN), U202.2 (ILIM), U202.6 (VIN), U203.2 (ILIM), U203.6 (VIN), U204.2 (ILIM), U204.6 (VIN); also elsewhere on the board
+5VOUT_Dock_1: C202.1, J201.1, TP202.1, U201.1 (VOUT); also elsewhere on the board
+5VOUT_Dock_2: C204.1, J202.1, TP206.1, U202.1 (VOUT); also elsewhere on the board
+5VOUT_Dock_3: C206.1, J203.1, TP210.1, U203.1 (VOUT); also elsewhere on the board
+5VOUT_Dock_4: C208.1, J204.1, TP214.1, U204.1 (VOUT); also elsewhere on the board
/2_Charging_Connections/CHG_DOCK_DET_1: R203.1, TP203.1; also elsewhere on the board
/2_Charging_Connections/CHG_DOCK_DET_2: R207.1, TP207.1; also elsewhere on the board
/2_Charging_Connections/CHG_DOCK_DET_3: R211.1, TP211.1; also elsewhere on the board
/2_Charging_Connections/CHG_DOCK_DET_4: R215.1, TP215.1; also elsewhere on the board
/2_Charging_Connections/CHG_DOCK_EN_1: R202.1, TP201.1, U201.4 (EN); also elsewhere on the board
/2_Charging_Connections/CHG_DOCK_EN_2: R206.1, TP205.1, U202.4 (EN); also elsewhere on the board
/2_Charging_Connections/CHG_DOCK_EN_3: R210.1, TP209.1, U203.4 (EN); also elsewhere on the board
/2_Charging_Connections/CHG_DOCK_EN_4: R214.1, TP213.1, U204.4 (EN); also elsewhere on the board
/2_Charging_Connections/CHG_DOCK_GLOBAL_FAULT: R201.2, U201.3 (FAULT), U202.3 (FAULT), U203.3 (FAULT), U204.3 (FAULT); also elsewhere on the board
/2_Charging_Connections/CHG_DOCK_UART_RX_1: R204.1, TP204.1; also elsewhere on the board
/2_Charging_Connections/CHG_DOCK_UART_RX_2: R208.1, TP208.1; also elsewhere on the board
/2_Charging_Connections/CHG_DOCK_UART_RX_3: R212.1, TP212.1; also elsewhere on the board
/2_Charging_Connections/CHG_DOCK_UART_RX_4: R216.1, TP216.1; also elsewhere on the board
/2_Charging_Connections/DET_Dock_1: D201.1 (I/O), J201.3, R203.2, R205.2
/2_Charging_Connections/DET_Dock_2: D203.1 (I/O), J202.3, R207.2, R209.2
/2_Charging_Connections/DET_Dock_3: D205.1 (I/O), J203.3, R211.2, R213.2
/2_Charging_Connections/DET_Dock_4: D207.1 (I/O), J204.3, R215.2, R217.2
/2_Charging_Connections/UART_RX_Dock_1: D202.1 (I/O), J201.4, R204.2
/2_Charging_Connections/UART_RX_Dock_2: D204.1 (I/O), J202.4, R208.2
/2_Charging_Connections/UART_RX_Dock_3: D206.1 (I/O), J203.4, R212.2
/2_Charging_Connections/UART_RX_Dock_4: D208.1 (I/O), J204.4, R216.2
GND: C201.2, C202.2, C203.2, C204.2, C205.2, C206.2, C207.2, C208.2, D201.2 (GND), D202.2 (GND), D203.2 (GND), D204.2 (GND), D205.2 (GND), D206.2 (GND), D207.2 (GND), D208.2 (GND), J201.2, J202.2, J203.2, J204.2, R202.2, R206.2, R210.2, R214.2, U201.5 (GND), U201.7 (GND), U202.5 (GND), U202.7 (GND), U203.5 (GND), U203.7 (GND), U204.5 (GND), U204.7 (GND); also elsewhere on the board

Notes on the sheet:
Series Resistors as protection against back-power
Allows to only power the dock, when a sensor is actually present. Or e.g. turn power off, when sensor is fully charged.
ILIM to Vin sets charging current to 75mA. The batteries currently planned with have a max charging current of 85mA.
Pin2 - GND
Charging Connections
Detect line is pulled high with 47k. On the sensor it is pulled low with 10k. BASE will have an interupt setup to recognize, when sensor gets plugged in. BASE reads 1.8V -> logic high, when unconnected. BASE reads ~0.31V -> logic low, when connected. (Sensor will detect the connection via LPCOMP, g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
TPS2553DRVT includes ESD Protection
Pin4 - UART (one way)
Pin3 - DETECT
UART_RX Pin is a one way communication line from the sensor to the Base, sending small data like ID or charging status
CHARGING 4-PIN CONNECTOR
Pulls the fault line up. When fault occures it grounds the line. MCU can detect via interupt and turn switches off. Turning them back on 1by1 can help to detect, which switch faulted.
Pin1 - 5V
Power Rail Switch

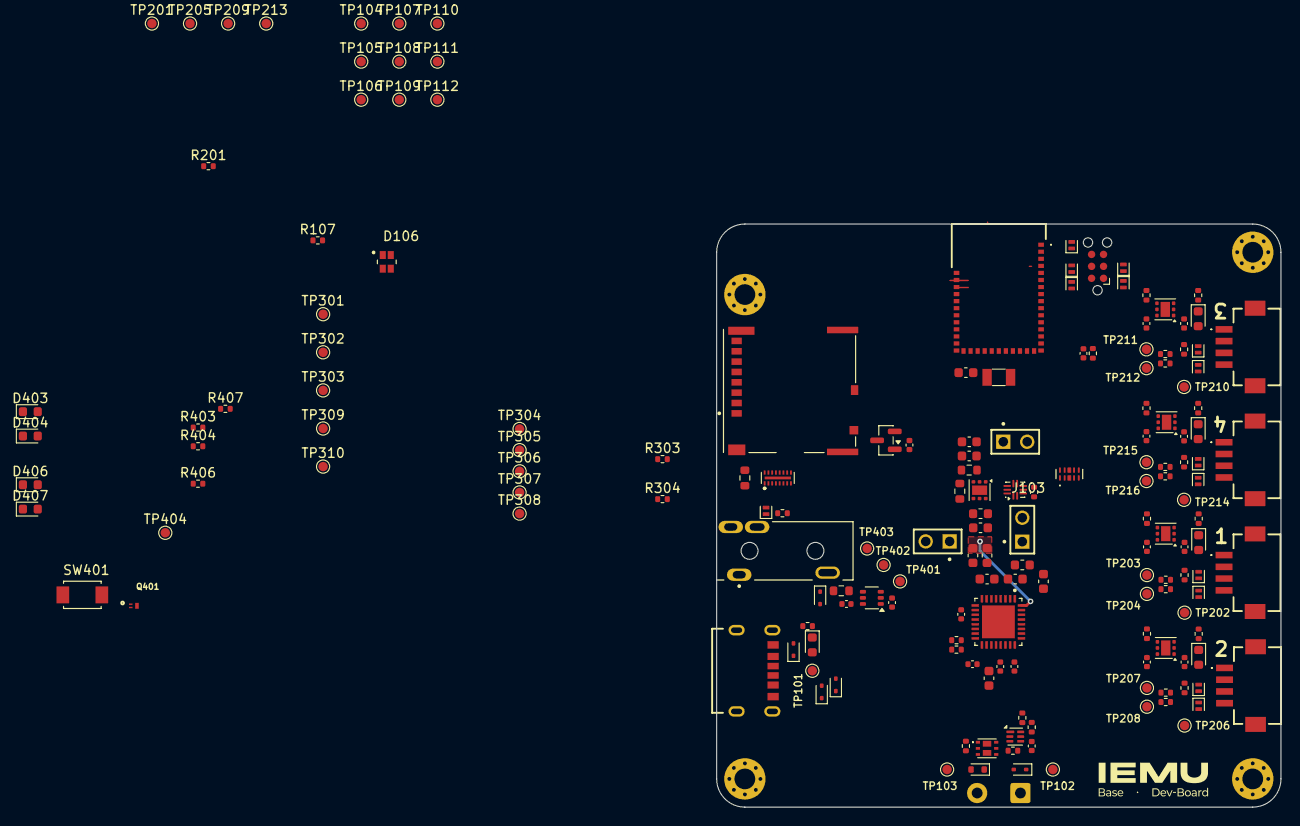
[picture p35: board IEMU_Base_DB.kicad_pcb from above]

Board: 4 copper layers, 60.0 x 62.0 mm, 176 parts (0 on the bottom side), 95 nets.

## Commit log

2026-05-08 initial commit of the IEMU-Sensor and Base Kicad files
    [453-00001C.stp, 503398-1892.step, BQ29702DSER.step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]
2026-05-08 changed reusable_libraries folder to name IEMU_Shared_Libraries and also introduced more relative paths for the library components to make the links more robust
    [453-00001C.stp, 503398-1892.step, BQ29702DSER.step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]
2026-05-08 added hall effect sensor for lid detection
    [IEMU_Base_DB.kicad_sch, feedback+interaction.kicad_sch, mcu+peripherals.kicad_sch]
2026-05-08 corrected mcu-sheet file name
    [IEMU_Base_DB.kicad_sch, feedback+interaction.kicad_sch, mcu+sd.kicad_sch]
2026-05-08 swapped the coin cell vibration actuator pins
    [feedback+interaction.kicad_sch]
2026-05-08 added schematic pdf for the sensor
2026-06-03 implemented changes from the review with TF and fixed lost parts in the library
    [Charging_Connections.kicad_sch, DF13-4P-1.25H_21_.stp, IEMU_Base_DB.kicad_sch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]
2026-06-03 finished schematic revision based on TF-review by implementing sensor schematic too
    [feedback+interaction.kicad_sch, mcu+peripherals.kicad_sch, power.kicad_sch]
2026-06-22 created the layout for the sensor (not finished)
    [IEMU_Sensor_DB.kicad_pcb, feedback+interaction.kicad_sch, mcu+peripherals.kicad_sch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]
2026-06-24 finished layout for sensor
    [IEMU_Sensor_DB.kicad_pcb, INA216A2RSWR.STEP, mcu+peripherals.kicad_sch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]
2026-06-25 layout of base and some fixes on the sensor layout
    [Charging_Connections.kicad_sch, IEMU_Base_DB.kicad_pcb, IEMU_Sensor_DB.kicad_pcb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]
2026-07-05 added header pins
    [IEMU_Base_DB.kicad_pcb, MTMM-101-05-T-D-225.stp, MTMM-102-05-T-S-255.stp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]
2026-09-22 commit after component purchase
    [EVP-AWED4A.step, IEMU_Sensor_DB.csv, IEMU_Sensor_DB.kicad_pcb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]
2026-09-22 created gerbers and drills
    [IEMU_Sensor_DB-B_Cu.gbr, IEMU_Sensor_DB-B_Mask.gbr, IEMU_Sensor_DB-Edge_Cuts.gbr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]
2026-10-09 added vibration and core eval boards
2026-10-10 added memory board and refined vibration board details
2026-10-14 added and finished power-eval-board
2026-10-14 added logo on the power board
2026-10-15 added the carrier board
2026-10-17 final changes before order, including a clutch swd connector change

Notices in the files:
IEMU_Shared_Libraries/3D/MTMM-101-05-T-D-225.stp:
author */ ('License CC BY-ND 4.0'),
